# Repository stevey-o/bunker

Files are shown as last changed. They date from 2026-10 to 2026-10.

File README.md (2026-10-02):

# MINUTEMAN — aluminum slide-in camper shell

A rugged aluminum truck-camper **shell** for a Ford F-350 that provides the protected space and
attachment infrastructure while letting the owner decide what the camper eventually becomes.

**Status: v0.1 — envelope only.** No structural frame yet. Nothing here is engineering-validated;
CAD appearance is not engineering validation.

## Start here

| | |
|---|---|
| Spec (authoritative) | [`PROJECT_HANDOFF.md`](PROJECT_HANDOFF.md) |
| Design decisions | [`decisions/`](decisions/) |
| v0.1 dimensions | [`camper_versions/minuteman_v0.1_envelope/DIMENSIONS.md`](camper_versions/minuteman_v0.1_envelope/DIMENSIONS.md) |
| Truck measurement sheet | [`truck_data/measurement_templates/f350_measurement_sheet.md`](truck_data/measurement_templates/f350_measurement_sheet.md) |
| Assumptions & statuses | [`engineering/assumptions.md`](engineering/assumptions.md) |
| Renderings | [`3D_renderings/`](3D_renderings/) |
| Drawings (ANSI C, ASME Y14 style, MM-A01..A05) | [`drawings/`](drawings/) · [standards used](reference/drafting_standards.md) |
| Truck data and sources | [`truck_data/README.md`](truck_data/README.md) |

## Headline numbers (v0.1, estimates)

- **97" long** lower body (fills a 2011 F-350 8 ft bed with the tailgate closed, ADR 0004); 121" overall with the nose.
- Interior standing height **80"** (6'7"+), ground-to-roof **~10'7"** on a 2011 F-350 4x4 — tall, not low-profile.
- Dry weight estimate **985–1,231 lb excluding jacks**, over the 850–950 lb target. Jacks add 100–140 lb.
- Shell material cost estimate **$4,402–8,735 excluding jacks and tooling** vs. a $4–6k target. Jacks add $900–1,600.
- **Truck fit** ([fit study](truck_data/fit_study.md)): 8 ft F-350 OK (check payload sticker); 6.75 ft F-350 with tailgate down, F-150 5.5 ft and every Tacoma **fail** (CG behind axle, geometry, or payload).
- Each +1" of interior height costs ~6–7 lb and ~$26–50.

Full reports: [`bom/weight_report.md`](bom/weight_report.md), [`bom/cost_report.md`](bom/cost_report.md).

## Next physical action

Print [`f350_measurement_sheet.pdf`](truck_data/measurement_templates/f350_measurement_sheet.pdf), measure
the truck, update `cad/config/dimensions.json`, run `make all`.

## Building the outputs

```
make setup   # once
make all     # sync config, render, drawings, reports, validate
```

Requires OpenSCAD (`brew install --cask openscad@snapshot`; the stable `openscad` cask was disabled by
Homebrew on 2026-09-01 for failing Gatekeeper) and Python 3.9+.
`cad/config/dimensions.json` is the single source of truth; everything else is regenerated from it.

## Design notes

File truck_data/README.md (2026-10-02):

# Truck data

All truck values live in `cad/config/dimensions.json` (`truck` = 2011 F-350 base, `truck_variants` = per
truck overrides). This page records **where each number came from**. Accessed 2026-10-01.

## 2011 Ford F-350 Super Duty (design truck)

| Value | Used | Source / basis | Confidence |
|---|---|---|---|
| Bed length at floor, 8 ft / 6.75 ft | 98.0 / 81.8 in | Edmunds 2011 F-350 specs; cars.com (98 in) | published |
| Wheelbase, crew cab 6.75 / 8 ft | 156.2 / 172.4 in | Ford 2011 RV & Trailer Towing Guide, slide-in camper chart | official |
| Max camper cargo, 4x4 SRW crew 156.2 in WB | 1,650-2,905 lb by engine | Ford 2011 RV & Trailer Towing Guide p.13 (Camper Pkg 471 required) | official |
| Max camper cargo, 4x4 SRW crew 172.4 in WB | 1,438-3,002 lb by engine | same | official |
| Ground to top of closed tailgate | 59-60 in (F-350 SRW) | same guide, 5th-wheel tailgate clearance table | official |
| Inside box height | 20.0 in | ford-trucks.com 2011 spec summary; cars.com (20 in) | published |
| Between wheelhouses | 50.9 in | ford-trucks.com 2011 spec summary; cars.com (51 in) | published |
| Tailgate width | 61 in | ford-trucks.com spec summary (search excerpt; page blocked) | unconfirmed |
| Ground to bed floor | 39.5 in | 59.5 tailgate height − 20.0 box depth; 4x4 unloaded upper bound | derived |
| Cab roof above bed floor | 41.5 in | 80.8 in overall height (iseecars, crew 4x4) − 39.5 | derived |
| Rear axle aft of bed front wall | 35.0 (6.75) / 51.2 (8) in | Wheelbase difference = bed difference, so axle-to-tailgate is constant; Ford cab-to-axle 40 / 56.2 in (quoted from a Ford manual on a ford-trucks.com forum) less ~5.5 in cab gap + wall | derived, **measure** |
| Inside width at floor/top, rail width, wheel-well height/length | 66 / 6.5 / 10.5 / 34 in | No reliable 2011 figure found (2023+ Super Duty max inside width 66.9 in) | **estimate, measure** |

Ford's guidance (2011 guide p.13): camper CG data for each qualifying truck is printed on the **Consumer
Information Sheet** in the glovebox; trucks that do not qualify are marked "not recommended for camper use."
Ford also recommends a dimensionally stable spacer block between the bed headboard and the camper floor.

## Half-ton (fit study only)

Published bed data (armorthane.com truck bed dimension chart, from maker spec sheets):

| Truck | Box lengths at floor | Between wells | Depth | Notes |
|---|---|---|---|---|
| Ford F-150 (2021+) | 67.1 / 78.9 / 97.6 in | 50.6 | 21.4 | modeled as F150_55 / F150_65 |
| Chevrolet Silverado 1500 (2019+) | 69.9 / 79.4 / 98.2 | 50.6 | 22.4 | deeper box: body underside would clash |
| Ram 1500 (2019+) | 67.4 / 76.3 | 51.0 | 21.4-21.5 | tailgate opening 60.0 |
| Toyota Tundra (2022+) | 65.6 / 77.6 / 96.5 | 48.7 | 20.9 | tub base 49.4 does **not** fit between wells |

Payload: typical crew-cab 4x4 half-tons ~1,300-2,000 lb; the highest 2026 advertised figure is 2,440 lb (F-150).
Options can remove 600-700 lb of capacity on otherwise identical trucks (theweeklydriver.com, tfltruck.com).
Ford's 2011 guide allows F-150 campers only with the Heavy-Duty Payload Package (option 627).
**Estimates in the model:** bed floor height 35 in, cab roof 42 in above bed, tailgate opening 60 in, axle
positions (wheelbase difference = bed difference; absolute value not sourced).

## Toyota Tacoma (fit study only)

| Generation | Box lengths | Between wells | Depth | Payload |
|---|---|---|---|---|
| 2005-2015 (2nd) | ~60.5 / ~73.5 in | 41.5 | ~18 | — |
| 2016-2023 (3rd), modeled | 60.5 / 73.7 | 41.5 | 19.1 | 1,050-1,445 lb (2021) |
| 2024+ (4th) | 60.3 / 73.5 | 44.7 | 20.2 | up to 1,705 lb (5 ft, gas) |

Sources: armorthane.com chart; tustintoyota.com 2026 bed specs; kimboliving.com Tacoma bed dimensions by year;
earnhardttoyota.com 2021 guide. Truck Camper Adventure notes the Tacoma's axle sits far forward relative to the
bed, so a camper's CG generally cannot be brought over or ahead of it.
**Estimates in the model:** bed floor 33 in, cab roof 37.5 in above bed, tailgate opening 53 in, axle position.

## Camper CG and overhang guidance
- Truck Camper Adventure, "Truck Camper Center of Gravity: Getting it Right": CG in front of the rear axle;
  roughly 10-20% of camper weight on the front axle.
- Northern Lite fit guide: measure bed front wall to rear-axle center; the camper CG must be forward of that distance.
- Owner forums (Wander the West, Expedition Portal): campers that overhang the bed generally require the
  tailgate removed; long-bed campers on short beds move the CG behind the axle.
- Tailgates are typically rated ~200-500 lb and cables are rarely rated (SlashGear). Never a camper support.

## Files
- `fit_study.md`, `fit_matrix.csv`: generated verdicts per truck.
- `measurement_templates/f350_measurement_sheet.pdf`: the next physical action.
- `ford_f350/README.md`: notes specific to the owner's truck.

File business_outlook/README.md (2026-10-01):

# Business outlook

MINUTEMAN is first a personal build. This page records whether it could become a product. Each section
is short and honest: v0.1 has **no market validation**.

## Positioning
A DIY-buildable, open-interior aluminum hard-side shell for full-size trucks, sold as plans and/or a kit.
It sits below commercial empty shells ($17-21k, `competitors/modular_shells.md`) in cash cost and above
them in owner effort.

## Target customer
Tall people (6'4"+) who can't stand in most campers; owners who want to configure their own interior;
people with garage space and the patience to learn aluminum welding. Unvalidated.

## Market questions
- How many buyers would build from plans vs. pay for a kit vs. pay for a finished shell?
- Is "tall standing room" a real segment or one owner's need?
- Would buyers trust a DIY-welded structure on the highway? (Liability shapes everything here.)

## Manufacturing options
1. Plans only (lowest liability, lowest revenue).
2. Cut kit: CNC-cut sheet and pre-cut tube, owner assembles.
3. Kit with shop-welded nodes (removes the novice-welding risk).
4. Finished shell (requires a facility, certification questions, real insurance).

## Pricing model
Unknown. The reference points are $3.9-8k of materials and $17-21k commercial empty shells.

## Scalability
The parametric config makes other trucks a data change, not a redesign. Validation (testing, review)
does not scale for free.

## Risks
Structural liability; adhesive/joint durability; the novice-welding premise; weight over target; a small
niche; competitors already selling empty shells.

## Future products
High-low telescoping variant; larger cab-over; generic short/long-bed fitments; rail accessories.

**Status:** open questions only. Revisit after the first shell is built and validated (v1.0).

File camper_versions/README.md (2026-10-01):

# Camper versions

| Version | Folder | Status |
|---|---|---|
| v0.1 envelope | [minuteman_v0.1_envelope/](minuteman_v0.1_envelope/) | **Current: awaiting owner approval** |
| v0.2 structural frame candidate | not started | needs approval + truck measurements |
| v0.3 complete shell CAD | not started | |
| v0.4 prototype / fabrication candidate | not started | |
| future concepts | [future_concepts/](future_concepts/) | notes only |

v1.0 means a completed and validated **physical** shell, never "the CAD looks done."

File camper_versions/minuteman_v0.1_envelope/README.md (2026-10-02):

# MINUTEMAN v0.1: envelope

**Scope:** envelope solids only, with no structural frame. Global config architecture, simplified F-350
reference, lower tub, main body, 24 in nose, crowned roof, door/window/rail/boss placeholders, a 6'7"
reference figure, and truck clearance.

| Deliverable | Location |
|---|---|
| Dimension table | [DIMENSIONS.md](DIMENSIONS.md) |
| Exterior renders (7) | `3D_renderings/exterior/` |
| Truck fit renders (4) | `3D_renderings/truck_fit/` |
| Interior rails render | `3D_renderings/interior_shell/01_utility_rails.png` |
| MM-A01..A05 drawings (ANSI C) | `drawings/general_arrangement/`, `dimensions/`, `interior/`, `truck_fit/` |
| Fit study renders | `3D_renderings/fit_study/` |
| Measurement sheet | `truck_data/measurement_templates/f350_measurement_sheet.pdf` |
| Weight / cost | `bom/weight_report.md`, `bom/cost_report.md` |

## Findings worth a decision before v0.2
0. **Rev B (ADR 0004):** lower length 97 in to fill the 2011 F-350 8 ft bed with the tailgate closed. The fit study
   shows the 6.75 ft bed (tailgate down), F-150 5.5 ft and all Tacomas are **unsafe or don't fit**; see
   `truck_data/fit_study.md`. Product direction (8 ft only / shorter / family) is an open owner decision.
1. **Weight:** 985-1,231 lb excluding jacks; over the 850-950 lb target even at the low end.
2. **Cost:** $4,402-8,735 excluding jacks/tooling vs. the $4-6k target. Realistic 6061 tube pricing is the
   main reason the range exceeds the handoff's first pass.
3. **Height costs:** each +1 in of interior height adds ~6-7 lb and ~$26-50.
4. **5x10 sheets don't solve the sides:** at 80 in interior the body sides are 65.5 in tall, taller than
   a 60 in sheet, so every side needs a seam (or 72 in coil stock).
5. **Tub width set by the tailgate:** 59.5 in (2011 Super Duty ~61 in opening): the tub must pass the tailgate opening, not just fit between the rails.

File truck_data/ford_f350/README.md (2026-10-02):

# Ford F-350 (2011) notes

The model's base truck is a **2011 F-350 Super Duty crew cab 4x4 SRW**. Sourced values and their confidence
are in `../README.md`; every interface value stays **VERIFY ON TRUCK** until measured with
`../measurement_templates/f350_measurement_sheet.pdf`.

Things to confirm on the owner's truck first, because they move the design most:
1. **Which box** (6.75 or 8 ft) and cab style. The design assumes 8 ft.
2. **Rear axle position** (sheet row 6). This decides whether the CG works.
3. **Tailgate opening width** (row 14). It sets the tub width (59.5 in now).
4. **Ground to bed floor** (row 1) and **cab roof height** (row 11). They set travel height (~10'7") and nose clearance.
5. **Camper package (option 471)** and the **door-jamb payload / Consumer Information Sheet** CG data.

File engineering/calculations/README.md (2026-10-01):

# Calculations

Empty at v0.1: **nothing has been calculated.**

An assumption in `engineering/assumptions.md` may carry status `CALCULATED` only if its Reference column
cites a file in this folder, and `scripts_code/validate_model.py` fails the build otherwise.

Each calculation file states: load case, inputs (with their own statuses), method and reference
(e.g., Aluminum Design Manual section), HAZ allowables for welded joints, result, margin, and reviewer.

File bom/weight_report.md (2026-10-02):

<!-- GENERATED by scripts_code/generate_weight_report.py from cad/config/dimensions.json - DO NOT HAND-EDIT -->
# Weight report - v0.1 envelope

**Status: CONCEPT estimate.** Area-based coefficients, not a frame take-off. Replace in v0.2.

| Item | Low (lb) | High (lb) | Basis |
|---|---:|---:|---|
| Floor structure + tub | 230 | 293 | tub floor 33.3 ft2 |
| Wall frames | 133 | 177 | wall area 184.9 ft2 |
| Roof frame | 52 | 74 | roof area 61.7 ft2 |
| Nose frame | 49 | 70 | nose area 46.3 ft2 |
| Skin 5052 0.050" | 204 | 220 | 292.9 ft2 x t x density x laps |
| Insulation 1.5" XPS | 73 | 73 | insulated area x t x density |
| Interior panel | 105 | 135 | insulated area |
| Rear door | 45 | 70 | purchased |
| Windows (3) | 27 | 33 | purchased |
| T-slot utility rails (7) | 26 | 26 | registry length x lb/in |
| Hardware + adhesive | 40 | 60 | allowance |
| **Shell dry weight, excl. jacks** | **985** | **1231** | |
| Jacks (4), tracked separately | 100 | 140 | |
| **Shell incl. jacks** | **1085** | **1371** | |

## Against the target

Target dry weight: 850-950 lb.
Estimate excluding jacks: **985-1231 lb**; including jacks: **1085-1371 lb**.

**The 850-950 lb target is not reachable with this envelope.** Even the low estimate (985 lb, excluding jacks) is 35 lb over the top of the target. The full-length 97 in camper (ADR 0004) is the main reason. Levers: 0.040 in wall skin, lighter interior panel, or a shorter camper. This is an estimate, not a weighed result.

## Sensitivity: interior height

**Each +1 in of interior_height adds 5.8-7.0 lb and $26-50** (averaged over +/-4 in). For comparison, 80 in vs. a 76 in interior costs roughly 23-28 lb and $105-201. Skin sheet count moves in whole-sheet steps, so actual dollar changes are lumpy.

Payload reservations (not in dry weight): power zone 150 lb, roof rack + panels 120 lb (ADR 0003).

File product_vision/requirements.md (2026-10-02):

# Requirements

Status key: **FIXED** (owner requirement) · **TARGET** (goal, may be missed) · **CONSTRAINT** (physics / law / truck).

| ID | Requirement | Type | v0.1 status |
|---|---|---|---|
| R-01 | Fills a 2011 F-350 8 ft bed with the tailgate closed (ADR 0004) | FIXED | Met: 97 in, .5 in to tailgate; VERIFY ON TRUCK |
| R-01a | Fits a 6.75 ft F-350 with the tailgate down, if safe | FIXED (conditional) | **Not met:** loaded CG ~8 in behind rear axle |
| R-01b | Fits half-ton trucks and the Tacoma, overhanging if safe | FIXED (conditional) | **Not met** safely; F-150 6.5 ft marginal on payload; Tacoma fails geometry + payload |
| R-02 | Interior standing height for a 6'7"+ person (80 in clear) | FIXED | Met in envelope |
| R-03 | Low drag, clean styling ("sleek") | TARGET | Raked nose, R3 corners, flush placeholders |
| R-04 | Dry weight 850-950 lb | TARGET | **Not met:** estimate 985-1,231 lb excl. jacks |
| R-05 | Material cost ~$4,000-6,000 ("high-end topper") | TARGET | **Partly:** estimate $4,402-8,735 excl. jacks/tooling |
| R-06 | Buildable by a novice aluminum welder | FIXED | ADR 0001 rules adopted |
| R-07 | One rear entry door, limited windows | FIXED | Placeholders: 1 door, 2 side + optional nose window |
| R-08 | Four camper-jack attachment structures | FIXED | v0.2 |
| R-09 | Truck tie-down structures; tailgate not structural | FIXED | v0.2 |
| R-10 | Interior T-slot utility rails (3 left, 3 right, 1 front) | FIXED | Placeholders placed |
| R-11 | Roof-rack bosses on crossmembers; wire chase; power floor zone | FIXED | Placeholders / reserved geometry |
| R-12 | Insulated walls and roof; interior protective panel | FIXED | Thickness allowances only |
| R-13 | Watertight; every exterior joint detailed | FIXED | v0.3 details |
| R-14 | Legal width (<= 102 in) | CONSTRAINT | 80 in |
| R-15 | Lower tub passes the tailgate opening and clears wheel wells | CONSTRAINT | Checked by validate_model.py; VERIFY ON TRUCK |
| R-16 | CG forward of rear axle; within truck payload / GAWR | CONSTRAINT | Proxy only; v0.2 calculation |
| R-17 | Out of scope: plumbing, electrical systems, HVAC, furniture, bed, kitchen | FIXED | None in model |

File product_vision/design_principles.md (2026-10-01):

# Design principles

## Priorities, in order
1. Safety
2. Structural integrity
3. Water resistance
4. Low weight
5. Simplicity
6. Low cost
7. Repairability
8. Configurability
9. Ease of fabrication
10. Appearance

When two solutions perform similarly, prefer the one that is easier to understand, cut, assemble,
repair, replace, document, and modify later, and that depends on fewer specialized tools.

## Rules that follow from them
- **Weld little, weld thick.** Owner welds only small safety-critical nodes, never thinner than 0.125 in
  wall, sized on heat-affected-zone allowables (ADR 0001). Everything else is bolted, riveted, bonded.
- **Loads go into structure.** Jacks, tie-downs, roof rack, and power zone attach to primary members, never skin.
- **Skin is structure, not decoration.** It is bonded as a shear diaphragm, never continuously welded.
- **Water first.** Every exterior joint gets a waterproofing detail; no screw penetrations as primary
  roof attachment; positive roof drainage.
- **"Sleek" means low drag**, not low height (ADR 0002): flush skins, radiused corners, raked nose, no bulges.
- **One source of truth.** A dimension lives in `dimensions.json` once; drawings, BOM, and manual are generated.
- **Honest numbers.** Estimates are labeled estimates; an aspiration is never reported as achieved.

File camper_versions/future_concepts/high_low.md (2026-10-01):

# Future concept: high-low (telescoping) MINUTEMAN

**Status: concept note only. Does not influence v0.1.**

The owner wants both a low travel height and 6'7" standing room. A fixed hard-side cannot do both
(ADR 0002). A telescoping upper section can: Alaskan Campers has done it hydraulically for decades
(`competitors/aluminum_campers.md`).

## What it would take
- A rigid lower shell plus a sliding upper hard shell with a seal at the overlap.
- A lift mechanism (hydraulic, electric actuator, or gas-strut assist with manual lift) and locks at both positions.
- An overlap seal that survives dust, water, and cold. This is the hard engineering problem.
- Extra weight and mechanism cost: **not estimated.** An unsupported guess is 150-300 lb; do not use it for decisions.

## Payoff
Travel height could drop substantially (rough guess 20-30 in, depending on overlap and nose design), with the full 80 in interior when raised.

## Open questions
- Would the owner accept manual raising?
- Does T-slot rail placement on the upper walls still work when it telescopes?
- Is the nose part of the moving section?

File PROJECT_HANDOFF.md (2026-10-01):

# MINUTEMAN CAMPER — HANDOFF FOR CLAUDE CODE

**Repo:** `bunker` (https://github.com/stevey-o/bunker) · **Local:** `/Users/cree/Documents/bunker-camper`
**Owner/builder:** Steven Orlik · **Product codename:** MINUTEMAN · **Current target:** v0.1 ENVELOPE ONLY
**Status of this document:** authoritative. It supersedes any earlier verbal spec where the two conflict.

---

## 0. READ THIS FIRST

You are picking up a project that has had one planning pass. Three decisions were already made after the
original spec was written, because the original spec contained requirements that were **physically
impossible or mutually contradictory**. They are recorded in §2. Do not re-litigate them and do not
silently revert to the original spec's numbers.

Your job right now is narrow:

1. Scaffold the repository (§5).
2. Build the parametric config architecture (§6).
3. Build the **v0.1 envelope** model and its deliverables (§10).
4. **STOP at the approval gate (§11).** Do not begin detailed structural frame design.

The single most common way to fail this task is to start designing the frame. v0.1 is envelope solids
only. Another way to fail is to create hundreds of empty placeholder files; every document you create
should contain real content or an explicit, honest list of open questions.

---

## 1. WHAT MINUTEMAN IS

A DIY aluminum slide-in truck camper **shell** for a Ford F-350. Shell only.

> A rugged aluminum truck-camper shell that provides the protected space and attachment
> infrastructure while allowing the owner to decide what the camper eventually becomes.

The shell must be useful on the day it is finished even if nothing is installed inside it.

**Explicitly out of scope:** shower, toilet, permanent bed, kitchen, sink, plumbing, water tanks,
propane, refrigerator, permanent cabinetry, electrical system, wiring, charge controllers, batteries,
solar panels, HVAC, entertainment, luxury finishes, and any assumption about interior layout.

**In scope:** structural floor, aluminum frame, bonded aluminum skin, insulated walls and roof, interior
protective panel, one rear entry door, limited windows, four camper jack attachment structures, truck
tie-down structures, interior T-slot utility rails, and *structural provisions* for a roof rack and a
battery/generator bay (see §2.3).

### Design priorities, in order

Safety → structural integrity → water resistance → low weight → simplicity → low cost →
repairability → configurability → ease of fabrication → appearance.

When two solutions perform similarly, prefer the one that is easier to understand, cut, assemble,
repair, replace, document, and modify later, and that depends on fewer specialized tools.

---

## 2. RESOLVED DECISIONS (do not revert)

### 2.1 Welding: aluminum GMAW with a spool gun — and the design bends to suit a novice

The owner asked for "self-shielded flux-core MIG" on aluminum. **That does not exist.** There is no
self-shielded flux-cored aluminum wire on the market; aluminum requires inert gas coverage, and
flux-cored processes depend on slag chemistry that does not work against aluminum's oxide layer. The
owner's clarified requirement was "whatever I need for strong, cheap, beginner-friendly aluminum
welding," which resolves to:

- **Process:** GMAW (MIG) with a **spool gun**, 100% argon at 25–35 CFH.
- **Machine class:** 200–230 A (e.g. Hobart Handler 210MVP + SpoolRunner 100, Eastwood MIG 180,
  Primeweld MIG 230). Budget **$800–1,400** one-time tooling, tracked in `time_cost/tooling_costs.csv`,
  never in the shell material cost.
- **Wire:** ER5356, 0.035". Push angle, fast travel, no preheat under 1/4".

Two consequences that **must** propagate into the CAD and the engineering docs:

- **Minimum wall thickness for any owner-welded member is 0.125".** The original spec's
  1×1×0.083" tube will burn through for a novice. 0.083" wall is therefore restricted to
  **bolted/bonded** secondary framing only. Encode this as a hard rule in `validate_model.py`.
- **Welded 6061-T6 loses roughly 40% of its yield strength in the heat-affected zone** (about 40 ksi
  down into the mid-20s ksi, effectively annealed). Every welded joint must be sized on HAZ-reduced
  allowables. Record this in `engineering/assumptions.md` with status `MANUFACTURER VERIFIED` once a
  datasheet is cited, `CONCEPT` until then.

This is the reason the architecture is **HYBRID**: weld only the small safety-critical nodes (jack
boxes, tie-down nodes, floor corner nodes) where a local shop could also do the work, and bolt, rivet,
and bond everything else. Keep `FRAME_SYSTEM` switchable between `"HYBRID"`, `"BOLTED_TUBE"`, and
`"TSLOT"` so all three remain evaluable from one envelope.

### 2.2 Height: 80" interior standing height; "sleek" means aerodynamic, not short

The owner needs standing room for a **6'7" person or taller**, so `interior_height = 80`. The owner also
asked for a "lowish profile." **These cannot both be satisfied in a slide-in camper.** Stack-up on an
F-350:

| Element | Value (in) |
|---|---|
| Ground to bed floor | ~34 (VERIFY ON TRUCK) |
| Floor sandwich | ~3 |
| Interior clear height | 80 |
| Roof structure + skin | ~3.5 |
| **Ground to roof** | **~120.5 (10'0.5")** |

That is a tall camper, in the normal range for hard-side truck campers but nowhere near low-profile.
Therefore **low profile is reinterpreted as low drag and clean styling**, not reduced height: minimum
frontal area, flush bonded skins with no protruding fasteners, generously radiused vertical corners, a
raked/tapered nose over the cab, and no bulges or "ears."

The pop-up/telescoping "high-low" variant the owner wants is **a separate future model**. Put a concept
note in `camper_versions/future_concepts/high_low.md` and do not let it influence v0.1.

Make `interior_height` fully parametric and have `generate_weight_report.py` emit a **sensitivity line**
showing lb and $ per inch of height, so the owner can see exactly what the 6'7" requirement costs.

### 2.3 Solar and battery: structural provisions only, zero system design

The owner wants a roof rack for solar and an internal battery/solar generator; the spec forbids
designing electrical systems. Both are satisfied by designing **only the structure**:

- Roof-rack mounting bosses that land on roof crossmembers, never on bare skin.
- A wire chase path through the wall/roof cavity, reserved as geometry.
- A reinforced floor zone with T-slot tie-down capability for a battery or solar generator, sized by
  mass and footprint only.

No panels, no wiring, no controllers, no loads, no capacity math. Record the reserved masses as
payload assumptions in `engineering/assumptions.md`.

### 2.4 Cost: the skin dominates, and the target is tight

Owner's target is "ballpark of a high-end truck topper," i.e. **$4,000–6,000**, consistent with the
spec's $5,000–7,000. First-pass reality, **excluding jacks and tooling**:

- 5052 sheet, ~10 sheets of 4×8 at 0.050": **$1,300–2,300** ← largest single line item
- 6061 tube: $500–900 · T-slot: $250–500 · door: $400–900 · windows: $300–600
- Insulation: $150–250 · adhesive/sealant: $150–300 · fasteners/rivets: $200–350
- Interior panel: $200–400 · welding consumables and gas: $150–300
- **Subtotal ≈ $3,600–6,800.** Jacks add $900–1,600 and are tracked separately.

`time_cost/cost_reduction_opportunities.md` must open with the real levers: 0.040" skin on walls with
0.050" reserved for the roof, 5×10 sheets to eliminate seams and offcuts, surplus and remnant sourcing,
and a commercial cargo-trailer door instead of custom fabrication. It must also state where cost must
**not** be cut: jack structures, tie-down nodes, floor structure, adhesive quality.

### 2.5 Weight: state the honest number, not the aspirational one

Spec target is 850–950 lb dry. First-pass build-up, excluding jacks:

floor 180–230 · wall frames 120–160 · roof frame 50–70 · nose frame 35–50 · skin 190–210 ·
insulation ~60 · interior panel 85–110 · door 45–70 · windows ~30 · T-slot rails ~18 ·
hardware and adhesive 40–60 → **≈ 860–1,060 lb**, plus 100–140 lb for four jacks.

Conclusion to write down plainly: the 850–950 lb target is reachable only without jacks and only with
disciplined interior paneling. Interior panel and skin thickness are the two biggest levers. Do not
report a weight as achieved when it is an aspiration.

---

## 3. ENVIRONMENT (already verified on this machine)

- macOS (darwin 25.3.0), zsh, Homebrew 6.0.21 at `/opt/homebrew`.
- **OpenSCAD is NOT installed** → `brew install --cask openscad`. Verify the CLI binary at
  `/Applications/OpenSCAD.app/Contents/MacOS/OpenSCAD` and wrap its path in a Python constant.
- Python is **system 3.9.6 only**, with no third-party modules → create `.venv`. The **only** dependency
  is `reportlab` (pure Python, draws PDF directly, no system libs). Do not add cairo/svglib/matplotlib.
- **`gh` is NOT installed anywhere** — not in Homebrew, not in `/opt/pmk/env/global/bin`, not in any
  project's `node_modules/.bin`, and there is no `~/.config/gh`. It is **not needed** for pushing.
- **Git auth already works over HTTPS.** `credential.helper = osxkeychain` is set in the *system*
  gitconfig (not global, which is why it is easy to miss), and a github.com credential for account
  `202304373` resolves via `git credential fill`. The owner's other repos (`stevey-o/social-circles`,
  `stevey-o/web-scraper`) use the same mechanism.
- Git identity is already set globally: `Steven Orlik <steven.orlik5@gmail.com>`.
- Remote to add: `git remote add origin https://github.com/stevey-o/bunker.git`, branch `main`. The
  repo exists and is empty. **Make a scaffold commit and push early** to prove the token's scopes before
  a large amount of work is sitting unpushed. If the push fails on scope or expiry, fall back to
  `brew install gh && gh auth login`.

**Units are inches throughout.** Degrees for angles, pounds for mass, USD for cost. No metric anywhere
in the model or reports except where a purchased component's datasheet is metric, in which case convert
and cite.

---

## 4. HARD RULES

- Never silently promote a `CONCEPT` assumption to a verified fact. Use the §8 status system.
- Never attach a safety-critical load to exterior skin, decorative panel, thin sheet, a single T-nut, or
  lightweight trim. Jacks and tie-downs terminate in structural members, full stop.
- Never continuously weld thin exterior skin to the frame. Skin is **bonded** with structural
  adhesive plus selective rivets, acting as a shear diaphragm.
- Never rely on exposed screw penetrations as the primary roof attachment system.
- Do not assume the tailgate is a structural camper support.
- Do not place furniture, a bed, a kitchen, batteries, or water in the model.
- Do not create a second naming system for any document. One part ID appears everywhere (§7).
- Do not hand-edit generated files (`cad/config/dimensions.scad`, everything in `bom/` and `output/`).
  Edit the source and regenerate.
- Every exterior joint gets a waterproofing detail. Every aluminum-to-dissimilar-metal interface gets a
  galvanic isolation note.
- Write a `CLAUDE.md` at the repo root during scaffolding that restates these hard rules, the units
  convention, the part ID grammar, and the "regenerate, don't hand-edit" rule, so future sessions
  inherit them automatically.

---

## 5. REPOSITORY LAYOUT

Initialize git at the workspace root and lay the tree out **directly at the root** (not nested inside a
`Minuteman-Camper/` subdirectory). There is exactly one product today; if the high-low model ever
becomes real, move things into `models/` with a `git mv` then.

```
bunker-camper/
├── README.md                  PROJECT_HANDOFF.md (this file)   CLAUDE.md
├── CHANGELOG.md               Makefile                         .gitignore
├── decisions/                 numbered ADRs; 0001-welding, 0002-height, 0003-solar-provisions
├── product_vision/            vision, design_principles, requirements, shell_scope,
│                              owner_configurability, future_roadmap
├── camper_versions/           minuteman_v0.1_envelope … v0.4_prototype, future_concepts/
├── cad/
│   ├── main.scad  truck_reference.scad  camper_envelope.scad
│   ├── config/    dimensions.json (MASTER)  dimensions.scad (GENERATED)
│   │              materials.scad  profiles.scad  hardware.scad  build_variant.scad  part_ids.md
│   ├── frame/     floor, left/right/front/rear_wall, roof, nose, jack_structure, tiedowns
│   ├── profiles/  square_tube, rectangular_tube, tslot_20/30/40
│   ├── joints/    angle_bracket, gusset, joining_plate, tnut, through_bolt
│   ├── skin/      left, right, front, rear, roof
│   ├── utility_rails/   left_wall_rails, right_wall_rails, front_wall_rail
│   └── purchased_components/  door, windows, jacks
├── drawings/        general_arrangement, dimensions, frame, floor, walls, roof, nose,
│                    utility_rails, jack_mounts, tiedowns, joints, sheet_metal,
│                    waterproofing, truck_fit
├── 3D_renderings/   exterior, interior_shell, frame, exploded, truck_fit, utility_rails,
│                    joints, assembly_steps
├── scripts_code/    sync_config.py  render_all.py  render_steps.py  generate_bom.py
│                    generate_cutlist.py  generate_weight_report.py  generate_cost_report.py
│                    generate_manual.py  validate_model.py  export_drawings.py
├── bom/             master_bom.csv  frame_cutlist.csv  extrusion_cutlist.csv  sheet_cutlist.csv
│                    fasteners.csv  purchased_components.csv  suppliers.csv
├── manual/          build_manual.md  steps/  diagrams/  inspections/  testing/
├── engineering/     assumptions.md  load_paths.md  structural_questions.md  calculations/
│                    manufacturer_data/  joint_testing/  water_testing/  engineering_review/
├── truck_data/      ford_f350/  generic_short_bed/  generic_long_bed/  measurement_templates/
├── time_cost/       project_budget.md  material_costs.csv  tooling_costs.csv  labor_estimate.csv
│                    build_timeline.md  sourcing.md  cost_reduction_opportunities.md
├── competitors/     kimbo, aluminum_campers, composite_campers, diy_builds, modular_shells,
│                    comparison_matrix.csv
├── business_outlook/  positioning, target_customer, market_questions, manufacturing_options,
│                    pricing_model, scalability, risks, future_products
├── reference/       inspiration/  manufacturer_catalogs/  material_datasheets/
│                    fastener_datasheets/  adhesives/  source_links.md
└── output/          current_design/  drawings/  renderings/  manual/  bom/  release_packages/
```

`.gitignore` covers `.venv/`, `output/`, `__pycache__/`, `.DS_Store`. Generated renderings and drawings
**are** committed (they are review artifacts the owner looks at on GitHub); `output/` staging is not.

---

## 6. SINGLE SOURCE OF TRUTH

`cad/config/dimensions.json` is the **master**. `scripts_code/sync_config.py` generates
`cad/config/dimensions.scad` from it. The Python reporting scripts read the same JSON. A dimension can
therefore never disagree between model, drawings, BOM, weight report, and manual.

```
dimensions.json ──sync_config.py──> dimensions.scad ──> main.scad + modules
       │                                                      │
       │                                         ┌────────────┴────────────┐
       │                                   render_all.py            echo() metadata
       │                                   (OpenSCAD CLI)                  │
       │                                         │                  output/current_design/parts.json
       │                                   3D_renderings/**                │
       │                                                      ┌────────────┼────────────┐
       └──> export_drawings.py ──> drawings/**.pdf      generate_bom  cutlist  weight_report
                                                              └────────────┼────────────┘
                                                                     bom/*.csv ──> cost_report
                                                                           └──> generate_manual.py
```

**The parts registry is the key mechanism.** Every `frame_member()` and `utility_rail()` call `echo()`s
its own metadata — part ID, profile, material, length, position, rotation, computed mass, cost key.
`render_all.py` captures OpenSCAD's stdout and parses it into `output/current_design/parts.json`, which
feeds the BOM, cut list, and weight report. This is what makes CAD changes propagate automatically
instead of requiring a human to retype numbers into spreadsheets.

Module signature concept:

```scad
frame_member(
    id       = "WALL-L-V03",
    profile  = "TUBE_1X1_125",
    material = "AL6061T6",
    length   = 42,
    position = [x, y, z],
    rotation = [0, 0, 0],
    join     = "WELDED"        // or "BOLTED" / "BONDED" — drives the 0.125" min-wall check
);
```

Do not scatter literal dimensions through the `.scad` files. Everything references config variables.
Do not write one enormous `.scad` file; use small reusable modules.

Starting parameter values, all parametric:

```
camper_lower_length   = 78     camper_body_width = 80     interior_height = 80
nose_projection       = 24     skin_thickness    = 0.050  floor_sandwich  = 3.0
utility_rail_left_count = 3    utility_rail_right_count = 3   utility_rail_front_count = 1
FRAME_SYSTEM = "HYBRID"
```

Truck interface parameters, **all flagged VERIFY ON TRUCK**: `truck_bed_length`,
`truck_bed_floor_width`, `truck_bed_rail_width`, `truck_bed_rail_height`,
`truck_tailgate_opening_width`, `truck_wheel_well_width`, `truck_wheel_well_height`,
`truck_cab_height_above_bed`, `truck_cab_to_bed_clearance`, `camper_to_cab_clearance`,
`camper_lower_tub_width`, `camper_lower_tub_height`.

Preliminary F-350 reference values to seed the model (**every one VERIFY ON TRUCK**): bed floor ~34"
above ground, bed depth / rail height ~20.4", inside bed width ~69.3" at the top, ~50.6" between wheel
wells, 6.75 ft bed length ~81.9", 8 ft bed length ~98.0", cab roof ~46" above bed floor.

Key geometric relationship to honor: the **lower tub** must fit *between* the bed rails (≈68" max
width), while the **body** widens to 80" and sits above bed-rail height. The same camper must fit both
a ~6.5 ft and an 8 ft bed; unused bed length on the 8 ft truck is acceptable.

---

## 7. PART IDENTIFICATION

Grammar: `SYSTEM-LOCATION-NUMBER`. Define it once in `cad/config/part_ids.md` and enforce it in
`validate_model.py`, which must fail the build on a duplicate or malformed ID.

```
FLR-L-001  FLR-R-001  FLR-X-001        floor longitudinal / rail / crossmember
WALL-L-V01  WALL-L-H01                 wall vertical / horizontal
ROOF-X-01   NOSE-L-01
UTIL-L-01  UTIL-R-02                   owner accessory T-slot rails
JACK-LF-01  JACK-RF-01  JACK-LR-01  JACK-RR-01
SKIN-L-01  SKIN-R-01  SKIN-ROOF-01
```

The same ID must appear in CAD, drawings, BOM, cut list, renderings, manual, cost report, and weight
report. Keep **PRIMARY STRUCTURAL FRAME** and **OWNER ACCESSORY T-SLOT RAIL** clearly distinguished;
a member may serve both roles only deliberately and only with a note.

---

## 8. ENGINEERING STATUS SYSTEM

Every important structural assumption carries exactly one status:

`CONCEPT` · `CALCULATED` · `MANUFACTURER VERIFIED` · `PHYSICALLY TESTED` ·
`PROFESSIONALLY REVIEWED` · `NEEDS REVIEW`

At v0.1 nearly everything is `CONCEPT` or `VERIFY ON TRUCK`. `validate_model.py` must refuse to accept a
`CALCULATED` status unless a corresponding file exists in `engineering/calculations/`.

**Safety-critical list** requiring particular attention as the project progresses: floor structure, jack
mounts, jack stability, tie-downs, nose cantilever, major joints, fastener shear and tension, T-slot
slip, bracket rotation, skin shear transfer, adhesive compatibility, fatigue, road vibration, truck
clearance, center of gravity, payload, rear axle loading, tire loading. **CAD appearance is not
engineering validation.** Say so in `engineering/assumptions.md`.

---

## 9. OUTPUT CONVENTIONS

**Renderings** — repeatable named cameras, consistent colors:

| Element | Color |
|---|---|
| Existing assembly | light gray |
| New frame pieces | blue |
| Brackets | orange |
| Fasteners | red |
| Skin | silver |
| Insulation | yellow |
| Adhesive / sealant | green |
| Utility T-slot rails | dark blue |
| Truck reference | transparent gray |

Standard views: rear iso, front iso, left, right, front, rear, top, bottom, interior forward, interior
rearward, frame-only, skin-only, exploded, truck installation.

**Drawings** — true engineering drawings, not pretty renders: white background, black/gray linework,
dimension arrows, inch dimensions, section and detail callouts, part IDs, title block, revision number,
scale, notes, legend. Dimensions that depend on the physical truck must be visibly tagged
**VERIFY ON TRUCK**. Eventual full set: A01, A02, F01–F02, W01–W04, R01, N01, U01–U02, J01–J02, T01,
S01–S05, E01–E02.

**Manual** — LEGO Technic / IKEA style, not a textbook. Each step gets a number, parts required,
hardware required, tools required, one large isometric image, new components highlighted, part IDs,
orientation arrows, important dimensions, a detail view if needed, and an inspection check before
continuing. Never hide five fabrication operations inside one instruction.

**Development loop:** MODEL → RENDER → INSPECT → CORRECT → DOCUMENT → COMMIT. Commit meaningful
milestones. Never overwrite known-good geometry without revision history.

---

## 10. v0.1 SCOPE AND DELIVERABLES

**Envelope solids only. No detailed structural frame.** v0.1 contains: global config architecture,
material definitions, simplified F-350 bed and cab reference in transparent gray, camper lower-tub
envelope, main body envelope, ~24" nose envelope, roof envelope with positive drainage crown, rear door
placeholder, window placeholders (2 side + optional nose), interior T-slot utility rail placeholders,
roof-rack boss placeholders, a **6'7" human reference figure**, major dimensions, and truck/camper
clearance visualization.

The nose is additional enclosed volume and future storage/desk space. **Do not engineer it to support
two sleeping adults.** A larger cab-over is a separate future structural revision.

Required files:

```
3D_renderings/exterior/01_rear_iso.png       05_front.png
3D_renderings/exterior/02_front_iso.png      06_rear.png
3D_renderings/exterior/03_left.png           07_top.png
3D_renderings/exterior/04_right.png
3D_renderings/truck_fit/01_short_bed.png     03_side_clearance.png
3D_renderings/truck_fit/02_long_bed.png      04_cab_clearance.png
3D_renderings/interior_shell/01_utility_rails.png
drawings/general_arrangement/A01_general_arrangement.pdf
drawings/dimensions/A02_major_dimensions.pdf
drawings/truck_fit/A03_truck_fit.pdf
camper_versions/minuteman_v0.1_envelope/DIMENSIONS.md
```

`DIMENSIONS.md` must list **every** major design dimension, each tagged exactly one of:
**FIXED** · **PARAMETRIC** · **PRELIMINARY** · **VERIFY ON TRUCK**.

Also produce in this pass: `truck_data/measurement_templates/f350_measurement_sheet.md` — a printable
sheet the owner takes to the truck with a tape measure, listing every VERIFY ON TRUCK dimension with
space to write the real number and a diagram reference. This is the owner's next physical action, so
make it genuinely usable.

### Suggested execution order

1. Scaffold tree, `.gitignore`, `Makefile`, `README.md`, `CLAUDE.md`, `CHANGELOG.md`; add remote; commit
   and **push** to verify auth.
2. Install OpenSCAD; create `.venv` with `reportlab`; verify CLI PNG export and 2D projection work.
3. Write `decisions/0001`–`0003` from §2.
4. Build `dimensions.json`, `materials.scad`, `profiles.scad`, `hardware.scad`, `build_variant.scad`,
   `sync_config.py`.
5. Write `truck_reference.scad`, `camper_envelope.scad`, placeholders, human reference, `main.scad`
   view switching.
6. Implement the `echo()`-based parts registry and `parts.json` capture.
7. `render_all.py` + the 12 renderings.
8. `export_drawings.py` + A01/A02/A03.
9. `generate_weight_report.py`, `generate_cost_report.py`, `generate_bom.py`,
   `generate_cutlist.py`, `validate_model.py`; seed `bom/` and `time_cost/` CSVs with the §2.4/§2.5
   first-pass numbers.
10. Write the prose docs: `product_vision/`, `engineering/`, `competitors/` (Kimbo, Four Wheel Camper,
    Alaskan, Total Composites, Scout, plus DIY builds — with source URLs and access dates),
    `truck_data/`, `time_cost/`, `business_outlook/`, `manual/` skeleton.
11. `DIMENSIONS.md` and the measurement sheet.
12. Commit, push, present, **stop**.

---

## 11. APPROVAL GATE — STOP HERE

After v0.1 is committed and pushed, present to the owner:

1. The repository tree.
2. The dimension table.
3. Exterior renderings (embedded inline).
4. The interior-shell rendering showing utility rails.
5. Short-bed truck fit.
6. Long-bed truck fit.
7. The dimensioned general arrangement drawing.
8. The list of unresolved dimensions.
9. The list of assumptions requiring physical truck measurements.

Then **wait**. Do not begin v0.2 structural frame development without explicit approval. Do not label
anything v1.0 merely because the CAD looks complete — v1.0 means a completed and validated physical
shell.

Version ladder: v0.1 envelope → v0.2 structural frame candidate → v0.3 complete shell CAD →
v0.4 prototype/fabrication candidate → v0.5 changes discovered during physical construction →
v1.0 completed and validated first shell.

---

## 12. WHAT THE FINISHED v0.1-THROUGH-v0.4 PROJECT OWES THE OWNER

Not required for the v0.1 gate, but this is the destination, so do not architect anything that makes it
harder to reach: verified envelope, truck-fit model, complete frame/floor/wall/roof/nose CAD, rear door,
window openings, bonded aluminum skin, interior T-slot rails, jack structures, tie-down structures,
waterproofing details, thermal/insulation concept with thermal bridging documented, dimensioned
drawings, exploded drawings, part IDs, three cut lists, fastener BOM, purchased-component BOM, weight
report, cost report, fabrication-time estimate, truck-fit checklist, structural-review checklist,
water-test procedure, assembly renderings, and the LEGO-style construction manual.

Plus test plans, because small tests are cheaper than a wrong camper: T-slot joint slip, T-slot joint
rotation, frame racking, frame-plus-skin racking, adhesive bonding, riveted skin, representative corner
waterproofing, roof/wall joint waterproofing, and jack attachment structure.

**The CAD model, BOM, drawings, cut list, and manual must all describe the same camper.**

---

## 13. CORE PRINCIPLE

Minuteman is not initially a finished RV. It is a durable, weatherproof, lightweight, configurable
aluminum platform. Build the shell correctly first. Leave the interior open. Provide strategically
placed T-slot infrastructure. Let the owner evolve the camper over years rather than forcing every
decision on day one.

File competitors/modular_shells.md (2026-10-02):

# Modular and "empty shell" offerings

MINUTEMAN's concept is a shell that is useful empty and grows over time. Commercial versions of that idea:

| Product | What "shell" means | Price | Source |
|---|---|---|---|
| Total Composites Lynx 7' | Empty FRP shell | $17,959 | TCM buyer's guide (link in composite_campers.md) |
| Four Wheel Camper Hawk Base | Shell with minimal interior | from $19,995 | fourwheelcampers.com (link in aluminum_campers.md) |
| Kimbo 6 Base | Stripped aluminum hard-side | from $20,999 | TCM buyer's guide (link in kimbo.md) |
| Scout Yoho | Modular interior, removable gear | $19,240 | New Atlas (link in composite_campers.md) |

**Takeaway:** commercially, an empty or near-empty hard shell costs **$17,000-21,000**. MINUTEMAN's
$4,400-8,700 material estimate (excluding jacks, tooling, and labor) is the DIY value proposition. The
owner's labor (roughly 163-314 h, `time_cost/labor_estimate.csv`) is the price paid for the difference.

## Open questions
- Do any of these sell T-slot or rail-based interior attachment as a feature? (Scout's modular approach is
  closest.)
- What do empty-shell buyers most often add first? That would inform which provisions matter.

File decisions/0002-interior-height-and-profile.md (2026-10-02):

# ADR 0002 — 80" interior height; "sleek" means low drag, not low height

**Status:** Accepted (v0.1) · **Source:** PROJECT_HANDOFF.md §2.2

## Context
The owner needs standing room for a person 6'7" (79") or taller and also asked for a "lowish profile."
In a slide-in camper these cannot both be met. The interior floor sits on the bed floor, which is
already ~34" off the ground on an F-350.

| Element | Value (in) |
|---|---|
| Ground to bed floor | ~39.5 on a 2011 F-350 4x4 (VERIFY ON TRUCK; was ~34 in the first pass) |
| Floor sandwich | ~3 |
| Interior clear height | 80 |
| Roof structure + skin | ~3.5 (+0.75 drainage crown at centerline) |
| **Ground to roof (eave / crown)** | **~126.0 / ~126.75 (≈10'7")** |

## Decision
- `interior_height = 80`, fully parametric.
- "Low profile" is reinterpreted as **low drag and clean styling**: minimum frontal area, flush bonded
  skins with no protruding fasteners, generously radiused vertical corners, a raked nose over the cab,
  no bulges or "ears."
- A pop-up / telescoping high-low variant is a **separate future model**
  (`camper_versions/future_concepts/high_low.md`) and does not influence v0.1.
- `generate_weight_report.py` and `generate_cost_report.py` emit a sensitivity line: lb and $ per inch
  of interior height, so the cost of the 6'7" requirement is visible.

## Consequences
At ~10'7" the camper is in the normal range for hard-side truck campers but is tall. Low bridges,
parking garages, drive-throughs, and some fuel-station canopies become route considerations. The
center of gravity rises, which matters for v0.2 stability work.

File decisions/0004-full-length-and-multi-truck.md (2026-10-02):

# ADR 0004 — Full 8 ft length; design truck = 2011 F-350; multi-truck fit is checked, not assumed

**Status:** Accepted for the length change. **Multi-truck product direction: OPEN, owner decision needed.**
**Date:** 2026-10-01

## Owner request
1. The camper should fill the whole 8 ft bed with the tailgate shut.
2. On a shorter (~6 ft) bed it should fit with the tailgate down.
3. Use 2011 F-350 dimensions.
4. Fit half-ton trucks and the Toyota Tacoma as well, hanging off the back if safe.

## Decision
- `camper_lower_length = 97.0 in` (FIXED): 98.0 in 2011 Super Duty 8 ft box − 0.5 in front gap − 0.5 in
  to the closed tailgate. Overall length with the 24 in nose: 121 in.
- **Design truck = 2011 F-350 crew cab 4x4 SRW, 8 ft box** (`DESIGN_TRUCK = F350_LONG`). The camper
  geometry is derived from this truck only and never changes shape with the truck shown. Every other
  truck is a *fit check* (`scripts_code/generate_fit_study.py`, `truck_data/fit_study.md`).
- Lower tub width reduced 63 → 59.5 in: the 2011 Super Duty tailgate is ~61 in wide (VERIFY ON TRUCK).
- The tailgate is still never structural. "Tailgate down" means the camper floor cantilevers past the bed end
  and must not bear on the tailgate.

## What the checks found (first-pass estimates, status CONCEPT)
Safety rule used by Ford and camper makers: **camper center of gravity at or ahead of the rear axle**, and
loaded camper within the truck's camper cargo rating (door-jamb sticker).

| Truck | Fits physically | Loaded CG vs rear axle | Loaded camper (~1,800 lb) vs rating | Verdict |
|---|---|---|---|---|
| 2011 F-350, 8 ft, tailgate closed | yes | **7.9 in ahead** | 1,438-3,002 lb by engine | CONDITIONAL (check sticker) |
| 2011 F-350, 6.75 ft, tailgate down | yes, 15.7 in overhang | **8.3 in behind** | 1,650-2,905 lb | **FAIL** |
| F-150 6.5 ft | width yes; body clashes with 21.4 in rails | 4.6 in ahead | 1,300-2,440 lb | CONDITIONAL (most trucks over payload) |
| F-150 5.5 ft | as above | 7.2 in behind | 1,300-2,440 lb | **FAIL** |
| Tacoma 6 ft / 5 ft (2016-23) | **no**: tub base 49.4 in vs 41.5 in between wells | — | 1,050-1,445 lb | **FAIL** |

Why the short F-350 fails: Ford's 2011 crew-cab wheelbases (156.2 / 172.4 in) differ by exactly the bed
difference (16.2 in), so the extra 8 ft bed length is all *ahead of* the axle. On the 6.75 ft box the axle is
only ~35 in behind the bed front wall, and a 97 in camper's CG lands ~8 in behind it.

## Consequences
- The request "fit all three truck types with one camper" cannot be met safely. Tacoma fails on geometry and
  payload; half-tons fail or are marginal on payload; the 6.75 ft F-350 fails on CG.
- **Options for the owner** (not decided here):
  - **A. One camper, 8 ft F-350 only** (current design). Simplest; best CG.
  - **B. One camper for both F-350 boxes:** shorten to roughly 80-84 in so the CG stays ahead of the axle on
    the 6.75 ft box; the 8 ft box then has unused length. Needs re-running the fit study.
  - **C. A family from the same parametric system:** MINUTEMAN-97 (F-350 8 ft), a shorter F-350/half-ton
    version, and a separate narrow, light Tacoma version (tub base <= 40 in, dry weight well under ~700 lb,
    likely a pop-up). Same config architecture, different `dimensions.json` envelopes.
- Weight rises to 985-1,231 lb dry (excl. jacks), above the 850-950 lb target even at the low end. Cost rises to
  $4,402-8,735 (excl. jacks and tooling).

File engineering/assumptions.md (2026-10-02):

# Engineering assumptions

> **CAD appearance is not engineering validation.** A shape that looks right in a render has not been
> shown to carry load, stay watertight, or survive road vibration. Nothing in v0.1 has been calculated,
> tested, or reviewed.

Every important structural assumption carries exactly one status:
`CONCEPT` · `CALCULATED` · `MANUFACTURER VERIFIED` · `PHYSICALLY TESTED` · `PROFESSIONALLY REVIEWED` ·
`NEEDS REVIEW`. Truck-dependent values use `VERIFY ON TRUCK`.

Rules (enforced by `scripts_code/validate_model.py`):
- Never promote a status without the evidence. `CALCULATED` requires a file in
  `engineering/calculations/` cited in the Reference column.
- `MANUFACTURER VERIFIED` requires a datasheet in `reference/` cited in the Reference column.

| ID | Assumption | Status | Safety-critical | Reference |
|---|---|---|---|---|
| A-001 | Aluminum is welded GMAW with spool gun, 100% argon, ER5356. Self-shielded flux-core aluminum does not exist. | CONCEPT | yes | decisions/0001-welding-process.md |
| A-002 | Welded 6061-T6 loses ~40% of yield strength in the HAZ (~40 ksi to mid-20s ksi). All welded joints sized on HAZ-reduced allowables. | CONCEPT | yes | ADR 0001; cite Aluminum Design Manual to upgrade to MANUFACTURER VERIFIED |
| A-003 | Owner-welded members have min wall 0.125 in; 0.083 in wall is bolted/bonded only. | CONCEPT | yes | ADR 0001; validate_model.py |
| A-004 | Skin is 5052-H32 bonded with structural adhesive plus selective rivets and acts as a shear diaphragm. Never continuously welded. | CONCEPT | yes | Adhesive datasheet and joint tests required (v0.2) |
| A-005 | Jacks and tie-downs terminate in primary structural members, never in skin, trim, thin sheet, or a single T-nut. | CONCEPT | yes | Hard rule; v0.2 jack/tie-down design |
| A-006 | Tailgate is not a structural support. | CONCEPT | yes | Hard rule |
| A-007 | Camper CG must fall at or forward of the rear axle centerline. Area-centroid estimate, loaded: 7.9 in ahead on the 8 ft F-350; 8.3 in **behind** on the 6.75 ft F-350. | NEEDS REVIEW | yes | scripts_code/estimates.py; truck_data/fit_study.md; axle position is VERIFY ON TRUCK |
| A-008 | Truck payload capacity and rear axle / tire ratings accommodate shell + payload + occupants' gear. | NEEDS REVIEW | yes | Door-jamb payload sticker; weigh truck at a CAT scale |
| A-009 | Shell dry weight 985-1,231 lb excluding jacks (area-based coefficients, 97 in camper). Jacks add 100-140 lb. | CONCEPT | yes | bom/weight_report.md |
| A-010 | Nose (cab-over) is storage/desk volume only and is not engineered to carry two sleeping adults. | CONCEPT | yes | ADR 0002; v0.1 scope |
| A-011 | Nose cantilever (24 in over cab) carries its own weight plus a storage allowance (value TBD in v0.2). | NEEDS REVIEW | yes | v0.2 calculation |
| A-012 | Every aluminum-to-dissimilar-metal interface (stainless fasteners, steel jacks, truck tie-downs) is galvanically isolated (nylon washers, Tef-Gel/Duralac, isolation tape). | CONCEPT | yes | cad/config/hardware.scad notes |
| A-013 | Every exterior joint gets a waterproofing detail; no exposed screw penetrations as primary roof attachment. | CONCEPT | no | Hard rule; drawings E01-E02 in v0.3 |
| A-014 | Owner accessory T-slot rails bolt into frame members, are not primary structure, and carry owner accessories only. Slip/rotation capacity to be tested. | CONCEPT | yes | Test plan: T-slot joint slip and rotation |
| A-015 | 6061-T6 density 0.0975 lb/in3; 5052-H32 0.0968 lb/in3; XPS ~2 pcf. | CONCEPT | no | Standard handbook values; cite datasheet |
| A-016 | 1010-class T-slot extrusion weighs 0.5097 lb/ft. | CONCEPT | no | 80/20 catalog value; add datasheet to reference/ |
| A-017 | Roof crown 0.75 in transverse provides positive drainage at expected parking slopes. | CONCEPT | no | Water test (v0.4) |
| A-018 | Lower tub at 59.5 in width passes the 2011 Super Duty tailgate opening (~61 in) with 0.75 in per side. | VERIFY ON TRUCK | yes | truck_data/measurement_templates/f350_measurement_sheet.md |
| A-019 | Nose underside 4 in above highest cab-roof point (incl. clearance lamps) is enough for cab/bed relative motion. | VERIFY ON TRUCK | yes | Measurement sheet M4; check under articulation |
| A-020 | Power zone reservation: battery or solar generator, 150 lb, 24 x 20 in footprint, forward of rear axle. | CONCEPT | yes | ADR 0003 |
| A-021 | Roof rack + panels: 120 lb distributed over six bosses, each landing on a roof crossmember. | CONCEPT | yes | ADR 0003 |
| A-023 | 2011 F-350 rear axle is ~35.0 in (6.75 ft box) / ~51.2 in (8 ft box) aft of the bed front wall, derived from Ford wheelbases and a quoted cab-to-axle figure. | VERIFY ON TRUCK | yes | truck_data/README.md |
| A-024 | Loaded camper (~1,800 lb: dry + jacks + reservations + 300 lb gear) is within the 2011 F-350 camper cargo rating only for some engine/option combinations (1,438-3,002 lb). | NEEDS REVIEW | yes | Ford 2011 RV & Trailer Towing Guide; door-jamb sticker |
| A-025 | Half-ton and Tacoma fit values (bed floor height, cab height, axle position, tailgate opening) are estimates; fit verdicts for those trucks are indicative only. | CONCEPT | yes | truck_data/README.md |
| A-022 | Road vibration and fatigue at bonded and welded joints are acceptable over the service life. | NEEDS REVIEW | yes | v0.2+ fatigue review; professional review before v1.0 |

## Safety-critical list (from PROJECT_HANDOFF.md §8)

Floor structure, jack mounts, jack stability, tie-downs, nose cantilever, major joints, fastener shear and
tension, T-slot slip, bracket rotation, skin shear transfer, adhesive compatibility, fatigue, road
vibration, truck clearance, center of gravity, payload, rear axle loading, tire loading.
None of these has been addressed beyond the assumptions above. v0.2 starts this work.

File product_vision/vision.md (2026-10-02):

# Vision

> A rugged aluminum truck-camper shell that provides the protected space and attachment infrastructure
> while allowing the owner to decide what the camper eventually becomes.

MINUTEMAN is not an RV. It is a **durable, weatherproof, lightweight, configurable aluminum platform**
for a Ford F-350. It must be useful the day it is finished, with nothing installed inside, as a dry,
lockable, insulated room a 6'7" person can stand up in.

The interior is deliberately left open. Instead of cabinetry, the shell provides strategically placed
T-slot rails, a reinforced floor zone, a wire chase, and roof-rack hard points. The owner can then
evolve the camper over years instead of making every decision on day one.

Commercial empty shells cost $17,000-21,000 (`competitors/modular_shells.md`). MINUTEMAN's material
estimate is $4,400-8,700 plus the owner's labor, built with tools a determined novice can learn.

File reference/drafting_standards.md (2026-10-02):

# Drafting standards used for the MINUTEMAN drawing set

The drawings follow the **ASME Y14** family as far as a generated PDF practically can. Implementation:
`scripts_code/drawlib.py`.

| Standard | Covers | How the drawings apply it |
|---|---|---|
| ASME Y14.1 | Sheet sizes and format | ANSI C (22 x 17 in) landscape; zoned border (columns 1-8, rows A-D); title block with project, title, size, drawing number (MM-A0n), revision, scale, date, sheet n of 5, drawn/checked, status; tolerance block; third-angle projection symbol |
| ASME Y14.35 | Revisions | Revision block top-right: REV / DESCRIPTION / DATE / APPROVED. Rev A = v0.1 release, Rev B = 97 in length + this format |
| ASME Y14.2 | Line conventions and lettering | Thick visible lines; thin dashed hidden lines (rails behind walls, door beyond a section); long-short center lines (centerline, rear-axle CL); **phantom lines for the truck** (adjacent / reference part); thin dimension and extension lines; upper-case Gothic (Helvetica) lettering |
| ASME Y14.3 | Orthographic and section views | Third-angle views (plan above elevation); cutting-plane lines with view arrows and letters (B-B, C-C on A01; D-D, E-E on A03; A-A on A04); detail view (DETAIL B) with its own scale |
| ASME Y14.5 | Dimensioning | Unidirectional text (reads from the bottom of the sheet); decimal inch with no leading zero (.5); reference dimensions in parentheses; **flag notes** (numbered triangles): flag 1 = VERIFY ON TRUCK, flag 2 = estimate; general tolerance block; "interpret per ASME Y14.5-2018" |

Style borrowed from builder layout sheets (the owner's van reference image): chained interior height
dimensions (floor → rail → rail → rail → ceiling), overall-length chains above the view, and labeled leaders
to the periphery naming each feature (rails, window, power zone, wire chase, nose storage, 6'7" figure).

Deliberate deviations: GD&T feature control frames are not used (an envelope has no fabricated features
yet). Tolerances are envelope-level until v0.3 part drawings exist.

Sources (accessed 2026-10-01): Wikipedia "ASME Y14.5"; GrabCAD tutorial "Overview of ASME Y14 series drawing
standards"; ANSI blog "What are the ASME Y14.5 and ASME Y14.100 standards".

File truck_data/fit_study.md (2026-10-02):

<!-- GENERATED by scripts_code/generate_fit_study.py from cad/config/dimensions.json - DO NOT HAND-EDIT -->
# Multi-truck fit study

One camper, sized to the design truck **F350_LONG**, checked against each truck. The camper does not change shape per truck. **Status: CONCEPT.** Truck values other than the 2011 F-350 are published bed dimensions plus estimates (see `truck_data/README.md`); weights and CG are first-pass estimates.

Loaded camper = dry estimate (mean) + jacks + power-zone and roof-rack reservations + 300 lb owner gear. CG is computed from envelope face centroids (`scripts_code/estimates.py`), not the floor midpoint.

## Summary

| Truck | Tailgate | Verdict | Loaded CG vs axle | Loaded camper | Camper cargo rating |
|---|---|---|---|---|---|
| 2011 F-350 crew cab 4x4 SRW, 8 ft box (DESIGN TRUCK) | CLOSED | **CONDITIONAL** | +7.9 in | 1798 lb | 1438-3002 lb |
| 2011 F-350 crew cab 4x4 SRW, 6.75 ft box | DOWN | **FAIL** | -8.3 in | 1798 lb | 1650-2905 lb |
| Ford F-150 (2021+) SuperCrew, 6.5 ft box (half-ton representative) | DOWN | **CONDITIONAL** | +4.6 in | 1798 lb | 1300-2440 lb |
| Ford F-150 (2021+) SuperCrew, 5.5 ft box (half-ton representative) | DOWN | **FAIL** | -7.2 in | 1798 lb | 1300-2440 lb |
| Toyota Tacoma (2016-2023) Double Cab, 6 ft box | DOWN | **FAIL** | +2.9 in | 1798 lb | 1050-1445 lb |
| Toyota Tacoma (2016-2023) Double Cab, 5 ft box | DOWN | **FAIL** | -10.3 in | 1798 lb | 1050-1445 lb |

## Criteria by truck

| Criterion | F350_LONG | F350_SHORT | F150_65 | F150_55 | TACOMA_6 | TACOMA_5 |
|---|---|---|---|---|---|---|
| Tub base between wheel wells | PASS<br>0.75 in/side | PASS<br>0.75 in/side | PASS<br>0.60 in/side | PASS<br>0.60 in/side | FAIL<br>-3.95 in/side | FAIL<br>-3.95 in/side |
| Tub step above wheel wells | PASS<br>1.00 in | PASS<br>1.00 in | PASS<br>1.00 in | PASS<br>1.00 in | PASS<br>1.00 in | PASS<br>1.00 in |
| Tub through tailgate opening | PASS<br>0.75 in/side | PASS<br>0.75 in/side | CHECK<br>0.25 in/side | CHECK<br>0.25 in/side | FAIL<br>-3.25 in/side | FAIL<br>-3.25 in/side |
| Tub between bed sides | PASS<br>3.25 in/side | PASS<br>3.25 in/side | PASS<br>2.85 in/side | PASS<br>2.85 in/side | FAIL<br>-1.40 in/side | FAIL<br>-1.40 in/side |
| Body underside over bed rails | PASS<br>1.00 in | PASS<br>1.00 in | CHECK<br>-0.40 in | CHECK<br>-0.40 in | PASS<br>1.90 in | PASS<br>1.90 in |
| Nose over cab roof | PASS<br>4.00 in | PASS<br>4.00 in | PASS<br>3.50 in | PASS<br>3.50 in | PASS<br>8.00 in | PASS<br>8.00 in |
| Rear overhang past bed end | PASS<br>-0.5 in | CHECK<br>15.7 in | CHECK<br>18.6 in | CHECK<br>30.4 in | CHECK<br>23.8 in | CHECK<br>37.0 in |
| Loaded CG vs rear axle | PASS<br>+7.9 in (+ = ahead) | FAIL<br>-8.3 in (+ = ahead) | PASS<br>+4.6 in (+ = ahead) | FAIL<br>-7.2 in (+ = ahead) | PASS<br>+2.9 in (+ = ahead) | FAIL<br>-10.3 in (+ = ahead) |
| Loaded camper vs camper cargo rating | CHECK<br>1798 lb vs 1438-3002 lb | CHECK<br>1798 lb vs 1650-2905 lb | CHECK<br>1798 lb vs 1300-2440 lb | CHECK<br>1798 lb vs 1300-2440 lb | FAIL<br>1798 lb vs 1050-1445 lb | FAIL<br>1798 lb vs 1050-1445 lb |

## Rules applied

- Camper CG must be **at or ahead of the rear axle** (Ford: CG data on the truck's Consumer Information Sheet; Northern Lite: camper CG must be forward of the bulkhead-to-axle distance). PASS needs >= 2 in margin.
- Loaded camper must not exceed the truck's camper cargo rating. A range means it depends on engine/options: read the door-jamb sticker.
- The tailgate is never structural (hard rule). Overhang means the camper floor cantilevers past the bed end; the tailgate is lowered or removed and must not carry load.
- Lateral clearance >= 0.5 in per side; nose >= 3 in over the cab roof.

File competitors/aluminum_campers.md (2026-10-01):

# Aluminum-framed campers

## Four Wheel Camper (FWC) Hawk: pop-up, welded aluminum frame
| | |
|---|---|
| Construction | Welded aluminum frame, one-piece aluminum roof, aluminum siding, soft-wall pop-up |
| Dry weight | ~1,100-1,200 lb depending on options (base model ~1,200 lb) |
| Price | Hawk Base slide-in from $19,995; full camper from $29,495; flatbed model from $41,995 |

Sources (accessed 2026-10-01):
- FWC Hawk base model: https://fourwheelcampers.com/model/hawk-model-pop-up-truck-camper-leader-full-size-trucks/hawk-base-model/
- FWC Hawk model page: https://fourwheelcampers.com/model/hawk-model-pop-up-truck-camper-leader-full-size-trucks/
- Truck Camper Adventure, owner review: https://www.truckcamperadventure.com/inside-the-four-wheel-camper-hawk-an-owners-honest-review/

**Lesson:** FWC proves a **welded aluminum frame** survives decades of off-road use. They weld the frame
in a factory with trained welders, though; MINUTEMAN limits owner welding to small nodes (ADR 0001).
The "base model" (shell with minimal interior) is FWC's equivalent of our shell-first concept.

## Alaskan Camper: hard-side, hydraulic telescoping
| | |
|---|---|
| Construction | Hard-sided walls that telescope hydraulically; lowers for travel, raises for standing room |
| 8 ft cabover | Dry weight 1,390-1,985 lb; MSRP $37,190-42,090 (buyer's guide range) |

Sources (accessed 2026-10-01):
- Truck Camper Magazine, Alaskan hard-side buyer's guide: https://www.truckcampermagazine.com/buyers-guide/alaskan-hard-side-buyers-guide/
- The Autopian, hydraulic telescoping overview: https://www.theautopian.com/this-truck-camper-is-both-a-pop-up-and-hard-sided-thanks-to-hydraulic-telescoping-tech

**Lesson:** Alaskan is the existence proof for the owner's "high-low" idea: hard sides with a low travel
height. It is also a reminder that the mechanism adds weight and cost. That is why high-low is a separate
future model (`camper_versions/future_concepts/high_low.md`) and does not shape v0.1.

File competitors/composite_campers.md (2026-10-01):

# Composite campers

## Total Composites: FRP sandwich shells and kits
| | Lynx 7' | Lynx 5' |
|---|---|---|
| Construction | Fiberglass-reinforced plastic skins, polyurethane foam core, up to R-16 | same |
| Dry weight | 606 lb | 540 lb |
| Price (empty shell) | $17,959 (2024) | $17,200 |
Models: Lynx, Wolf, Bobcat, Wolverine. European kits from EUR 11,970.

Source (accessed 2026-10-01): Truck Camper Magazine, Total Composites buyer's guide:
https://www.truckcampermagazine.com/buyers-guide/hard-side/total-composites-buyers-guide/

**Lesson:** A bonded sandwich panel shell is **much lighter** than a framed aluminum shell for the same
envelope. It is the main structural alternative to MINUTEMAN's approach. Its drawbacks for a DIY builder
are panel-joint engineering, repairability, and the attachment hard points that composites need. The
empty shell sells for $17-18k, which frames what "shell only" is worth commercially.

## Scout Campers: composite panels plus aluminum exoskeleton
| | Yoho | Olympic |
|---|---|---|
| Construction | Zero-wood composite panels, aluminum exoskeleton | same |
| Dry weight | 913 lb base ("lightest hard-walled pickup camper" claim) | 1,165 lb |
| Price | $19,240 base | $19,980 |

Sources (accessed 2026-10-01):
- Truck Camper Magazine, Scout buyer's guide: https://www.truckcampermagazine.com/buyers-guide/hard-side/scout-camper-buyers-guide/
- New Atlas, Scout Yoho: https://newatlas.com/outdoors/scout-yoho-lightest-pickup-camper/
- Motor1, Yoho: https://www.motor1.com/news/429791/yoho-camper-shell-scout-campers/

**Lesson:** Scout's modular, removable-equipment interior (a portable power station, an indoor/outdoor
stove) matches MINUTEMAN's "leave the interior open" philosophy and validates a reinforced floor zone
for a portable power station (ADR 0003).

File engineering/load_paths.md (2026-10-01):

# Load paths (concept, v0.1)

Status: **CONCEPT.** These are the intended paths the v0.2 frame must realize. Nothing is sized yet.

| Load case | Path | Safety-critical |
|---|---|---|
| Dead + payload, on truck | Floor sandwich -> floor longitudinals (FLR-L/R) -> bed floor (bearing), restrained by tie-downs | yes |
| Dead + payload, on jacks | Floor/wall -> corner nodes (welded, HAZ-sized) -> JACK-LF/RF/LR/RR brackets -> jacks -> ground | yes |
| Tie-down (braking, cornering, bumps) | Camper mass -> tie-down nodes (TIE-*) in primary frame -> turnbuckles -> truck frame-mounted anchors. **Never** bed rails, tailgate, or skin | yes |
| Nose cantilever | Nose floor + walls -> front wall frame -> floor/side walls; does not bear on the cab | yes |
| Racking (lateral, torsional twist off-road) | Wall frames + **bonded skin acting as shear diaphragm** -> floor | yes |
| Roof rack + panels | Rack -> RACK-ROOF bosses -> roof crossmembers -> wall verticals. Never bare skin | yes |
| Power zone | Equipment -> T-slot tie-downs in reinforced floor zone -> floor crossmembers | yes |
| Owner accessories | Accessory -> UTIL T-slot rail -> bolts into wall verticals (not skin) | moderate |
| Wind / aero | Skin -> frame; raked nose reduces frontal pressure | no |

## Open
Each row becomes a calculation file in `engineering/calculations/` in v0.2 before any status upgrade.

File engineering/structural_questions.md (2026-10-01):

# Structural questions (open, for v0.2)

1. **Floor:** sandwich (aluminum skins + foam core) or tube grid + plywood/composite deck? Which carries
   jack loads to the corners with the fewest welds?
2. **Corner and jack nodes:** weld size and HAZ-reduced capacity at 0.125-0.250 in wall; can a local shop
   weld these if the owner's practice coupons fail?
3. **Jack type and mounting:** bolt-on corner brackets vs. integrated jack boxes; swing-out clearance on an
   80 in body over a ~80 in truck.
4. **Tie-down system:** frame-mounted (e.g., Torklift / Happijac-style) anchors require camper tie-down
   points at specific heights and positions. Measure the truck first.
5. **Adhesive:** polyurethane (Sikaflex 252) vs. structural methacrylate vs. VHB. Choose by coupon tests
   (lap shear, peel, thermal cycling, -20 F to 160 F) plus 5052/6061 surface prep.
6. **Skin shear transfer:** bond width and rivet pitch for the racking diaphragm.
7. **Nose cantilever:** 24 in over the cab with a storage allowance; deflection limit under road input.
8. **T-slot rails:** slip and rotation capacity of drop-in T-nuts under vibration; rail-to-frame bolt pattern.
9. **CG and axle load:** where is the CG with a 150 lb power zone and 120 lb roof load? Is the rear GAWR
   respected? (Needs the payload sticker from the measurement sheet.)
10. **Fatigue:** welded nodes under road vibration; is a professional review needed before v1.0? (Assume yes.)
11. **Thermal bridging:** the frame is a continuous aluminum path through the insulation. Thermal break strategy?
12. **Galvanic isolation:** stainless fasteners, steel jacks and turnbuckles against aluminum.

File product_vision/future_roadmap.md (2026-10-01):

# Future roadmap

| Version | Content | Gate |
|---|---|---|
| **v0.1** | Envelope, config architecture, truck fit, drawings A01-A03, measurement sheet | Owner approval (now) |
| v0.2 | Structural frame candidate: floor, walls, roof, nose, jack + tie-down structures; first calcs | Owner approval + truck measured |
| v0.3 | Complete shell CAD: skin panelization, door/window framing, waterproofing details, full drawing set, cut lists, manual | Owner approval |
| v0.4 | Prototype/fabrication candidate: test results folded in (joints, adhesive, water) | Test plan passed |
| v0.5 | Changes discovered during physical construction | As-built |
| v1.0 | Completed and validated first physical shell | Water test, load checks, scale weight |

## Separate future products
- **High-low (telescoping) variant:** `camper_versions/future_concepts/high_low.md`.
- **Larger cab-over** (sleeping-rated nose): a separate structural revision.
- Generic short/long-bed fitments for other trucks: the config architecture already supports variants.

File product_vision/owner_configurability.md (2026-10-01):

# Owner configurability

What the owner can change without re-engineering the shell, and what needs care.

## Free to change (accessory level)
- Anything bolted to UTIL T-slot rails within the rail's rated load. **Rating TBD:** T-slot slip and
  rotation tests are in the v0.2 test plan, so do not hang heavy loads until then.
- Equipment strapped into the power zone, up to the 150 lb reservation.
- Roof rack and panels on the six bosses, up to the 120 lb reservation.

## Change in `dimensions.json` and regenerate (design level)
- Rail counts and heights, door offset, window sizes/positions, nose window on/off, nose projection,
  interior height (see the sensitivity line in `bom/weight_report.md`).

## Do not change without engineering review
- Anything touching jack structures, tie-down nodes, the floor structure, or the nose cantilever.
- Cutting new openings in skin panels (the skin is a structural shear diaphragm).
- Converting the nose into a sleeping platform (it is not engineered for that, A-010).

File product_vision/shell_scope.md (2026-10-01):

# Shell scope

## In scope
Structural floor, aluminum frame, bonded aluminum skin, insulated walls and roof, interior protective
panel, one rear entry door, limited windows, four camper-jack attachment structures, truck tie-down
structures, interior T-slot utility rails, and *structural provisions* for a roof rack and a
battery/generator bay (ADR 0003).

## Explicitly out of scope
Shower, toilet, permanent bed, kitchen, sink, plumbing, water tanks, propane, refrigerator, permanent
cabinetry, electrical system, wiring, charge controllers, batteries, solar panels, HVAC, entertainment,
luxury finishes, and any assumption about interior layout.

## The boundary
The shell provides **places and paths**, not systems:

| Owner might add | Shell provides |
|---|---|
| Solar panels | Roof-rack bosses on crossmembers (RACK-ROOF-01..06) |
| Battery / power station | Reinforced 24 x 20 in floor zone with tie-downs, 150 lb reservation |
| Wiring | Reserved wire chase, front-left corner, floor to roof |
| Bed, shelves, desk, cabinets | T-slot rails UTIL-L/R/F; nose volume for storage/desk |

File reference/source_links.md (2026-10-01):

# Source links

External sources cited anywhere in the repo. Accessed 2026-10-01 unless noted. Competitor-specific links
are listed in `competitors/*.md`.

| Topic | Link | Used in |
|---|---|---|
| Kimbo buyer's guide | https://www.truckcampermagazine.com/buyers-guide/hard-side/kimbo-buyers-guide/ | competitors/kimbo.md |
| Four Wheel Camper Hawk | https://fourwheelcampers.com/model/hawk-model-pop-up-truck-camper-leader-full-size-trucks/hawk-base-model/ | competitors/aluminum_campers.md |
| Alaskan hard-side buyer's guide | https://www.truckcampermagazine.com/buyers-guide/alaskan-hard-side-buyers-guide/ | competitors/aluminum_campers.md |
| Total Composites buyer's guide | https://www.truckcampermagazine.com/buyers-guide/hard-side/total-composites-buyers-guide/ | competitors/composite_campers.md |
| Scout Yoho | https://newatlas.com/outdoors/scout-yoho-lightest-pickup-camper/ | competitors/composite_campers.md |
| DIY camper construction threads | https://forum.expeditionportal.com/goto/post?id=1230175 | competitors/diy_builds.md |

## Needed (not yet collected)
- Aluminum Design Manual: welded 6061 HAZ allowables (upgrades A-002)
- 80/20 1010 profile datasheet (upgrades A-016)
- Structural adhesive technical datasheets (A-004)
- Ford Super Duty body builder's guide: bed and cab dimensions (could replace several VERIFY ON TRUCK seeds)

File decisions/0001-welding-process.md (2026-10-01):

# ADR 0001 — Aluminum welding: GMAW spool gun, novice-driven design rules

**Status:** Accepted (v0.1) · **Source:** PROJECT_HANDOFF.md §2.1

## Context
The original spec asked for "self-shielded flux-core MIG" on aluminum. There is no self-shielded
flux-cored aluminum wire on the market. Aluminum needs inert-gas shielding, and flux-cored processes
rely on slag chemistry that does nothing against aluminum's tenacious oxide layer. The owner's clarified
requirement was "whatever I need for strong, cheap, beginner-friendly aluminum welding."

## Decision
- **Process:** GMAW (MIG) with a **spool gun**, 100% argon at 25–35 CFH.
- **Machine class:** 200–230 A (e.g. Hobart Handler 210MVP + SpoolRunner 100, Eastwood MIG 180,
  Primeweld MIG 230). One-time tooling budget $800–1,400, tracked in `time_cost/tooling_costs.csv`,
  never in shell material cost.
- **Wire:** ER5356, 0.035". Push angle, fast travel, no preheat below 1/4" thickness.
- **Architecture is HYBRID:** weld only small safety-critical nodes (jack boxes, tie-down nodes, floor
  corner nodes) that a local shop could also weld. Bolt, rivet, and bond everything else.
  `FRAME_SYSTEM` stays switchable between `HYBRID`, `BOLTED_TUBE`, and `TSLOT`.

## Consequences (must propagate into CAD and engineering)
1. **Owner-welded members: minimum wall 0.125".** A novice will burn through the original spec's
   1×1×0.083" tube. 0.083" wall is restricted to bolted/bonded secondary framing.
   Enforced by `scripts_code/validate_model.py` (any part with `join = "WELDED"` and wall < 0.125 fails).
2. **Heat-affected-zone strength loss.** Welded 6061-T6 loses roughly 40% of its yield strength in the
   HAZ (≈40 ksi down to the mid-20s ksi, effectively annealed). Every welded joint is sized on
   HAZ-reduced allowables. Recorded as assumption A-002 in `engineering/assumptions.md`, status
   `CONCEPT` until a datasheet / Aluminum Design Manual reference is cited.
3. Aluminum skin is never welded to the frame (thin sheet distortion and burn-through); it is bonded.

## Do not revert
Do not reintroduce flux-core, and do not specify 0.083" wall for any welded joint.

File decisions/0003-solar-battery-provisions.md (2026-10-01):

# ADR 0003 — Solar and battery: structural provisions only

**Status:** Accepted (v0.1) · **Source:** PROJECT_HANDOFF.md §2.3

## Context
The owner wants a roof rack for solar panels and an internal battery or solar generator. The spec
forbids designing electrical systems.

## Decision
Design **only the structure**:
- **Roof-rack mounting bosses** that land on roof crossmembers, never on bare skin. v0.1 shows six boss
  placeholders (`RACK-ROOF-01..06`). In v0.2 each one must sit on a roof crossmember.
- **Wire chase:** a reserved vertical path through the wall/roof cavity (front-left corner in v0.1),
  kept as reserved geometry with no wiring.
- **Reinforced floor zone:** a floor area with T-slot tie-down capability for a battery or solar
  generator, sized by mass and footprint only. Placed forward of the rear axle to help the center of
  gravity.

No panels, wiring, controllers, loads, or capacity math. The reserved masses are payload assumptions in
`engineering/assumptions.md` (A-020, A-021).

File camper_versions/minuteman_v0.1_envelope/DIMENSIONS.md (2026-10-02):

<!-- GENERATED by scripts_code/generate_dimension_docs.py from cad/config/dimensions.json - DO NOT HAND-EDIT -->
# MINUTEMAN v0.1 envelope - dimensions

Every major design dimension, each tagged exactly one of:

- **FIXED**: owner requirement or hard constraint; change only by decision record.
- **PARAMETRIC**: free design variable; change in `dimensions.json` and regenerate.
- **PRELIMINARY**: engineering placeholder; expected to change in v0.2/v0.3.
- **VERIFY ON TRUCK**: depends on the physical truck; confirm with the measurement sheet.

Units: inches. Origin: bed-floor top, truck centerline, inner face of bed front wall; +X forward, +Y left (driver), +Z up.

## Headline

| | Value | Tag |
|---|---|---|
| Interior clear standing height | 80.00 (6'-8") | FIXED |
| Overall length (rear face to nose tip) | 121.00 (10'-1") | PARAMETRIC |
| Body width | 80.00 (6'-8") | PARAMETRIC |
| Ground to roof eave / crown on 2011 F-350 4x4 | 126.00 (10'-6") / 126.75 (10'-6.75") | VERIFY ON TRUCK |
| Lower length (fills 8 ft bed, tailgate closed) | 97.00 (8'-1") | FIXED |
| Nose underside above cab roof | 4.00 (0'-4") | VERIFY ON TRUCK |

## Design parameters

### Envelope

| Parameter | Description | Value | Tag | Note |
|---|---|---|---|---|
| `camper_lower_length` | Lower tub / main body length | 97 | FIXED | Owner requirement (ADR 0004): fills the 8 ft bed with the tailgate closed. 98.0 bed - 0.5 front gap - 0.5 tailgate clearance. |
| `camper_body_width` | Main body width (above bed rails) | 80 | PARAMETRIC | Legal width limit is 102 in; 80 matches cab width for low drag. |
| `camper_lower_tub_width` | Lower tub width (upper step, between rails) | 59.5 | VERIFY ON TRUCK | Must pass the 2011 F-350 tailgate opening (~61 in) with clearance; 63 in would not. |
| `interior_height` | Interior clear standing height | 80 | FIXED | Owner requirement: 6'7" (79 in) person standing. Parametric for sensitivity (ADR 0002). |
| `roof_crown` | Roof transverse drainage crown at centerline | 0.75 | PRELIMINARY | Positive drainage; no ponding. |
| `nose_projection` | Nose (cab-over) projection forward of front wall | 24 | PARAMETRIC | Storage/desk volume only. Not a sleeping platform for two adults. |

### Clearance

| Parameter | Description | Value | Tag | Note |
|---|---|---|---|---|
| `tub_side_clearance` | Tub-to-bed side clearance, each side | 0.75 | PRELIMINARY |  |
| `wheel_well_clearance` | Tub step clearance above wheel wells | 1 | PRELIMINARY |  |
| `body_rail_clearance` | Body underside above bed rail top | 1 | PRELIMINARY | Space for rail caps / rubber spacers. |
| `camper_front_gap` | Camper front wall to bed front wall gap | 0.5 | PRELIMINARY |  |
| `camper_to_cab_clearance` | Nose underside above cab roof | 4 | VERIFY ON TRUCK | Measure over clearance lights / antenna; allow for suspension and cab-bed relative motion. |
| `tailgate_clearance` | Camper rear face to closed tailgate (design truck) | 0.5 | PRELIMINARY |  |

### Construction

| Parameter | Description | Value | Tag | Note |
|---|---|---|---|---|
| `floor_sandwich` | Floor sandwich thickness | 3 | PRELIMINARY |  |
| `wall_thickness` | Wall thickness (skin + frame/insulation + interior panel) | 1.75 | PRELIMINARY |  |
| `roof_thickness` | Roof structure + skin thickness at eave | 3.5 | PRELIMINARY |  |
| `skin_thickness` | Exterior skin thickness (5052-H32) | 0.05 | PRELIMINARY | 0.040 on walls is a cost/weight lever (time_cost/cost_reduction_opportunities.md). |
| `insulation_thickness` | Wall/roof insulation thickness | 1.5 | PRELIMINARY |  |
| `nose_floor_thickness` | Nose floor (cab-over) thickness | 2.5 | PRELIMINARY |  |

### Styling

| Parameter | Description | Value | Tag | Note |
|---|---|---|---|---|
| `body_corner_radius` | Vertical corner radius (plan view) | 3 | PARAMETRIC |  |
| `roof_edge_radius` | Roof-to-wall edge radius | 2 | PARAMETRIC |  |
| `nose_top_setback` | Nose front rake: top setback from lower front edge | 10 | PARAMETRIC |  |

### Openings

| Parameter | Description | Value | Tag | Note |
|---|---|---|---|---|
| `door_width` | Rear door rough opening width | 26 | PRELIMINARY | Sized to a commercial cargo-trailer / RV door. Final value from the purchased door's datasheet. |
| `door_height` | Rear door rough opening height | 72 | PRELIMINARY |  |
| `door_sill_above_floor` | Door sill above interior floor | 1 | PRELIMINARY |  |
| `door_offset_y` | Door lateral offset from centerline (+left) | 0 | PARAMETRIC |  |
| `window_side_width` | Side window width | 24 | PRELIMINARY |  |
| `window_side_height` | Side window height | 15 | PRELIMINARY |  |
| `window_side_center_above_floor` | Side window center above interior floor | 50 | PARAMETRIC |  |
| `window_side_center_from_rear` | Side window center forward of camper rear face | 30 | PARAMETRIC |  |
| `window_nose_width` | Nose window width (optional) | 20 | PRELIMINARY |  |
| `window_nose_height` | Nose window height (optional) | 9 | PRELIMINARY |  |

### Utility rails

| Parameter | Description | Value | Tag | Note |
|---|---|---|---|---|
| `util_profile` | Owner accessory rail profile | TSLOT_1010 | PRELIMINARY |  |
| `utility_rail_left_count` | Left wall rail count | 3 | PARAMETRIC |  |
| `utility_rail_right_count` | Right wall rail count | 3 | PARAMETRIC |  |
| `utility_rail_front_count` | Front wall rail count | 1 | PARAMETRIC |  |
| `utility_rail_side_heights` | Side rail centerline heights above interior floor | 24, 44, 64 | PARAMETRIC |  |
| `utility_rail_front_height` | Front rail centerline height above interior floor | 36 | PARAMETRIC |  |
| `utility_rail_end_inset` | Rail end inset from interior corners | 2 | PARAMETRIC |  |

### Provisions

| Parameter | Description | Value | Tag | Note |
|---|---|---|---|---|
| `roof_rack_boss_from_rear` | Roof-rack boss stations forward of camper rear | 10, 44, 78 | PRELIMINARY | v0.2: each station must coincide with a roof crossmember (ADR 0003). |
| `roof_rack_boss_edge_inset` | Roof-rack boss inset from body side | 6 | PRELIMINARY |  |
| `roof_rack_boss_diameter` | Roof-rack boss diameter | 2 | PRELIMINARY |  |
| `roof_rack_boss_height` | Roof-rack boss height above skin | 0.75 | PRELIMINARY |  |
| `power_zone_length` | Reinforced floor zone length (battery / generator) | 24 | PRELIMINARY |  |
| `power_zone_width` | Reinforced floor zone width | 20 | PRELIMINARY |  |
| `power_zone_from_front` | Reinforced floor zone set back from front interior wall | 2 | PRELIMINARY | Forward placement keeps mass ahead of the rear axle. |
| `wire_chase_size` | Wire chase square size (front-left corner, floor to roof) | 3 | PRELIMINARY |  |

### Reference

| Parameter | Description | Value | Tag | Note |
|---|---|---|---|---|
| `human_height` | Human reference figure height (6'7") | 79 | FIXED |  |

### Payload

| Parameter | Description | Value | Tag | Note |
|---|---|---|---|---|
| `owner_gear_allowance_lb` | Owner gear allowance for payload / CG checks (lb) | 300 | PRELIMINARY | Water, food, tools, bedding. Placed at floor center for CG. Not part of dry weight. |

## Derived dimensions (computed in `scripts_code/common.py`)

| Name | Description | 8 ft bed (design) | 6.75 ft bed | Tag |
|---|---|---|---|---|
| `tub_base_width` | Lower tub base width (between wheel wells) | 49.4 | 49.4 | VERIFY ON TRUCK |
| `tub_step_z` | Lower tub step height above bed floor (clears wheel wells) | 11.5 | 11.5 | VERIFY ON TRUCK |
| `camper_lower_tub_height` | Lower tub height / body underside above bed floor | 21 | 21 | VERIFY ON TRUCK |
| `camper_front_x` | Camper front face X | -0.5 | -0.5 | PRELIMINARY |
| `camper_rear_x` | Camper rear face X | -97.5 | -97.5 | PRELIMINARY |
| `interior_floor_z` | Interior floor above bed floor | 3 | 3 | PRELIMINARY |
| `ceiling_z` | Ceiling above bed floor | 83 | 83 | PRELIMINARY |
| `roof_eave_z` | Roof eave above bed floor | 86.5 | 86.5 | PRELIMINARY |
| `roof_crown_z` | Roof crown (highest point) above bed floor | 87.25 | 87.25 | PRELIMINARY |
| `nose_bottom_z` | Nose underside above bed floor | 45.5 | 45.5 | VERIFY ON TRUCK |
| `nose_floor_z` | Nose interior floor above bed floor | 48 | 48 | VERIFY ON TRUCK |
| `nose_interior_height` | Nose interior clear height | 35 | 35 | VERIFY ON TRUCK |
| `nose_front_x` | Nose lower front edge X | 23.5 | 23.5 | PARAMETRIC |
| `overall_length` | Overall camper length (rear face to nose tip) | 121 | 121 | PARAMETRIC |
| `overall_height` | Overall camper height (tub bottom to crown) | 87.25 | 87.25 | PRELIMINARY |
| `body_interior_width` | Main body interior width | 76.5 | 76.5 | PRELIMINARY |
| `tub_interior_base_width` | Interior floor width (tub base) | 45.9 | 45.9 | VERIFY ON TRUCK |
| `interior_length` | Main body interior length (excl. nose) | 93.5 | 93.5 | PRELIMINARY |
| `door_bottom_z` | Door sill above bed floor | 4 | 4 | PRELIMINARY |
| `door_top_z` | Door head above bed floor | 76 | 76 | PRELIMINARY |
| `window_side_center_z` | Side window center above bed floor | 53 | 53 | PARAMETRIC |
| `headroom_6ft7` | Headroom over a 6'7" person | 1 | 1 | FIXED |
| `ground_to_eave` | Ground to roof eave on truck | 126 | 126 | VERIFY ON TRUCK |
| `ground_to_crown` | Ground to roof crown on truck (travel height, excl. rack) | 126.75 | 126.75 | VERIFY ON TRUCK |
| `cab_back_x` | Cab back face X | 5.5 | 5.5 | VERIFY ON TRUCK |
| `nose_over_cab` | Nose overlap forward of cab back | 18 | 18 | VERIFY ON TRUCK |
| `tailgate_x` | Bed end (closed tailgate inner face) X | -98 | -81.8 | VERIFY ON TRUCK |
| `rear_overhang` | Camper rear face past bed end (+ = overhangs, - = bed left over) | -0.5 | 15.7 | VERIFY ON TRUCK |
| `rear_axle_x` | Rear axle X | -51.2 | -35 | VERIFY ON TRUCK |
| `floor_mid_ahead_of_axle` | Camper floor midpoint ahead of rear axle | 2.2 | -14 | VERIFY ON TRUCK |
| `cab_clearance` | Nose underside above this truck's cab roof | 4 | 4 | VERIFY ON TRUCK |
| `rail_clearance` | Body underside above this truck's bed rails | 1 | 1 | VERIFY ON TRUCK |
| `wheel_well_side_clearance` | Tub base to wheel well, each side | 0.75 | 0.75 | VERIFY ON TRUCK |
| `wheel_well_top_clearance` | Tub step above wheel-well top | 1 | 1 | VERIFY ON TRUCK |
| `tailgate_side_clearance` | Tub to tailgate opening, each side | 0.75 | 0.75 | VERIFY ON TRUCK |
| `bed_side_clearance` | Tub to bed side walls, each side | 3.25 | 3.25 | VERIFY ON TRUCK |

## Truck interface (2011 F-350 base values)

| Parameter | Description | Value | Tag | Sheet fig. |
|---|---|---|---|---|
| `truck_bed_floor_height` | Ground to bed floor | 39.5 | VERIFY ON TRUCK | M1 |
| `truck_bed_rail_height` | Bed floor to top of bed rail (bed depth) | 20 | VERIFY ON TRUCK | M2 |
| `truck_bed_floor_width` | Inside bed width at floor (outside the wheel wells) | 66 | VERIFY ON TRUCK | M3 |
| `truck_bed_inner_width_top` | Inside bed width at top of rails | 66 | VERIFY ON TRUCK | M3 |
| `truck_bed_rail_width` | Bed rail top width (each side) | 6.5 | VERIFY ON TRUCK | M3 |
| `truck_tailgate_opening_width` | Tailgate opening width (narrowest point) | 61 | VERIFY ON TRUCK | M5 |
| `truck_tailgate_length` | Tailgate length, hinge to top edge (projects rearward when down) | 20 | VERIFY ON TRUCK | M5 |
| `truck_tailgate_down_offset` | Lowered tailgate top surface above bed floor | 0.5 | VERIFY ON TRUCK | M5 |
| `truck_wheel_well_width` | Clear width between wheel wells | 50.9 | VERIFY ON TRUCK | M3 |
| `truck_wheel_well_height` | Wheel well height above bed floor | 10.5 | VERIFY ON TRUCK | M2 |
| `truck_wheel_well_length` | Wheel well length along bed | 34 | VERIFY ON TRUCK | M2 |
| `truck_cab_height_above_bed` | Bed floor to highest point of cab roof | 41.5 | VERIFY ON TRUCK | M4 |
| `truck_cab_to_bed_clearance` | Gap: bed front wall outer face to cab back | 4 | VERIFY ON TRUCK | M4 |
| `truck_bed_front_wall_thickness` | Bed front wall thickness at the rail | 1.5 | VERIFY ON TRUCK | M4 |
| `truck_cab_width` | Cab width (reference model only) | 79.9 | PRELIMINARY |  |
| `truck_cab_roof_length` | Cab roof length (reference model only) | 58 | PRELIMINARY |  |
| `truck_hood_height_above_bed` | Hood height above bed floor (reference model only) | 18 | PRELIMINARY |  |
| `truck_tire_diameter` | Tire diameter (reference model only) | 33 | PRELIMINARY |  |
| `truck_track_width` | Rear track width (reference model only) | 68 | PRELIMINARY |  |
| `truck_windshield_run` | Windshield horizontal run (reference model only) | 24 | PRELIMINARY |  |
| `truck_front_overhang` | Front axle to front bumper (reference model only) | 38 | PRELIMINARY |  |
| `truck_body_bottom_below_bed` | Bed/cab body bottom below bed floor (reference model only) | 14 | PRELIMINARY |  |
| `truck_beltline_above_bed` | Cab beltline above bed floor (reference model only) | 14 | PRELIMINARY |  |

### All truck variants (fit study only; the camper is sized to F350_LONG)

| Value | F350_LONG | F350_SHORT | F150_65 | F150_55 | TACOMA_6 | TACOMA_5 |
|---|---|---|---|---|---|---|
| `truck_bed_length` | 98 | 81.8 | 78.9 | 67.1 | 73.7 | 60.5 |
| `truck_rear_axle_from_bulkhead` | 51.2 | 35 | 47.9 | 36.1 | 46.2 | 33 |
| `truck_wheelbase` | 172.4 | 156.2 | 157.2 | 145.4 | 140.6 | 127.4 |
| `truck_bed_floor_height` | 39.5 | 39.5 | 35 | 35 | 33 | 33 |
| `truck_bed_rail_height` | 20 | 20 | 21.4 | 21.4 | 19.1 | 19.1 |
| `truck_wheel_well_width` | 50.9 | 50.9 | 50.6 | 50.6 | 41.5 | 41.5 |
| `truck_bed_floor_width` | 66 | 66 | 65.2 | 65.2 | 56.7 | 56.7 |
| `truck_tailgate_opening_width` | 61 | 61 | 60 | 60 | 53 | 53 |
| `truck_cab_height_above_bed` | 41.5 | 41.5 | 42 | 42 | 37.5 | 37.5 |
| camper cargo rating (lb) | 1438-3002 | 1650-2905 | 1300-2440 | 1300-2440 | 1050-1445 | 1050-1445 |

Sources and estimate flags for every value: `truck_data/README.md`. Fit verdicts: `truck_data/fit_study.md`.

## Unresolved dimensions

These cannot be closed until the truck is measured or v0.2 structure exists:

- `camper_lower_tub_width`: Lower tub width (upper step, between rails) (now 59.5)
- `camper_to_cab_clearance`: Nose underside above cab roof (now 4)
- `truck_bed_floor_height`: Ground to bed floor (now 39.5)
- `truck_bed_rail_height`: Bed floor to top of bed rail (bed depth) (now 20)
- `truck_bed_floor_width`: Inside bed width at floor (outside the wheel wells) (now 66)
- `truck_bed_inner_width_top`: Inside bed width at top of rails (now 66)
- `truck_bed_rail_width`: Bed rail top width (each side) (now 6.5)
- `truck_tailgate_opening_width`: Tailgate opening width (narrowest point) (now 61)
- `truck_tailgate_length`: Tailgate length, hinge to top edge (projects rearward when down) (now 20)
- `truck_tailgate_down_offset`: Lowered tailgate top surface above bed floor (now 0.5)
- `truck_wheel_well_width`: Clear width between wheel wells (now 50.9)
- `truck_wheel_well_height`: Wheel well height above bed floor (now 10.5)
- `truck_wheel_well_length`: Wheel well length along bed (now 34)
- `truck_cab_height_above_bed`: Bed floor to highest point of cab roof (now 41.5)
- `truck_cab_to_bed_clearance`: Gap: bed front wall outer face to cab back (now 4)
- `truck_bed_front_wall_thickness`: Bed front wall thickness at the rail (now 1.5)
- `truck_bed_length`, `truck_rear_axle_from_bulkhead`: which bed does the owner's truck have?
- Construction thicknesses (`floor_sandwich`, `wall_thickness`, `roof_thickness`, `nose_floor_thickness`) are PRELIMINARY until the v0.2 frame sections exist.
- Door and window sizes are PRELIMINARY until specific purchased products are selected.

## Rendering color legend

| Element | Color |
|---|---|
| Skin / envelope | silver |
| New frame pieces, roof-rack bosses | blue |
| Utility T-slot rails | dark blue |
| Truck reference | transparent gray |
| Purchased placeholder (door) | charcoal |
| Window placeholder | steel blue |
| Reserved provision zone (power zone, wire chase) | translucent purple |
| 6'7" human reference | tan |

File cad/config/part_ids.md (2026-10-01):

# Part identification

One ID per part, used everywhere: CAD registry, drawings, BOM, cut lists, renderings, manual, cost and
weight reports. `scripts_code/validate_model.py` reads the SYSTEM and LOCATION tables below and fails the
build on a malformed or duplicate ID.

## Grammar

```
SYSTEM-LOCATION-NUMBER
NUMBER = optional role letter + 2 or 3 digits     e.g. 01, 001, V03 (vertical), H01 (horizontal)
regex:  ^[A-Z]{2,5}-[A-Z]{1,4}-[A-Z]?[0-9]{2,3}$
```

## SYSTEM codes

| Code | Meaning | Role |
|---|---|---|
| `FLR` | Floor structure | PRIMARY STRUCTURAL FRAME |
| `WALL` | Wall frame | PRIMARY STRUCTURAL FRAME |
| `ROOF` | Roof frame | PRIMARY STRUCTURAL FRAME |
| `NOSE` | Nose (cab-over) frame | PRIMARY STRUCTURAL FRAME |
| `JACK` | Jack attachment structure | PRIMARY STRUCTURAL FRAME (safety-critical) |
| `TIE` | Truck tie-down structure | PRIMARY STRUCTURAL FRAME (safety-critical) |
| `UTIL` | Owner accessory T-slot rail | OWNER ACCESSORY T-SLOT RAIL (not primary structure) |
| `SKIN` | Exterior skin panel | Bonded shear diaphragm |
| `ENV` | Envelope solid (v0.1 only) | Reference geometry |
| `DOOR` | Door (purchased) | Purchased component |
| `WIN` | Window (purchased) | Purchased component |
| `RACK` | Roof-rack mounting boss | Structural provision (ADR 0003) |
| `BRKT` | Bracket / gusset / joining plate | Joint hardware |

## LOCATION codes

| Code | Meaning |
|---|---|
| `L` / `R` | Left (driver, +Y) / right (passenger, -Y) |
| `F` / `B` | Front (toward cab) / back (rear) |
| `X` | Transverse crossmember |
| `LF` `RF` `LR` `RR` | Corners: left-front, right-front, left-rear, right-rear |
| `N` | Nose |
| `C` | Centerline |
| `ROOF` | Roof surface |
| `TUB` `BODY` `NOSE` | Envelope regions (ENV only) |

`B` is used for "rear" so that `R` always means right.

## Examples

```
FLR-L-001  FLR-R-001  FLR-X-001        floor longitudinal / rail / crossmember
WALL-L-V01  WALL-L-H01                 wall vertical / horizontal
ROOF-X-01   NOSE-L-01
UTIL-L-01  UTIL-R-02  UTIL-F-01        owner accessory T-slot rails
JACK-LF-01  JACK-RF-01  JACK-LR-01  JACK-RR-01
SKIN-L-01  SKIN-R-01  SKIN-ROOF-01  SKIN-NOSE-02  SKIN-B-01
ENV-TUB-01  DOOR-B-01  WIN-N-01  RACK-ROOF-03
```

A member may serve as both PRIMARY STRUCTURAL FRAME and OWNER ACCESSORY T-SLOT RAIL only deliberately,
with a `note` in its `frame_member()` call explaining why.

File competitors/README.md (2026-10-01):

# Competitors

Reference points for MINUTEMAN, a DIY aluminum **shell**. Every competitor below sells a finished or
near-finished camper, so the comparisons are about construction, weight class, and what an empty
shell costs, not about features MINUTEMAN deliberately leaves out.

All figures are as published by the cited source on the access date. They vary by model year and
options, so treat them as order-of-magnitude. **Accessed 2026-10-01 unless noted.**

| File | Covers |
|---|---|
| [kimbo.md](kimbo.md) | Kimbo: closest analog (riveted 5052 aluminum hard-side) |
| [aluminum_campers.md](aluminum_campers.md) | Four Wheel Camper, Alaskan Camper |
| [composite_campers.md](composite_campers.md) | Total Composites, Scout Campers |
| [diy_builds.md](diy_builds.md) | Owner-built aluminum campers and the techniques they used |
| [modular_shells.md](modular_shells.md) | "Empty shell" offerings and what they include |
| [comparison_matrix.csv](comparison_matrix.csv) | Side-by-side numbers |

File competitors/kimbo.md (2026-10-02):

# Kimbo Campers

**Why it matters:** Kimbo is the closest commercial analog to MINUTEMAN: a hard-side aluminum slide-in
built from riveted 5052 sheet, sold with a stripped "base" option.

| | Kimbo 6 | Kimbo 8 |
|---|---|---|
| Construction | Frameless, hand-riveted 5052 aluminum monocoque | Riveted aluminum shell, hemmed edges, R10 insulation |
| Dry weight | 830 lb (empty shell, early listing); 980-1,200 lb (current buyer's guide, by build) | ~1,275 lb (est.) |
| Price | From $20,999 (base) / $24,999 (2026 Series 6 MSRP); earlier listing $27,990 | not confirmed |

Sources (accessed 2026-10-01):
- Truck Camper Magazine, Kimbo buyer's guide: https://www.truckcampermagazine.com/buyers-guide/hard-side/kimbo-buyers-guide/
- Truck Camper Magazine, "Announcing the Kimbo Series 6": https://www.truckcampermagazine.com/news/announcing-the-kimbo-series-6/
- Tiny House Talk, "Kimbo 6 hard side truck camper, $27,990, 830 lb dry": https://tinyhousetalk.com/kimbo-6-hard-side-truck-camper-27990-830-lb-dry/
- MensGear, Kimbo 8: https://mensgear.net/kimbo-8-camper/

## Lessons for MINUTEMAN
- **Monocoque riveted 5052 works** for a hard-side at this scale. That supports treating the skin as a
  structural shear diaphragm (A-004), though Kimbo rivets where MINUTEMAN bonds plus rivets.
- An empty Kimbo 6 shell lands around 830 lb. That is below MINUTEMAN's 985-1,231 lb
  estimate. Kimbo 6 is built for 6 ft beds, so it is a smaller camper. It is a sanity check that our
  estimate is not wildly off, and a reminder that our 80 in interior costs weight.
- Price discrepancies between sources are large; confirm with the manufacturer before using these in any
  business case.

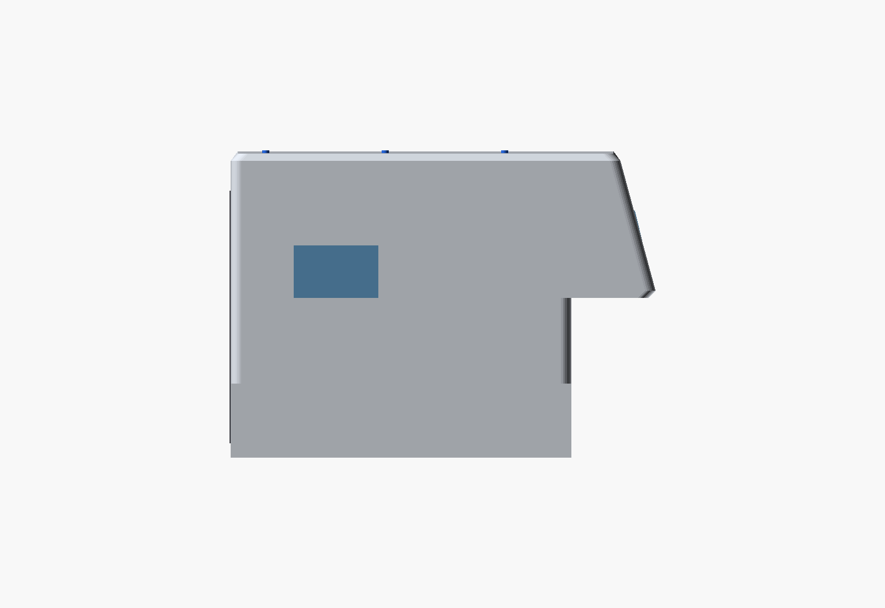
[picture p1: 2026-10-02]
3D_renderings/exterior/04_right.png

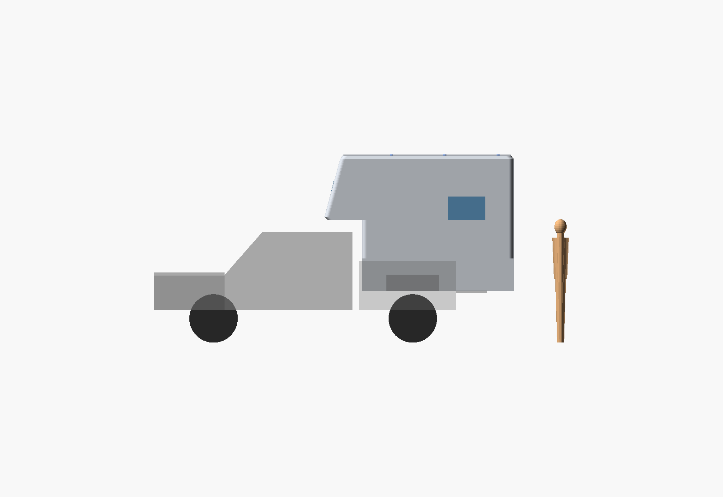
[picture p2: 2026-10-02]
3D_renderings/fit_study/04_tacoma_5ft.png

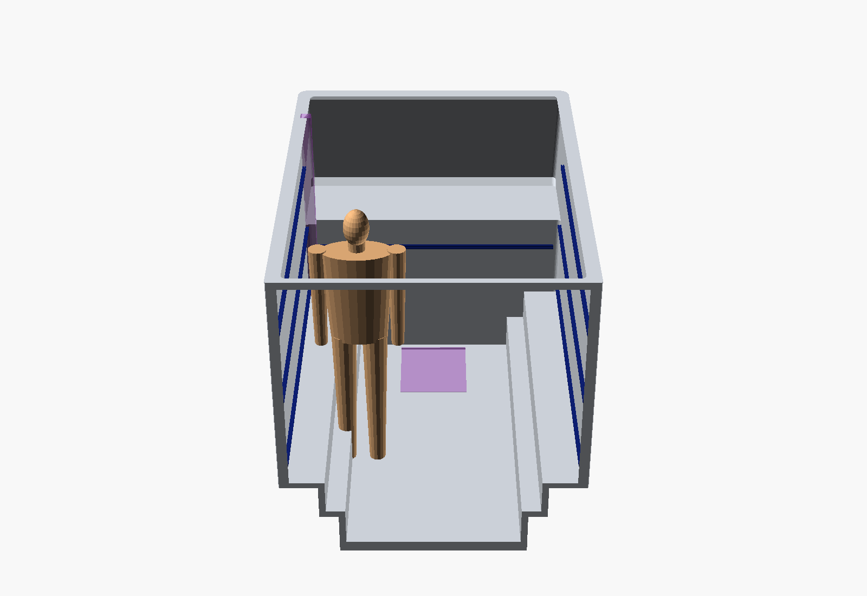
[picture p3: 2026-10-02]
3D_renderings/interior_shell/01_utility_rails.png

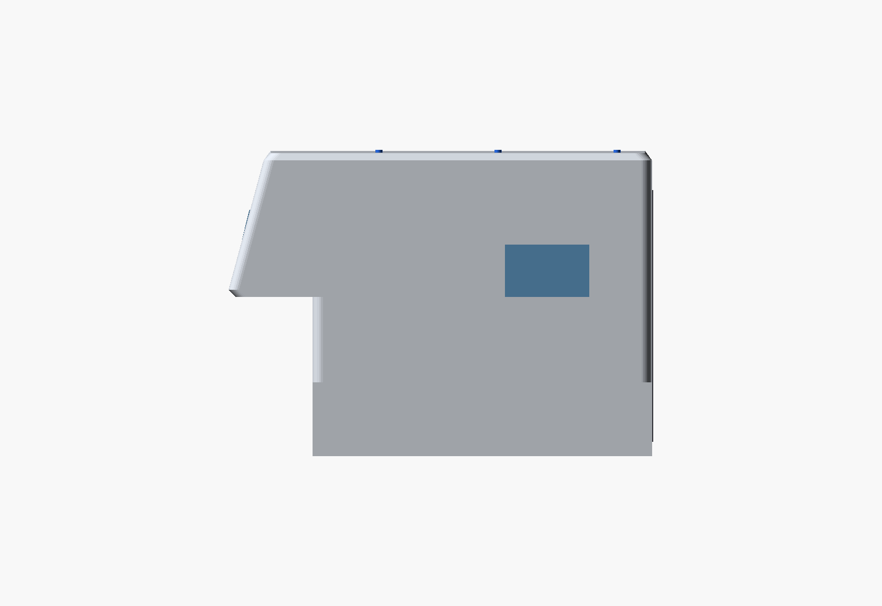
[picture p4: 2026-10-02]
3D_renderings/exterior/03_left.png

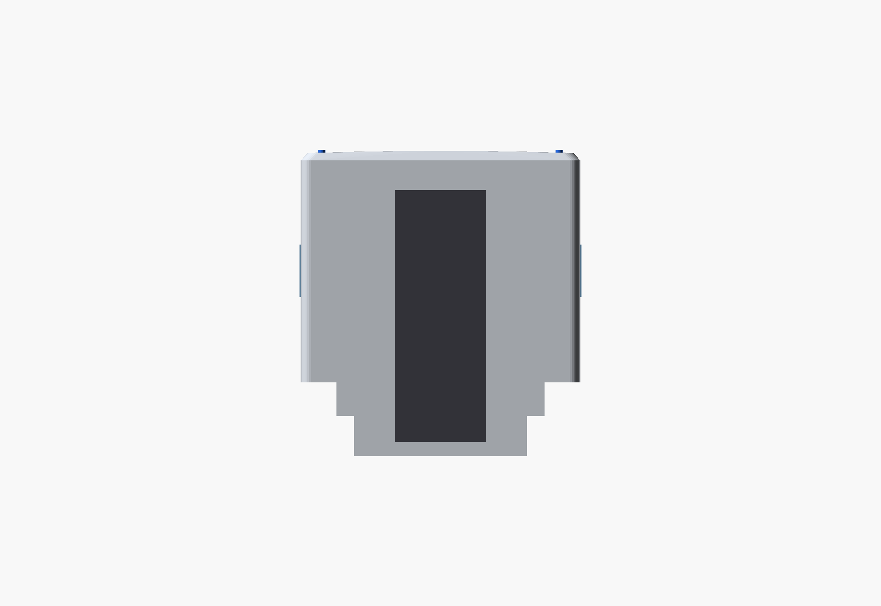
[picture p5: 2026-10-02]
3D_renderings/exterior/06_rear.png

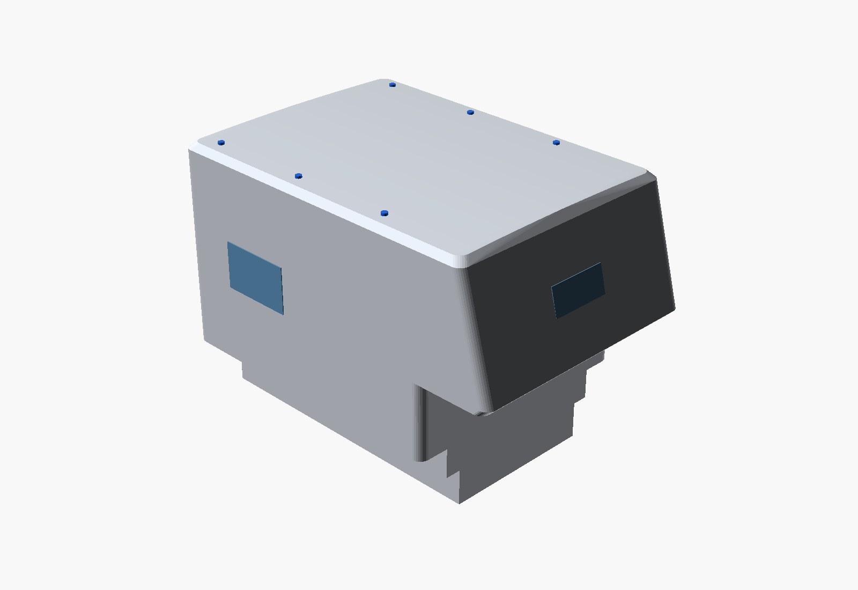
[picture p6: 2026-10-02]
3D_renderings/exterior/02_front_iso.png

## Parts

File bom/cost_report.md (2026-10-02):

<!-- GENERATED by scripts_code/generate_cost_report.py from cad/config/dimensions.json - DO NOT HAND-EDIT -->
# Cost report - v0.1 envelope

**Status: CONCEPT estimate.** Unit prices in `time_cost/material_costs.csv`; none are quotes yet.

| Item | Low ($) | High ($) | Basis |
|---|---:|---:|---|
| 5052 skin sheet (11 sheets 4x8) | 1,430 | 2,530 | area x waste / 32 ft2 |
| 6061 tube | 1,047 | 2,337 | tube mass 349-467 lb |
| T-slot utility rails | 305 | 610 | 610 in total |
| Rear door | 400 | 900 | purchased |
| Windows (3) | 300 | 600 | purchased |
| Roof-rack bosses (6) | 48 | 120 | provision |
| Insulation | 161 | 264 | 293 ft2 |
| Interior panel | 211 | 425 | 293 ft2 |
| Adhesive + sealant | 150 | 300 | lot |
| Fasteners + rivets | 200 | 350 | lot |
| Welding consumables + gas | 150 | 300 | lot |
| **Shell materials, excl. jacks and tooling** | **4,402** | **8,735** | |
| Jacks (4), tracked separately | 900 | 1,600 | |
| One-time tooling (`tooling_costs.csv`) | 1,510 | 3,250 | not shell cost |

## Against the target

Owner target: $4,000-$6,000 ("high-end truck topper"). Estimate: **$4,402-$8,735** excluding jacks and tooling.

The low half of the range fits the target; the high half does not. The largest line is **5052 skin sheet (11 sheets 4x8)** (up to $2,530). 6061 tube is priced at a realistic retail $/lb, which is above the handoff's first-pass $500-900 tube figure; get local quotes before trusting either number.

## Sensitivity: interior height

Each +1 in of interior_height adds **$26-50** (and 5.8-7.0 lb).

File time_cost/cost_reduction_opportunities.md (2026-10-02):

# Cost reduction opportunities

Current estimate: **$4,402-8,735** shell materials, excluding jacks ($900-1,600) and tooling
(`bom/cost_report.md`). Target: $4,000-6,000.

## The real levers
1. **Skin gauge: 0.040 in on walls, 0.050 in reserved for the roof.** Skin is the largest single line
   (11 sheets, $1,430-2,530). 0.040 in walls cut skin weight ~20% on those faces and lower sheet cost.
   Trade-off: dent resistance and oil-canning, so test a panel before committing.
2. **Bigger sheets / coil stock.** 5x10 sheets eliminate seams on the roof and reduce offcuts on most
   faces. **Caveat found in v0.1:** at 80 in interior the body sides are 65.5 in tall, taller than a 60 in
   wide sheet, so sides still need a seam unless 72 in wide coil/sheet is sourced (`bom/sheet_cutlist.csv`).
3. **Surplus and remnant sourcing** of 6061 tube and 5052 sheet (metal recyclers, remnant racks, trailer
   manufacturers' drops). Tube is the second-biggest line ($1,047-2,337) and the most remnant-friendly.
4. **A commercial cargo-trailer door** instead of fabricating one ($400-900 bought vs. many hours and a
   sealing risk).
5. **Fewer windows:** the nose window is optional (`WINDOW_NOSE_ENABLED`), saving $100-200.
6. **Interior panel material choice**, which also moves weight (105-135 lb).
7. **Interior height:** each inch is ~$26-50 and ~6-7 lb (`bom/weight_report.md`). This is a requirement, not
   a lever, but the price is visible.

8. **Length:** the 97 in full-bed length (ADR 0004) is the single biggest driver of the increase from v0.1
   (+$500-800, +130-160 lb vs. 78 in). A shorter camper is also what makes the 6.75 ft bed safe.

## Where cost must NOT be cut
- **Jack structures** and their attachment into the frame.
- **Tie-down nodes** and the truck-side anchors.
- **Floor structure.**
- **Adhesive quality** and surface prep: the skin is a structural diaphragm.
- Galvanic isolation hardware and sealants: cheap, and failures are expensive.

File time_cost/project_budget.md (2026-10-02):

# Project budget (v0.1 estimate)

| Bucket | Low ($) | High ($) | Source |
|---|---:|---:|---|
| Shell materials | 4,402 | 8,735 | bom/cost_report.md |
| Camper jacks (4) | 900 | 1,600 | time_cost/material_costs.csv |
| One-time tooling | 1,510 | 3,250 | time_cost/tooling_costs.csv |
| **Total cash** | **6,812** | **13,585** | |
| Owner labor | 163 h | 314 h | time_cost/labor_estimate.csv |

Status: CONCEPT. None of these numbers are quotes. Tooling keeps its value after the build.
Contingency is not included; a 15-20% contingency on materials is prudent for a first build.

The numbers above are copied from the generated reports on 2026-10-01; if they disagree, the reports win.

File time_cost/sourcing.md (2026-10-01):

# Sourcing (to be filled with quotes)

| Item | Where to ask | Notes |
|---|---|---|
| 5052-H32 sheet 0.040/0.050 | Local metal service centers; online (e.g., OnlineMetals, Metals Depot) | Ask for 5x10 and 72 in wide coil pricing |
| 6061-T6 tube | Same, plus remnant racks and scrap yards | Remnants are the biggest saving |
| T-slot extrusion | 80/20 (and its surplus eBay store), Misumi, Tnutz | 1010 class |
| Structural adhesive | Sika, 3M, Lord/Parker, ITW Plexus | Get technical datasheets into `reference/adhesives/` |
| Door / windows | RV and cargo-trailer suppliers | Choose before v0.3 so openings match |
| Jacks | Truck-camper jack makers (e.g., Rieco-Titan, Atwood/Dometic, Happijac) | Bracket geometry drives v0.2 corner nodes |
| Argon | Local welding supply | Lease vs. own |

No quotes yet. Record each quote with date and supplier in `material_costs.csv` `source` column.

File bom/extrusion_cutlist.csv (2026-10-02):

# GENERATED by scripts_code/generate_cutlist.py from cad/config/dimensions.json - DO NOT HAND-EDIT
id | profile | cut_length_in | end_cuts | qty | role | note
UTIL-L-01 | TSLOT_1010 | 89.500 | SQUARE | 1 | OWNER ACCESSORY T-SLOT RAIL | Must bolt into frame members, never skin-only (v0.2)
UTIL-L-02 | TSLOT_1010 | 89.500 | SQUARE | 1 | OWNER ACCESSORY T-SLOT RAIL | Must bolt into frame members, never skin-only (v0.2)
UTIL-L-03 | TSLOT_1010 | 89.500 | SQUARE | 1 | OWNER ACCESSORY T-SLOT RAIL | Must bolt into frame members, never skin-only (v0.2)
UTIL-R-01 | TSLOT_1010 | 89.500 | SQUARE | 1 | OWNER ACCESSORY T-SLOT RAIL | Must bolt into frame members, never skin-only (v0.2)
UTIL-R-02 | TSLOT_1010 | 89.500 | SQUARE | 1 | OWNER ACCESSORY T-SLOT RAIL | Must bolt into frame members, never skin-only (v0.2)
UTIL-R-03 | TSLOT_1010 | 89.500 | SQUARE | 1 | OWNER ACCESSORY T-SLOT RAIL | Must bolt into frame members, never skin-only (v0.2)
UTIL-F-01 | TSLOT_1010 | 72.500 | SQUARE | 1 | OWNER ACCESSORY T-SLOT RAIL | Must bolt into frame members, never skin-only (v0.2)
TOTAL |  | 610.4 |  | 7 |  | incl. 0.125 in kerf per cut

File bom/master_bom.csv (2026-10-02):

# GENERATED by scripts_code/generate_bom.py from cad/config/dimensions.json - DO NOT HAND-EDIT
id | kind | role | qty | profile | material | length_in | size_in | mass_lb | join | cost_key | status | note
ENV-TUB-01 | ENVELOPE | LOWER TUB ENVELOPE | 1 |  |  |  | 97x59.5x21 |  |  |  | CONCEPT | Stepped: base width tub_base_width to tub_step_z
ENV-BODY-01 | ENVELOPE | MAIN BODY ENVELOPE | 1 |  |  |  | 97x80x65.5 |  |  |  | CONCEPT
ENV-NOSE-01 | ENVELOPE | NOSE ENVELOPE | 1 |  |  |  | 24x80x41 |  |  |  | CONCEPT | Storage/desk volume; not a sleeping platform
ENV-ROOF-01 | ENVELOPE | ROOF ENVELOPE | 1 |  |  |  | 111x80x4.25 |  |  |  | CONCEPT | Transverse crown 0.75 in
DOOR-B-01 | PURCHASED | REAR ENTRY DOOR PLACEHOLDER | 1 |  |  |  | 0.4x26x72 |  |  | door | CONCEPT | Rough opening; select commercial door then update dimensions.json
WIN-L-01 | PURCHASED | SIDE WINDOW PLACEHOLDER | 1 |  |  |  | 24x0.3x15 |  |  | window | CONCEPT
WIN-R-01 | PURCHASED | SIDE WINDOW PLACEHOLDER | 1 |  |  |  | 24x0.3x15 |  |  | window | CONCEPT
WIN-N-01 | PURCHASED | NOSE WINDOW PLACEHOLDER (OPTIONAL) | 1 |  |  |  | 0.3x20x9 |  |  | window | CONCEPT
RACK-ROOF-01 | PROVISION | ROOF-RACK MOUNTING BOSS | 1 |  |  |  | 2x2x0.75 |  |  | rack_boss | CONCEPT | Must land on a roof crossmember in v0.2
RACK-ROOF-02 | PROVISION | ROOF-RACK MOUNTING BOSS | 1 |  |  |  | 2x2x0.75 |  |  | rack_boss | CONCEPT | Must land on a roof crossmember in v0.2
RACK-ROOF-03 | PROVISION | ROOF-RACK MOUNTING BOSS | 1 |  |  |  | 2x2x0.75 |  |  | rack_boss | CONCEPT | Must land on a roof crossmember in v0.2
RACK-ROOF-04 | PROVISION | ROOF-RACK MOUNTING BOSS | 1 |  |  |  | 2x2x0.75 |  |  | rack_boss | CONCEPT | Must land on a roof crossmember in v0.2
RACK-ROOF-05 | PROVISION | ROOF-RACK MOUNTING BOSS | 1 |  |  |  | 2x2x0.75 |  |  | rack_boss | CONCEPT | Must land on a roof crossmember in v0.2
RACK-ROOF-06 | PROVISION | ROOF-RACK MOUNTING BOSS | 1 |  |  |  | 2x2x0.75 |  |  | rack_boss | CONCEPT | Must land on a roof crossmember in v0.2
UTIL-L-01 | MEMBER | OWNER ACCESSORY T-SLOT RAIL | 1 | TSLOT_1010 | AL6105T5 | 89.5 | 89.5x1x1 | 3.8 | BOLTED | TSLOT_1010 | CONCEPT | Must bolt into frame members, never skin-only (v0.2)
UTIL-L-02 | MEMBER | OWNER ACCESSORY T-SLOT RAIL | 1 | TSLOT_1010 | AL6105T5 | 89.5 | 89.5x1x1 | 3.8 | BOLTED | TSLOT_1010 | CONCEPT | Must bolt into frame members, never skin-only (v0.2)
UTIL-L-03 | MEMBER | OWNER ACCESSORY T-SLOT RAIL | 1 | TSLOT_1010 | AL6105T5 | 89.5 | 89.5x1x1 | 3.8 | BOLTED | TSLOT_1010 | CONCEPT | Must bolt into frame members, never skin-only (v0.2)
UTIL-R-01 | MEMBER | OWNER ACCESSORY T-SLOT RAIL | 1 | TSLOT_1010 | AL6105T5 | 89.5 | 89.5x1x1 | 3.8 | BOLTED | TSLOT_1010 | CONCEPT | Must bolt into frame members, never skin-only (v0.2)
UTIL-R-02 | MEMBER | OWNER ACCESSORY T-SLOT RAIL | 1 | TSLOT_1010 | AL6105T5 | 89.5 | 89.5x1x1 | 3.8 | BOLTED | TSLOT_1010 | CONCEPT | Must bolt into frame members, never skin-only (v0.2)
UTIL-R-03 | MEMBER | OWNER ACCESSORY T-SLOT RAIL | 1 | TSLOT_1010 | AL6105T5 | 89.5 | 89.5x1x1 | 3.8 | BOLTED | TSLOT_1010 | CONCEPT | Must bolt into frame members, never skin-only (v0.2)
UTIL-F-01 | MEMBER | OWNER ACCESSORY T-SLOT RAIL | 1 | TSLOT_1010 | AL6105T5 | 72.5 | 72.5x1x1 | 3.08 | BOLTED | TSLOT_1010 | CONCEPT | Must bolt into frame members, never skin-only (v0.2)

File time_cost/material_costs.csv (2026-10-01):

cost_key | description | unit | low_usd | high_usd | basis | status | source
skin_sheet | 5052-H32 sheet 0.050 x 48 x 96 | sheet | 130 | 230 | sheet count from envelope area x nesting waste | CONCEPT | First-pass estimate (PROJECT_HANDOFF.md 2.4); get local metal-supplier quotes
tube_6061 | 6061-T6 tube, mixed sizes | lb | 3.00 | 5.00 | applied to estimated tube mass (wall+roof+nose frames + floor_tube_fraction of floor) | CONCEPT | Typical retail ~$2-3/ft for 1x1x1/8 (~0.51 lb/ft); low end assumes bulk/remnant. Get quotes.
TSLOT_1010 | 1010-class T-slot extrusion incl. end fasteners | in | 0.50 | 1.00 | cut length from parts registry | CONCEPT | First-pass estimate ($6-12/ft)
door | Commercial cargo-trailer / RV entry door | each | 400 | 900 | one rear door | CONCEPT | First-pass estimate
window | RV / trailer window | each | 100 | 200 | count from parts registry | CONCEPT | First-pass estimate
rack_boss | Roof-rack mounting boss (machined/bought insert + sealing) | each | 8 | 20 | count from parts registry | CONCEPT | First-pass estimate; not in handoff subtotal
insulation | XPS foam board 1.5 in | ft2 | 0.55 | 0.90 | insulated envelope area | CONCEPT | First-pass estimate
interior_panel | Interior protective panel | ft2 | 0.72 | 1.45 | insulated envelope area | CONCEPT | First-pass estimate
adhesive | Structural adhesive + sealant | lot | 150 | 300 | lot | CONCEPT | First-pass estimate
fasteners | Fasteners and rivets | lot | 200 | 350 | lot | CONCEPT | First-pass estimate
welding_consumables | ER5356 wire, argon refills, tips | lot | 150 | 300 | lot | CONCEPT | First-pass estimate
jacks | Camper jack set (4) | set | 900 | 1600 | tracked separately, excluded from shell subtotal | CONCEPT | First-pass estimate

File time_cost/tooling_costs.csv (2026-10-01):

item | description | low_usd | high_usd | status | note
welder | 200-230 A MIG with spool gun (e.g. Hobart 210MVP + SpoolRunner 100, Eastwood MIG 180, Primeweld MIG 230) | 800 | 1400 | CONCEPT | ADR 0001. One-time tooling; never in shell material cost
argon_cylinder | Argon cylinder purchase or lease (80-125 cf) | 200 | 400 | CONCEPT | 100% argon at 25-35 CFH
saw | Carbide-blade cold/miter saw for aluminum | 150 | 450 | CONCEPT | Non-ferrous blade
rivet_tool | Pneumatic or long-handle structural rivet tool | 60 | 250 | CONCEPT
drill_set | Drill, step bits, cobalt bits, deburring tools | 80 | 200 | CONCEPT
clamps_squares | Welding/assembly clamps, magnetic squares | 100 | 250 | CONCEPT
ppe | Auto-darkening helmet, gloves, respirator | 120 | 300 | CONCEPT

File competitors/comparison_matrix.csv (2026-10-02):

product | type | construction | dry_weight_lb_low | dry_weight_lb_high | price_usd_low | price_usd_high | interior_standing | source_url | accessed
MINUTEMAN v0.1 rev B (estimate) | DIY hard-side shell | 6061 frame (hybrid weld/bolt) + bonded 5052 skin | 985 | 1231 | 4402 | 8735 | 80 in clear | bom/weight_report.md; bom/cost_report.md | 2026-10-01
Kimbo 6 | hard-side | riveted 5052 monocoque | 830 | 1200 | 20999 | 27990 |  | https://www.truckcampermagazine.com/buyers-guide/hard-side/kimbo-buyers-guide/ | 2026-10-01
Kimbo 8 | hard-side | riveted aluminum shell | 1275 | 1275 |  |  |  | https://mensgear.net/kimbo-8-camper/ | 2026-10-01
Four Wheel Camper Hawk | pop-up | welded aluminum frame, aluminum roof/siding | 1100 | 1200 | 19995 | 29495 | popped up only | https://fourwheelcampers.com/model/hawk-model-pop-up-truck-camper-leader-full-size-trucks/hawk-base-model/ | 2026-10-01
Alaskan 8 ft cabover | telescoping hard-side | hard walls, hydraulic lift | 1390 | 1985 | 37190 | 42090 | raised only | https://www.truckcampermagazine.com/buyers-guide/alaskan-hard-side-buyers-guide/ | 2026-10-01
Total Composites Lynx 7' | hard-side shell | FRP + PU foam sandwich | 606 | 606 | 17959 | 17959 |  | https://www.truckcampermagazine.com/buyers-guide/hard-side/total-composites-buyers-guide/ | 2026-10-01
Scout Yoho | hard-side | composite panels + aluminum exoskeleton | 913 | 913 | 19240 | 19240 |  | https://newatlas.com/outdoors/scout-yoho-lightest-pickup-camper/ | 2026-10-01
Scout Olympic | hard-side | composite panels + aluminum exoskeleton | 1165 | 1165 | 19980 | 19980 |  | https://www.truckcampermagazine.com/buyers-guide/hard-side/scout-camper-buyers-guide/ | 2026-10-01

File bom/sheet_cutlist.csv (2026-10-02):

# GENERATED by scripts_code/generate_cutlist.py from cad/config/dimensions.json - DO NOT HAND-EDIT
# PRELIMINARY: flat-pattern envelope faces | corner radii and laps ignored. Panel splits are v0.3.
id | description | width_in | height_in | net_area_in2 | group | fits_4x8 | fits_5x10
SKIN-L-01 | Left body side | 97.0 | 65.5 | 5993.5 | walls | no (seam) | no (seam)
SKIN-L-02 | Left nose side (trapezoid) | 24.0 | 41.0 | 779.0 | nose | yes | yes
SKIN-L-03 | Left tub side, upper | 97.0 | 9.5 | 921.5 | walls | no (seam) | yes
SKIN-L-04 | Left tub side, lower | 97.0 | 11.5 | 1115.5 | walls | no (seam) | yes
SKIN-L-05 | Left tub step ledge | 97.0 | 5.05 | 489.9 | walls | no (seam) | yes
SKIN-L-06 | Left body underside overhang | 97.0 | 10.25 | 994.2 | walls | no (seam) | yes
SKIN-R-01 | Right body side | 97.0 | 65.5 | 5993.5 | walls | no (seam) | no (seam)
SKIN-R-02 | Right nose side (trapezoid) | 24.0 | 41.0 | 779.0 | nose | yes | yes
SKIN-R-03 | Right tub side, upper | 97.0 | 9.5 | 921.5 | walls | no (seam) | yes
SKIN-R-04 | Right tub side, lower | 97.0 | 11.5 | 1115.5 | walls | no (seam) | yes
SKIN-R-05 | Right tub step ledge | 97.0 | 5.05 | 489.9 | walls | no (seam) | yes
SKIN-R-06 | Right body underside overhang | 97.0 | 10.25 | 994.2 | walls | no (seam) | yes
SKIN-F-01 | Front tub face (stepped) | 59.5 | 21.0 | 1133.3 | walls | yes | yes
SKIN-F-02 | Front body face below nose | 80.0 | 24.5 | 1960.0 | walls | yes | yes
SKIN-NOSE-01 | Nose underside | 80.0 | 24.0 | 1920.0 | nose | yes | yes
SKIN-NOSE-02 | Nose raked front face | 80.0 | 42.2 | 3196.2 | nose | yes | yes
SKIN-B-01 | Rear face incl. tub (door cut out) | 80.0 | 86.5 | 4501.4 | walls | no (seam) | no (seam)
SKIN-ROOF-01 | Roof | 111.0 | 80.0 | 8880.0 | roof | no (seam) | no (seam)
TOTAL |  |  |  | 42178.1 |  | 11-11 sheets 4x8 incl. waste

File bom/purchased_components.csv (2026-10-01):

# GENERATED by scripts_code/generate_bom.py from cad/config/dimensions.json - DO NOT HAND-EDIT
id | description | qty | unit_low_usd | unit_high_usd | status | note
DOOR-B-01 | Commercial cargo-trailer / RV entry door | 1 | 400 | 900 | CONCEPT | Rough opening; select commercial door then update dimensions.json
WIN-L-01 | RV / trailer window | 1 | 100 | 200 | CONCEPT
WIN-R-01 | RV / trailer window | 1 | 100 | 200 | CONCEPT
WIN-N-01 | RV / trailer window | 1 | 100 | 200 | CONCEPT
JACK-SET | Camper jack set (4) | 1 | 900 | 1600 | CONCEPT | Tracked separately from shell cost; jack structures JACK-LF/RF/LR/RR-01 are v0.2

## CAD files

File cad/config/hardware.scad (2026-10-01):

// Hardware catalog (v0.1: definitions only; no fasteners are placed in the envelope model).
// [id, description, nominal_dia_in, length_in, material, galvanic_note]
HARDWARE = [
    ["HW-TNUT-1420",  "1/4-20 drop-in T-nut, 10-series slot", 0.25, 0.0,  "AL6061T6", "Same-metal; no isolation needed"],
    ["HW-BOLT-1420-50","1/4-20 x 1/2 FBHCS, stainless 18-8",  0.25, 0.50, "SS304",    "Stainless on aluminum: Tef-Gel or Duralac on threads"],
    ["HW-BOLT-516-275","5/16-18 x 2.75 hex bolt, stainless",  0.3125,2.75,"SS304",    "Stainless on aluminum: nylon isolation washers + Tef-Gel"],
    ["HW-RIV-316-AL",  "3/16 structural blind rivet, aluminum", 0.1875,0.0,"AL5056",   "Same-metal; seal head with polyurethane sealant"]
];

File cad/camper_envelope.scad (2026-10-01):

// v0.1 camper envelope: stepped lower tub, main body, raked nose, crowned roof.
// Envelope solids only - no frame. All dimensions from config/dimensions.scad.
//
// The same builders produce the outer envelope (inset 0) and the interior volume (inset by wall /
// roof / floor thickness), so the hollow shell used for interior views stays consistent.

ENV_EPS = 0.01;
ROOF_R = (pow(camper_body_width, 2) / 4 + pow(roof_crown, 2)) / (2 * roof_crown);  // crown arc radius
CROWN_STEPS = 6;

// Plan-view rounded rectangle slab between x0..x1, width w, thickness h, base at z.
module rrect_slab(x0, x1, w, r, z, h = ENV_EPS) {
    rr = max(min(r, w / 2 - ENV_EPS, (x1 - x0) / 2 - ENV_EPS), ENV_EPS);
    translate([0, 0, z]) hull() for (x = [x0 + rr, x1 - rr], y = [-w / 2 + rr, w / 2 - rr])
        translate([x, y, 0]) cylinder(r = rr, h = h, $fn = 32);
}

// Crown height above eave at lateral offset y (circular arc).
function crown_dz(y) = sqrt(pow(ROOF_R, 2) - y * y) - (ROOF_R - roof_crown);

module tub_lower(t = 0, tf = 0) {
    translate([camper_rear_x + t, -(tub_base_width / 2 - t), tf])
        cube([camper_lower_length - 2 * t, tub_base_width - 2 * t, tub_step_z + t - tf]);
}

module tub_upper(t = 0) {
    translate([camper_rear_x + t, -(camper_lower_tub_width / 2 - t), tub_step_z + t])
        cube([camper_lower_length - 2 * t, camper_lower_tub_width - 2 * t,
              camper_lower_tub_height - tub_step_z + ENV_EPS]);
}

// Main body below the nose underside: plan rounded rectangle, full width.
module body_lower(t = 0) {
    w = camper_body_width - 2 * t;
    hull() {
        rrect_slab(camper_rear_x + t, camper_front_x - t, w, body_corner_radius - t, camper_lower_tub_height + t);
        rrect_slab(camper_rear_x + t, camper_front_x - t, w, body_corner_radius - t,
                   nose_bottom_z + (t > 0 ? nose_floor_thickness + ENV_EPS : 0));
    }
}

// Body above the nose underside, including the nose and the crowned roof (convex hull).
module body_upper(t = 0, tr = 0) {
    w = camper_body_width - 2 * t;
    r = body_corner_radius - t;
    e = roof_edge_radius;
    x0 = camper_rear_x + t;
    xb = nose_front_x - t;                       // lower nose edge
    xt = nose_front_x - nose_top_setback - t;    // top of raked nose face
    z0 = nose_bottom_z + (t > 0 ? nose_floor_thickness : 0);
    ze = roof_eave_z - tr;
    hull() {
        rrect_slab(x0, xb - e, w, r, z0);
        rrect_slab(x0, xb, w, r, z0 + e);
        rrect_slab(x0, xt, w, r, ze - e);
        // crowned roof: stacked slabs following the arc, inset at the eave for an edge radius
        for (i = [0 : CROWN_STEPS - 1]) let(y = (w / 2 - e) * (1 - i / CROWN_STEPS))
            rrect_slab(x0 + e, xt - e, 2 * y, r, ze + crown_dz(y) * (tr > 0 ? 0 : 1));
        rrect_slab(x0 + e, xt - e, 2, 0, ze + (tr > 0 ? 0 : roof_crown));
    }
}

module envelope_outer() {
    color(COLOR_SKIN) union() { tub_lower(); tub_upper(); body_lower(); body_upper(); }
}

module envelope_inner() {
    t = wall_thickness;
    union() {
        tub_lower(t, interior_floor_z);
        tub_upper(t);
        body_lower(t);
        body_upper(t, roof_thickness);
    }
}

// Hollow shell. cut_roof / cut_rear remove the roof and rear wall for interior views.
module envelope_shell(cut_roof = false, cut_rear = false, cut_left = false) {
    big = 400;
    color(COLOR_SKIN) difference() {
        union() { tub_lower(); tub_upper(); body_lower(); body_upper(); }
        envelope_inner();
        if (cut_roof) translate([-big / 2, -big / 2, ceiling_z - ENV_EPS]) cube(big);
        if (cut_rear) translate([camper_rear_x - big + wall_thickness + ENV_EPS, -big / 2, -1]) cube(big);
        if (cut_left) translate([-big / 2, 0, -1]) cube(big);
    }
}

module envelope_registry() {
    part_echo("ENV-TUB-01", "ENVELOPE", "LOWER TUB ENVELOPE", size = [camper_lower_length, camper_lower_tub_width, camper_lower_tub_height],
              position = [camper_rear_x, 0, 0], status = "CONCEPT", note = "Stepped: base width tub_base_width to tub_step_z");
    part_echo("ENV-BODY-01", "ENVELOPE", "MAIN BODY ENVELOPE", size = [camper_lower_length, camper_body_width, roof_eave_z - camper_lower_tub_height],
              position = [camper_rear_x, 0, camper_lower_tub_height], status = "CONCEPT");
    part_echo("ENV-NOSE-01", "ENVELOPE", "NOSE ENVELOPE", size = [nose_projection, camper_body_width, roof_eave_z - nose_bottom_z],
              position = [camper_front_x, 0, nose_bottom_z], status = "CONCEPT", note = "Storage/desk volume; not a sleeping platform");
    part_echo("ENV-ROOF-01", "ENVELOPE", "ROOF ENVELOPE", size = [overall_length - nose_top_setback, camper_body_width, roof_thickness + roof_crown],
              position = [camper_rear_x, 0, ceiling_z], status = "CONCEPT", note = str("Transverse crown ", roof_crown, " in"));
}

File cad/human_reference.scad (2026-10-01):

// 6'7" (79 in) human reference figure, feet at local z = 0, facing +X.
module human(h = human_height) {
    u = h / 8;  // head-height unit
    color(COLOR_HUMAN) {
        translate([0, 0, h - u / 2]) scale([0.8, 0.7, 1]) sphere(d = u, $fn = 24);                // head
        translate([0, 0, h - u * 1.15]) cylinder(d = u * 0.45, h = u * 0.3, $fn = 16);           // neck
        hull() {                                                                              // torso
            translate([0, 0, u * 4.1]) scale([0.55, 1, 1]) cylinder(d = u * 1.55, h = 0.1, $fn = 24);
            translate([0, 0, u * 6.8]) scale([0.55, 1, 1]) cylinder(d = u * 1.95, h = 0.1, $fn = 24);
        }
        for (s = [-1, 1]) {
            translate([0, s * u * 0.42, 0]) cylinder(d1 = u * 0.45, d2 = u * 0.7, h = u * 4.2, $fn = 16);   // legs
            translate([0, s * u * 1.05, u * 3.9]) cylinder(d1 = u * 0.35, d2 = u * 0.5, h = u * 2.95, $fn = 16); // arms
        }
    }
}

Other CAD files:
cad/main.scad
cad/config/build_variant.scad
cad/config/dimensions.scad
cad/config/materials.scad
cad/config/profiles.scad
cad/provisions.scad
cad/purchased_components/door.scad
cad/purchased_components/windows.scad
cad/truck_reference.scad
cad/utility_rails/utility_rails.scad

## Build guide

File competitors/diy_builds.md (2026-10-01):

# DIY builds

Owner-built aluminum campers mostly converge on these techniques:

- **Welded aluminum frames** need the right process, filler, and inert shielding gas. This is consistent
  with ADR 0001; several builders report that welding is the hardest skill to acquire.
- **Skin attachment:** builders have used 3M VHB tape as a structural bond between skin and frame, or
  polyurethane adhesive (Sikaflex 252) with 1/16 in nylon spacers to hold a controlled bondline. Others
  rivet skin to the frame with insulation in the wall cavity.
- Builders consistently underestimate time on sealing, doors, and windows.

Sources (accessed 2026-10-01):
- Expedition Portal, "Questions concerning building a truck camper": https://forum.expeditionportal.com/goto/post?id=1230175
- Expedition Portal, "Roninjiro aluminum Nissan D40 camper": https://forum.expeditionportal.com/goto/post?id=1331245
- Expedition Portal, "Camper construction?": https://forum.expeditionportal.com/goto/post?id=1606591

## Lessons for MINUTEMAN
- **Controlled bondline thickness** (spacers) is how DIY builders get repeatable adhesive joints. Add it
  to the v0.2 adhesive test plan.
- VHB vs. polyurethane vs. structural acrylic (e.g., methacrylate) is an open decision. It belongs in
  `engineering/structural_questions.md` and needs coupon testing, not forum consensus.

## Open
- Collect 3-5 documented builds with weights and costs (forum posts rarely publish both). The
  Expedition Portal links above are discussion threads, not verified data.

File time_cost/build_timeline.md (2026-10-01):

# Build timeline (planning, not a commitment)

| Step | Depends on | Hours (labor_estimate.csv) |
|---|---|---|
| 1. Measure truck, update config, approve v0.1 | none | 2-4 |
| 2. v0.2 frame design + calcs + approval | 1 | design time |
| 3. Welding practice and coupon tests; adhesive coupons | none (can start now) | 15-40 |
| 4. Buy tooling and first materials | 2 | |
| 5. Floor + tub | 3, 4 | 25-45 |
| 6. Walls, roof, nose frames | 5 | 40-70 |
| 7. Skin | 6 + adhesive tests passed | 30-55 |
| 8. Insulation + interior panel | 7 | 20-35 |
| 9. Door, windows, sealing | 7 | 10-20 |
| 10. Rails, roof bosses, jack + tie-down structures | 6 | 15-30 |
| 11. Water test and rework | 9 | 6-15 |

Total ~163-314 hours of owner labor. At 10 hours a week that is roughly 4-8 months.
Welding practice (step 3) is the long pole for a novice and can start before v0.2 is approved.

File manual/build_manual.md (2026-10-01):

# Build manual (skeleton)

**Status: not started. The manual is written in v0.3 from the completed CAD**, generated by
`scripts_code/generate_manual.py` (planned) with step images from `render_steps.py` (planned).

## Step format (LEGO Technic / IKEA style, not a textbook)
Every step has:
1. Step number
2. Parts required (part IDs from the BOM)
3. Hardware required
4. Tools required
5. One large isometric image with **new components highlighted**
6. Part IDs called out on the image
7. Orientation arrows
8. Important dimensions
9. A detail view if needed
10. An **inspection check** before continuing

**Never hide five fabrication operations inside one instruction.**

## Planned sections
- Safety (aluminum welding fumes, argon, cutting, lifting the shell)
- Welding practice and coupon tests (before any structural weld)
- Floor and tub
- Wall, roof, nose frames
- Jack and tie-down structures
- Skin bonding and riveting
- Insulation and interior panel
- Door, windows, sealing
- Rails and provisions
- Water test, weigh-in, first load on the truck

## Planned test plans (`manual/testing/`)
T-slot joint slip; T-slot joint rotation; frame racking; frame-plus-skin racking; adhesive bonding
(lap shear, peel, thermal cycle); riveted skin; representative corner waterproofing; roof/wall joint
waterproofing; jack attachment structure.

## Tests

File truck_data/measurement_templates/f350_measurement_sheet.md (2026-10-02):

<!-- GENERATED by scripts_code/generate_dimension_docs.py from cad/config/dimensions.json - DO NOT HAND-EDIT -->
# F-350 measurement sheet

**This is the next physical action.** Nothing past the envelope can be trusted until these numbers come from the actual truck. Print `f350_measurement_sheet.pdf` (diagrams M1-M5 on page 1), take it to the truck, fill it in, then update `cad/config/dimensions.json` and run `make all`.

**Setup:** level ground; truck loaded as it normally travels (fuel full, usual tools); tires at normal pressure; tailgate open or removed. **Tools:** 25 ft tape, 4-6 ft straightedge or level, plumb bob or string with a nut, masking tape and marker, a helper. Measure twice; where left and right can differ, record both.

| # | Fig | Measurement | How | Model now | Left / A | Right / B |
|---|---|---|---|---|---|---|
| 1 | M1 | Ground to bed floor | Truck loaded as it will travel (fuel full, normal tire pressure), level ground. Tape from ground to top of bed floor at the tailgate, both sides; record average. | 39.5 | ______ | ______ |
| 2 | M2 | Bed floor to top of bed rail (bed depth) | Straightedge across the rails; measure down to bed floor at front, middle, rear. Note rail caps if fitted. | 20 | ______ | ______ |
| 3 | M2 | Wheel well height above bed floor | Bed floor to the highest point of the wheel-well hump. | 10.5 | ______ | ______ |
| 4 | M2 | Wheel well length along bed | Front to rear edge of the wheel-well hump at floor level. | 34 | ______ | ______ |
| 5 | M2 | Bed length at floor | Bed floor, inside front wall to tailgate inner face (tailgate closed). | 98 (8 ft) / 81.8 (6.75) | ______ | ______ |
| 6 | M2 | Rear axle centerline aft of bed front wall | Drop a plumb line from the hub center; measure along the bed side to the inside of the front wall. | 51.2 (8 ft) / 35 (6.75) | ______ | ______ |
| 7 | M3 | Inside bed width at floor (outside the wheel wells) | Across the bed floor ahead of the wheel wells, side wall to side wall, at floor level. Measure at front and at tailgate. | 66 | ______ | ______ |
| 8 | M3 | Inside bed width at top of rails | Inside face to inside face just below the rail lip, front and rear. | 66 | ______ | ______ |
| 9 | M3 | Bed rail top width (each side) | Inside lip to outside edge of the bed side, across the top of the rail. | 6.5 | ______ | ______ |
| 10 | M3 | Clear width between wheel wells | Between the inner faces of the wheel wells at their widest bulge. | 50.9 | ______ | ______ |
| 11 | M4 | Bed floor to highest point of cab roof | Level across from the cab roof (incl. clearance lights, antenna base, roof marker lamps) down to bed floor. | 41.5 | ______ | ______ |
| 12 | M4 | Gap: bed front wall outer face to cab back | At rail height and at cab roof height; record the smaller. | 4 | ______ | ______ |
| 13 | M4 | Bed front wall thickness at the rail | Top of the front rail, inside lip to outside face. | 1.5 | ______ | ______ |
| 14 | M5 | Tailgate opening width (narrowest point) | Tailgate open or removed. Narrowest clear width between the bed-side posts, including latch strikers. | 61 | ______ | ______ |
| 15 | M5 | Tailgate length, hinge to top edge (projects rearward when down) | Tailgate down: hinge line to the far edge, along the tailgate. | 20 | ______ | ______ |
| 16 | M5 | Lowered tailgate top surface above bed floor | Tailgate down: straightedge on bed floor extended over the tailgate; measure the gap or step at the tailgate (+ if the tailgate is higher). | 0.5 | ______ | ______ |

## Also record

| Item | Where to find it | Value |
|---|---|---|
| Which bed is on the truck? | 6.75 ft or 8 ft; cab style (crew / super cab / regular); SRW or DRW. | ______ |
| Model year and trim | Door-jamb sticker. | ______ |
| Payload capacity (lb) | Door-jamb tire & loading sticker: "combined weight of occupants and cargo should never exceed". | ______ |
| GVWR / rear GAWR (lb) | Door-jamb certification label. | ______ |
| Tire load index / size | Tire sidewall. | ______ |
| Cab-roof items | Clearance/marker lamps, antenna, roof rack? Note heights (affects M4). | ______ |
| Bed liner / rail caps / tonneau rails | Type and thickness: they change bed widths and rail height. | ______ |
| Gooseneck / 5th-wheel puck or hitch in bed floor | Location from front wall; anything that protrudes above the floor. | ______ |
| Stake pockets and factory tie-down points | Positions along the bed (for v0.2 tie-downs). | ______ |
| Bed-mounted brake light / camera | Location; the camper will block it. | ______ |

Date measured: ________  Measured by: ________

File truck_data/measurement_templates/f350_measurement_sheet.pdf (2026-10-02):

# MINUTEMAN - F-350 measurement sheet: diagrams

Schematic, not to scale. Level ground, normal travel load, tailgate open. Numbers in brackets = row # on page 2.

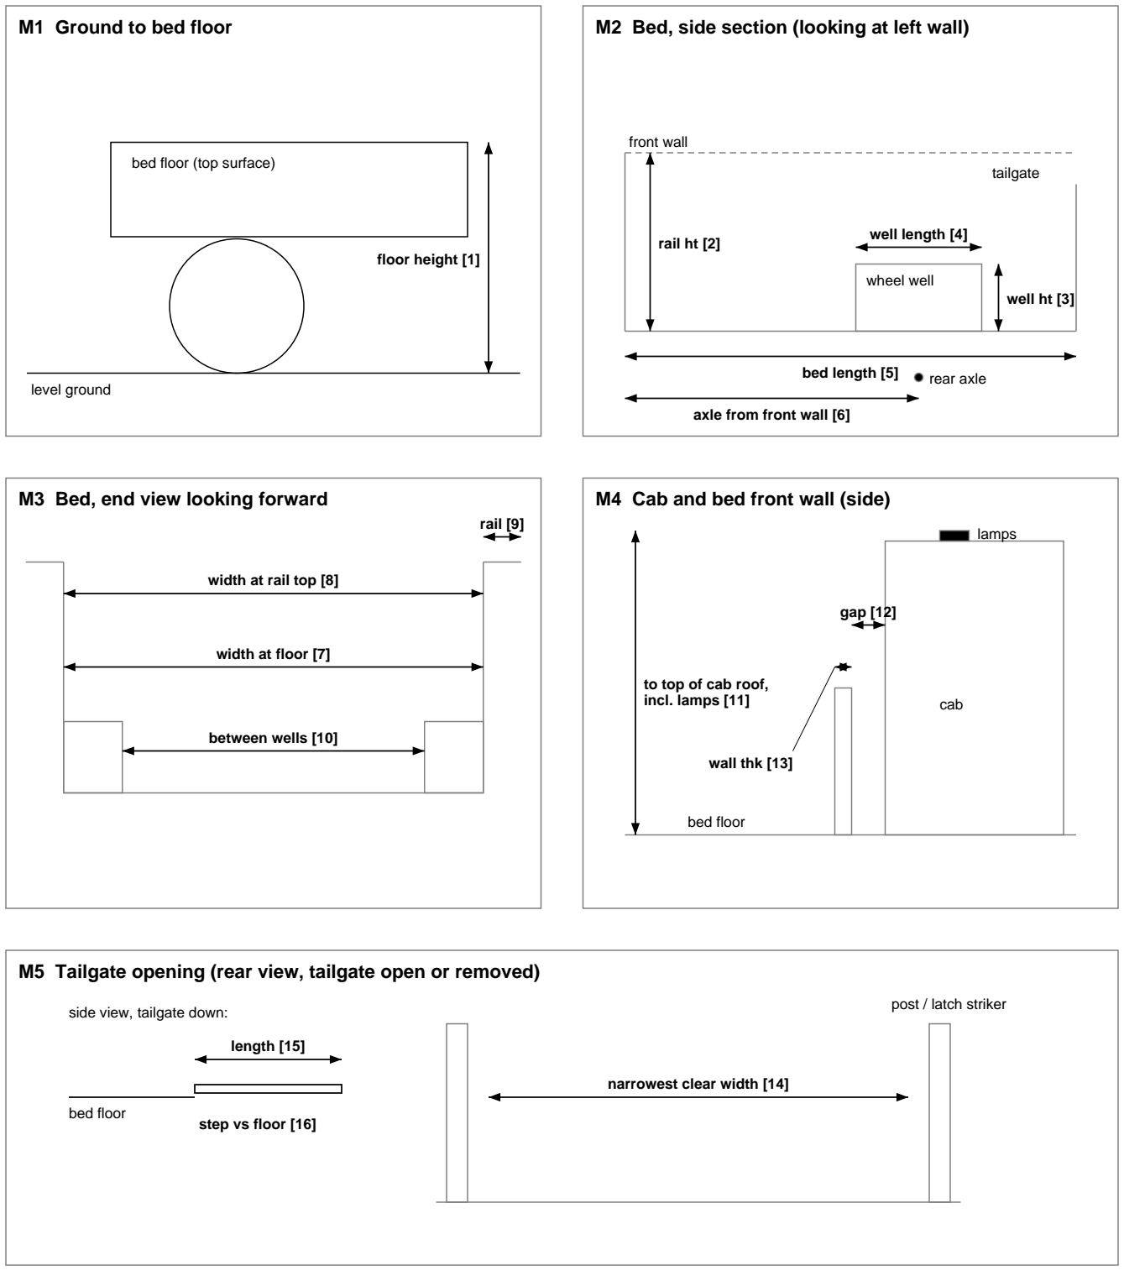
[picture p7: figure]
M1 Ground to bed floor; bed floor (top surface); level ground; floor height [1]; front wall; tailgate; wheel well; rear axle bed length [5]; axle from front wall [6]; well length [4]; well ht [3]; rail ht [2]; M3 Bed, end view looking forward; width at rail top [8]; width at floor [7]; between wells [10]; rail [9]; M4 Cab and bed front wall (side); cab; lamps; bed floor; to top of cab roof, incl. lamps [11]; gap [12]; wall thk [13]; post / latch striker; narrowest clear width [14]; side view, tailgate down:; length [15]; step vs floor [16]

M2 Bed, side section (looking at left wall)

M5 Tailgate opening (rear view, tailgate open or removed)

# F-350 measurements - record left/right (or front/rear) where they can differ

# | Fig | Measurement | Model value now | A / Left | B / Right

1 | M1 | Ground to bed floor | 39.5
2 | M2 | Bed floor to top of bed rail (bed depth) | 20
3 | M2 | Wheel well height above bed floor | 10.5
4 | M2 | Wheel well length along bed | 34
5 | M2 | Bed length at floor | 98 (8 ft) / 81.8 (6.75)
6 | M2 | Rear axle centerline aft of bed front wall | 51.2 (8 ft) / 35 (6.75)
7 | M3 | Inside bed width at floor (outside the wheel wells) | 66
8 | M3 | Inside bed width at top of rails | 66
9 | M3 | Bed rail top width (each side) | 6.5
10 | M3 | Clear width between wheel wells | 50.9
11 | M4 | Bed floor to highest point of cab roof | 41.5
12 | M4 | Gap: bed front wall outer face to cab back | 4
13 | M4 | Bed front wall thickness at the rail | 1.5
14 | M5 | Tailgate opening width (narrowest point) | 61
15 | M5 | Tailgate length, hinge to top edge (projects rearward when | 20
16 | M5 | Lowered tailgate top surface above bed floor | 0.5

Also record

Which bed is on the truck?
6.75 ft or 8 ft; cab style (crew / super cab / regular); SRW or DRW. Model year and trim
Door-jamb sticker.
Payload capacity (lb)
Door-jamb tire & loading sticker: "combined weight of occupants and cargo should never exceed". GVWR / rear GAWR (lb)
Door-jamb certification label.
Tire load index / size
Tire sidewall.
Cab-roof items
Clearance/marker lamps, antenna, roof rack? Note heights (affects M4). Bed liner / rail caps / tonneau rails
Type and thickness: they change bed widths and rail height.
Gooseneck / 5th-wheel puck or hitch in bed floor
Location from front wall; anything that protrudes above the floor. Stake pockets and factory tie-down points
Positions along the bed (for v0.2 tie-downs).
Bed-mounted brake light / camera
Location; the camper will block it.

Date measured: ________________ Measured by: ________________

How to measure each row: see f350_measurement_sheet.md. After measuring: update cad/config/dimensions.json, run `make all`.

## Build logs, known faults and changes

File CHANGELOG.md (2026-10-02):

# Changelog

All notable changes to MINUTEMAN. Versions follow the ladder in `PROJECT_HANDOFF.md` §11:
v0.1 envelope → v0.2 structural frame candidate → v0.3 complete shell CAD → v0.4 prototype →
v0.5 build changes → v1.0 completed and validated physical shell.

## [Unreleased] — v0.1 envelope, rev B (2026-10-01)

### Changed (ADR 0004)
- Lower length 78 → **97 in**: fills the 2011 F-350 8 ft bed with the tailgate closed. Overall 121 in.
- Truck data re-based on the **2011 F-350** (Ford 2011 RV & Trailer Towing Guide + spec summaries): bed floor
  39.5 in, box depth 20.0, wells 50.9, tailgate ~61, wheelbases 156.2/172.4, camper cargo ratings.
- Lower tub width 63 → **59.5 in** (61 in tailgate). Camper geometry now derives only from the DESIGN_TRUCK.
- Weight 985-1,231 lb, cost $4,402-8,735 (both excl. jacks); reports now state the target miss computed, not hard-coded.

### Added
- Truck variants: F-350 8 ft / 6.75 ft (tailgate down), F-150 6.5 / 5.5 ft, Tacoma 6 / 5 ft; tailgate model.
- Center-of-gravity estimate from envelope face centroids; multi-truck fit study (`truck_data/fit_study.md`).
- Drawing set re-done to ASME Y14 conventions on ANSI C: MM-A01..A05 (new: A03 interior sections,
  A04 F-350 fit with CG, A05 multi-truck fit). Old A03 truck-fit sheet superseded by A04/A05.
- `reference/drafting_standards.md`, `truck_data/README.md` (sources), measurement sheet rows 15-16 (tailgate).

## v0.1 envelope, rev A

### Added
- Repository scaffold, `CLAUDE.md`, `Makefile`, `.gitignore`.
- ADRs 0001 (welding), 0002 (80 in interior / low-drag), 0003 (solar/battery provisions).
- `cad/config/dimensions.json` master config -> generated `dimensions.scad`; build variants SHORT/LONG.
- Envelope model: stepped lower tub (49.1/63 in), 80 in body, raked 24 in nose, 0.75 in roof crown;
  F-350 reference; door, window, T-slot rail, roof-boss placeholders; reserved power zone and wire chase;
  6'7" figure.
- `echo()` parts registry -> `parts.json` -> BOM, cut lists, weight and cost reports with height sensitivity.
- 12 renderings; drawings A01 general arrangement, A02 major dimensions, A03 truck fit.
- `validate_model.py` (57 checks: IDs, welded min wall, statuses, truck-fit geometry).
- DIMENSIONS.md and printable F-350 measurement sheet (generated).
- Product vision, engineering assumptions/load paths/questions, competitors (sourced), time/cost,
  business outlook, manual skeleton.

### Changed vs. handoff first pass
- Lower tub width 63 in (not ~68 in): it must pass a ~65 in tailgate opening.
- 6061 tube priced at realistic retail $/lb; shell cost range rises to $3,877-7,950.

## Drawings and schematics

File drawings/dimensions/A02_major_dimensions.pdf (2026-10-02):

8

7

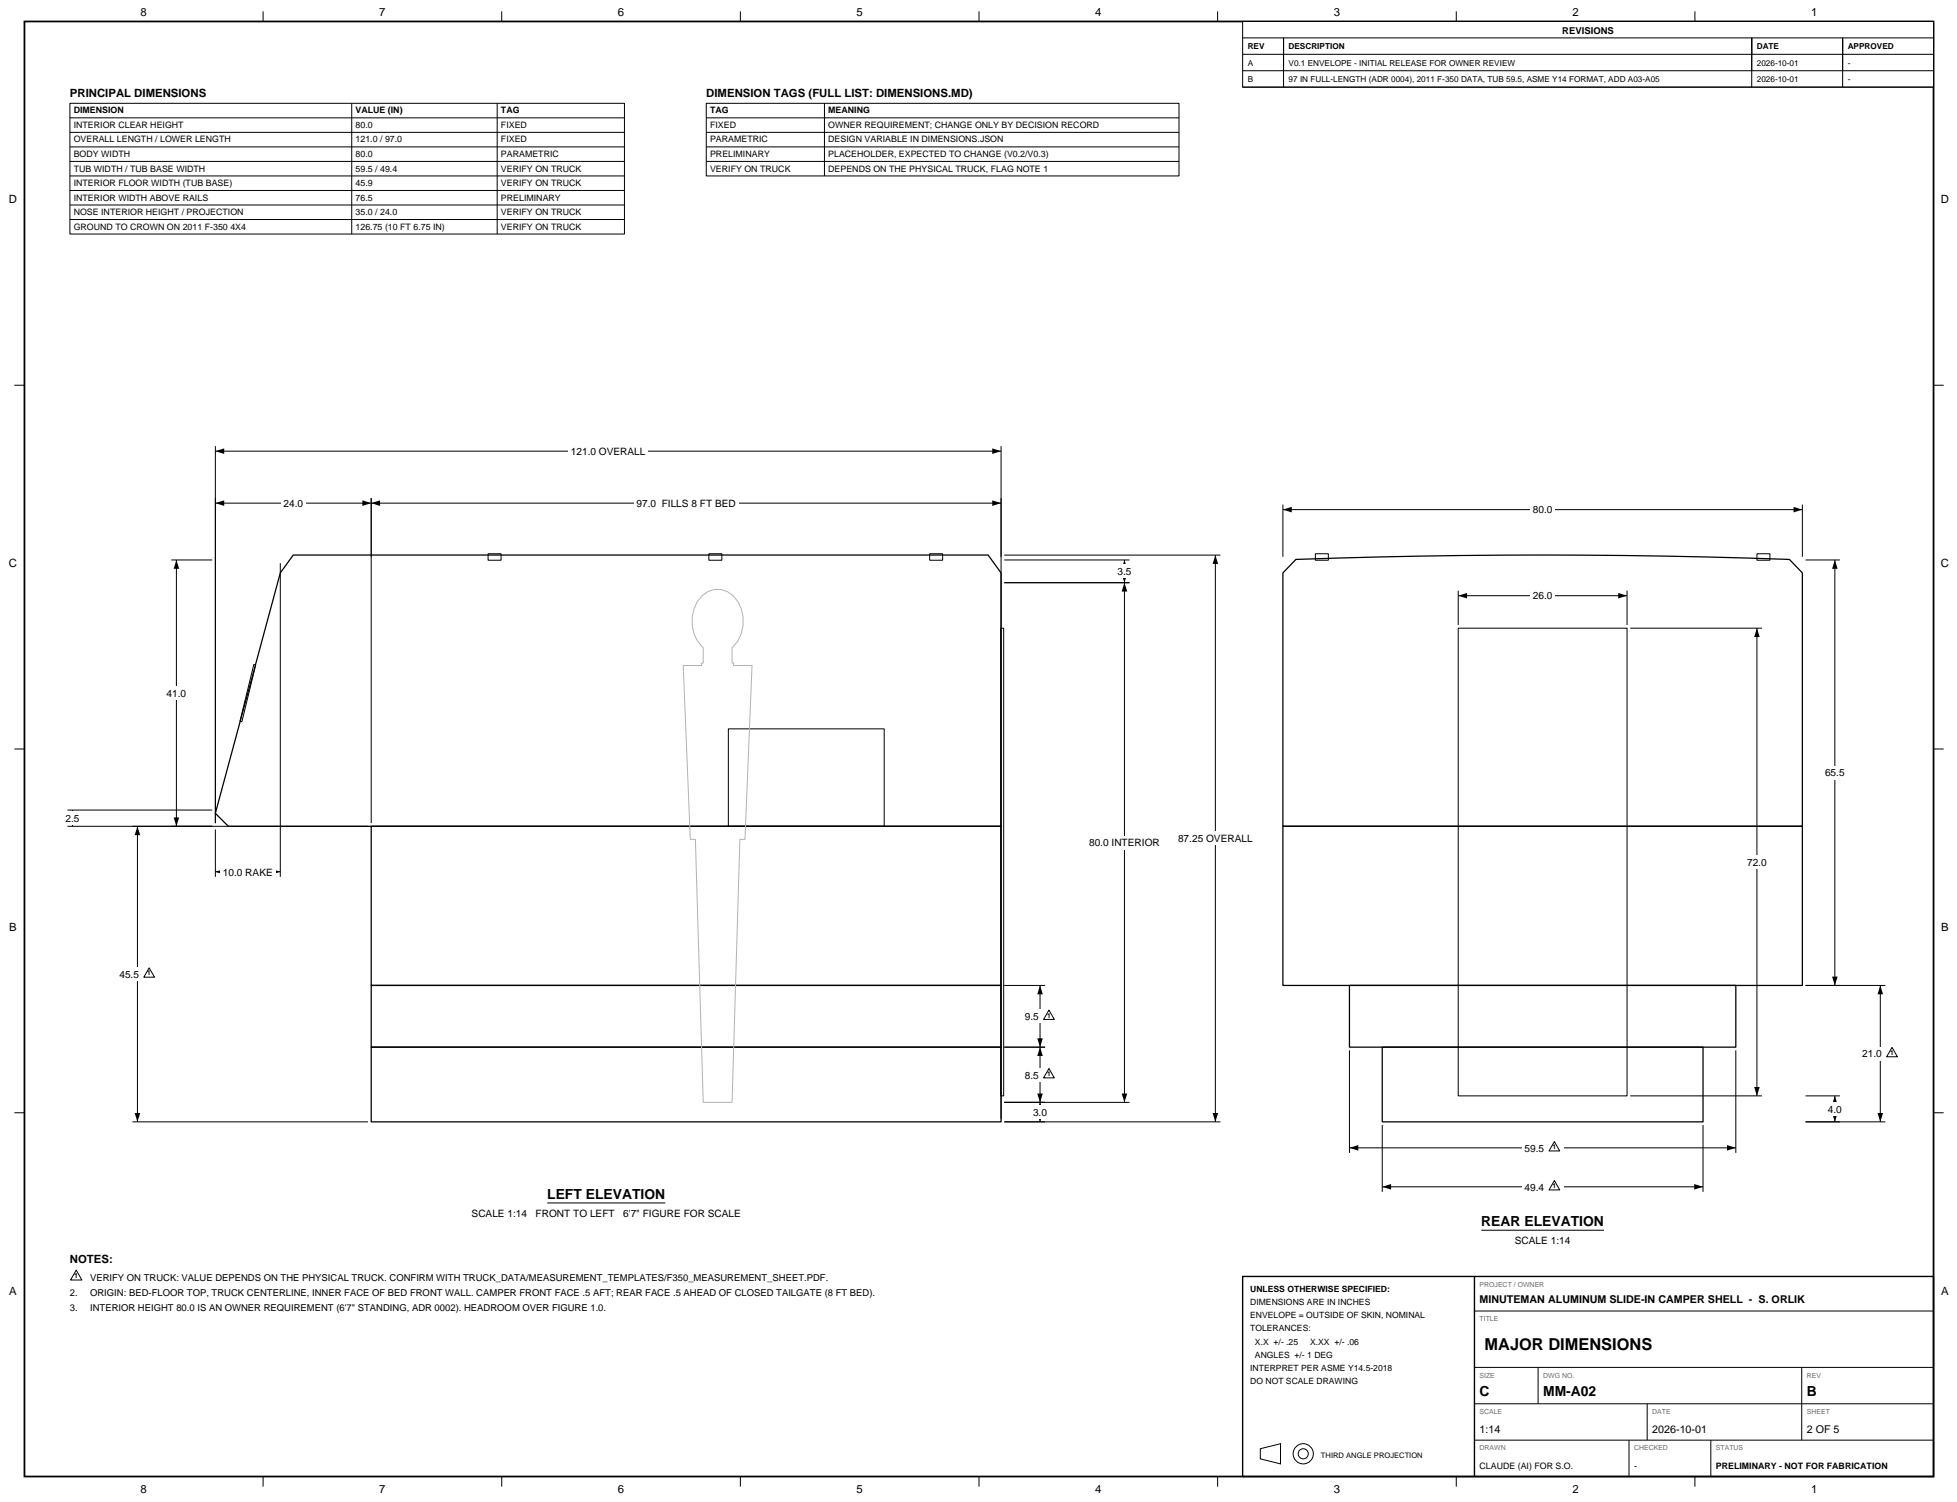
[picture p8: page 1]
TITLE MAJOR DIMENSIONS; SIZE C; DWG NO. MM-A02; REV B; SCALE 1:14; DATE 2026-10-01; SHEET; CHECKED; REVISIONS; REV; DESCRIPTION; DATE; APPROVED; V0.1 ENVELOPE - INITIAL RELEASE FOR OWNER REVIEW; 97 IN FULL-LENGTH (ADR 0004), 2011 F-350 DATA, TUB 59.5, ASME Y14 FORMAT, ADD A03-A05; LEFT ELEVATION; 121.0 OVERALL; 97.0 FILLS 8 FT BED; 10.0 RAKE; 80.0 INTERIOR; 87.25 OVERALL; REAR ELEVATION; PRINCIPAL DIMENSIONS; DIMENSION; VALUE (IN); TAG; INTERIOR CLEAR HEIGHT; FIXED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

DIMENSION TAGS (FULL LIST: DIMENSIONS.MD)

SCALE 1:14 FRONT TO LEFT 6'7" FIGURE FOR SCALE

NOTES:
1 VERIFY ON TRUCK: VALUE DEPENDS ON THE PHYSICAL TRUCK. CONFIRM WITH TRUCK_DATA/MEASUREMENT_TEMPLATES/F350_MEASUREMENT_SHEET.PDF.
2. ORIGIN: BED-FLOOR TOP, TRUCK CENTERLINE, INNER FACE OF BED FRONT WALL. CAMPER FRONT FACE .5 AFT; REAR FACE .5 AHEAD OF CLOSED TAILGATE (8 FT BED).
3. INTERIOR HEIGHT 80.0 IS AN OWNER REQUIREMENT (6'7" STANDING, ADR 0002). HEADROOM OVER FIGURE 1.0.

UNLESS OTHERWISE SPECIFIED:
DIMENSIONS ARE IN INCHES
ENVELOPE = OUTSIDE OF SKIN, NOMINAL
TOLERANCES:
ANGLES +/- 1 DEG
INTERPRET PER ASME Y14.5-2018
DO NOT SCALE DRAWING

PROJECT / OWNER
MINUTEMAN ALUMINUM SLIDE-IN CAMPER SHELL - S. ORLIK

DRAWN
CLAUDE (AI) FOR S.O.

STATUS
PRELIMINARY - NOT FOR FABRICATION

THIRD ANGLE PROJECTION

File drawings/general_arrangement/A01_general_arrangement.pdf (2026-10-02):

C C

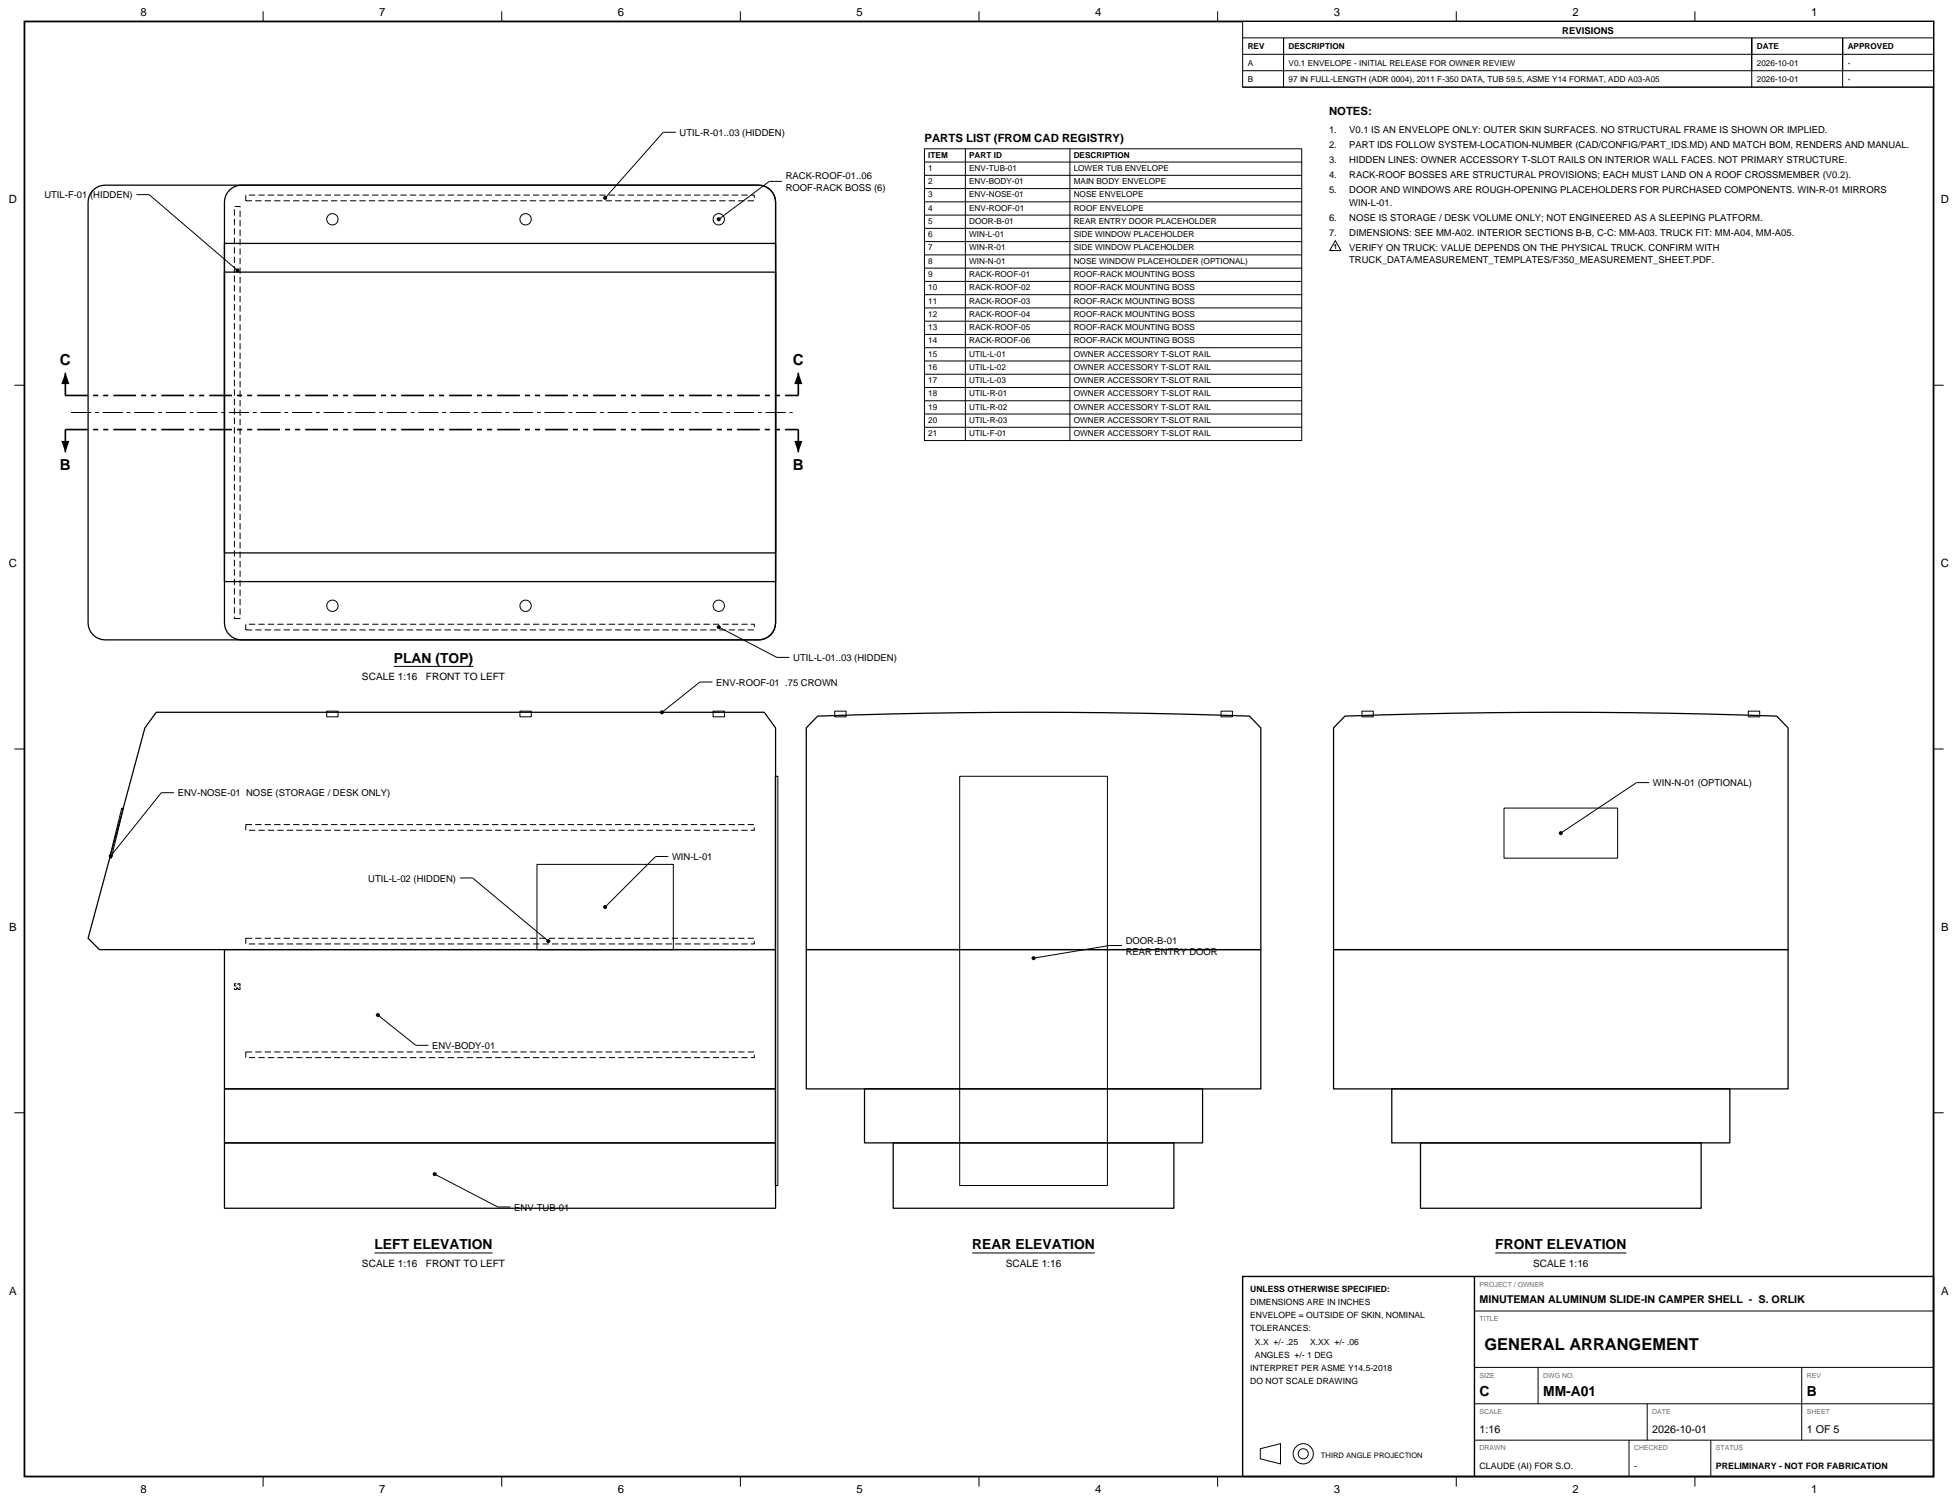
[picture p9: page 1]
TITLE GENERAL ARRANGEMENT; SIZE C; DWG NO. MM-A01; REV B; SCALE 1:16; DATE 2026-10-01; SHEET; CHECKED; REVISIONS; REV; DESCRIPTION; DATE; APPROVED; V0.1 ENVELOPE - INITIAL RELEASE FOR OWNER REVIEW; 97 IN FULL-LENGTH (ADR 0004), 2011 F-350 DATA, TUB 59.5, ASME Y14 FORMAT, ADD A03-A05; UTIL-L-01..03 (HIDDEN); UTIL-R-01..03 (HIDDEN); UTIL-F-01 (HIDDEN); ENV-BODY-01; ENV-TUB-01; WIN-L-01; UTIL-L-02 (HIDDEN); REAR ELEVATION; FRONT ELEVATION; WIN-N-01 (OPTIONAL); ITEM; PART ID; LOWER TUB ENVELOPE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

NOTES:
1. V0.1 IS AN ENVELOPE ONLY: OUTER SKIN SURFACES. NO STRUCTURAL FRAME IS SHOWN OR IMPLIED.
2. PART IDS FOLLOW SYSTEM-LOCATION-NUMBER (CAD/CONFIG/PART_IDS.MD) AND MATCH BOM, RENDERS AND MANUAL.
3. HIDDEN LINES: OWNER ACCESSORY T-SLOT RAILS ON INTERIOR WALL FACES. NOT PRIMARY STRUCTURE.
4. RACK-ROOF BOSSES ARE STRUCTURAL PROVISIONS; EACH MUST LAND ON A ROOF CROSSMEMBER (V0.2).
5. DOOR AND WINDOWS ARE ROUGH-OPENING PLACEHOLDERS FOR PURCHASED COMPONENTS. WIN-R-01 MIRRORS
WIN-L-01.
6. NOSE IS STORAGE / DESK VOLUME ONLY; NOT ENGINEERED AS A SLEEPING PLATFORM.
7. DIMENSIONS: SEE MM-A02. INTERIOR SECTIONS B-B, C-C: MM-A03. TRUCK FIT: MM-A04, MM-A05.
1 VERIFY ON TRUCK: VALUE DEPENDS ON THE PHYSICAL TRUCK. CONFIRM WITH
TRUCK_DATA/MEASUREMENT_TEMPLATES/F350_MEASUREMENT_SHEET.PDF.

PARTS LIST (FROM CAD REGISTRY)

RACK-ROOF-01..06
ROOF-RACK BOSS (6)

PLAN (TOP)
SCALE 1:16 FRONT TO LEFT

ENV-ROOF-01 .75 CROWN

ENV-NOSE-01 NOSE (STORAGE / DESK ONLY)

DOOR-B-01
REAR ENTRY DOOR

LEFT ELEVATION

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

PROJECT / OWNER
MINUTEMAN ALUMINUM SLIDE-IN CAMPER SHELL - S. ORLIK

DRAWN
CLAUDE (AI) FOR S.O.

STATUS
PRELIMINARY - NOT FOR FABRICATION

THIRD ANGLE PROJECTION

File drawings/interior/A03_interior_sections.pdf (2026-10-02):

8

7

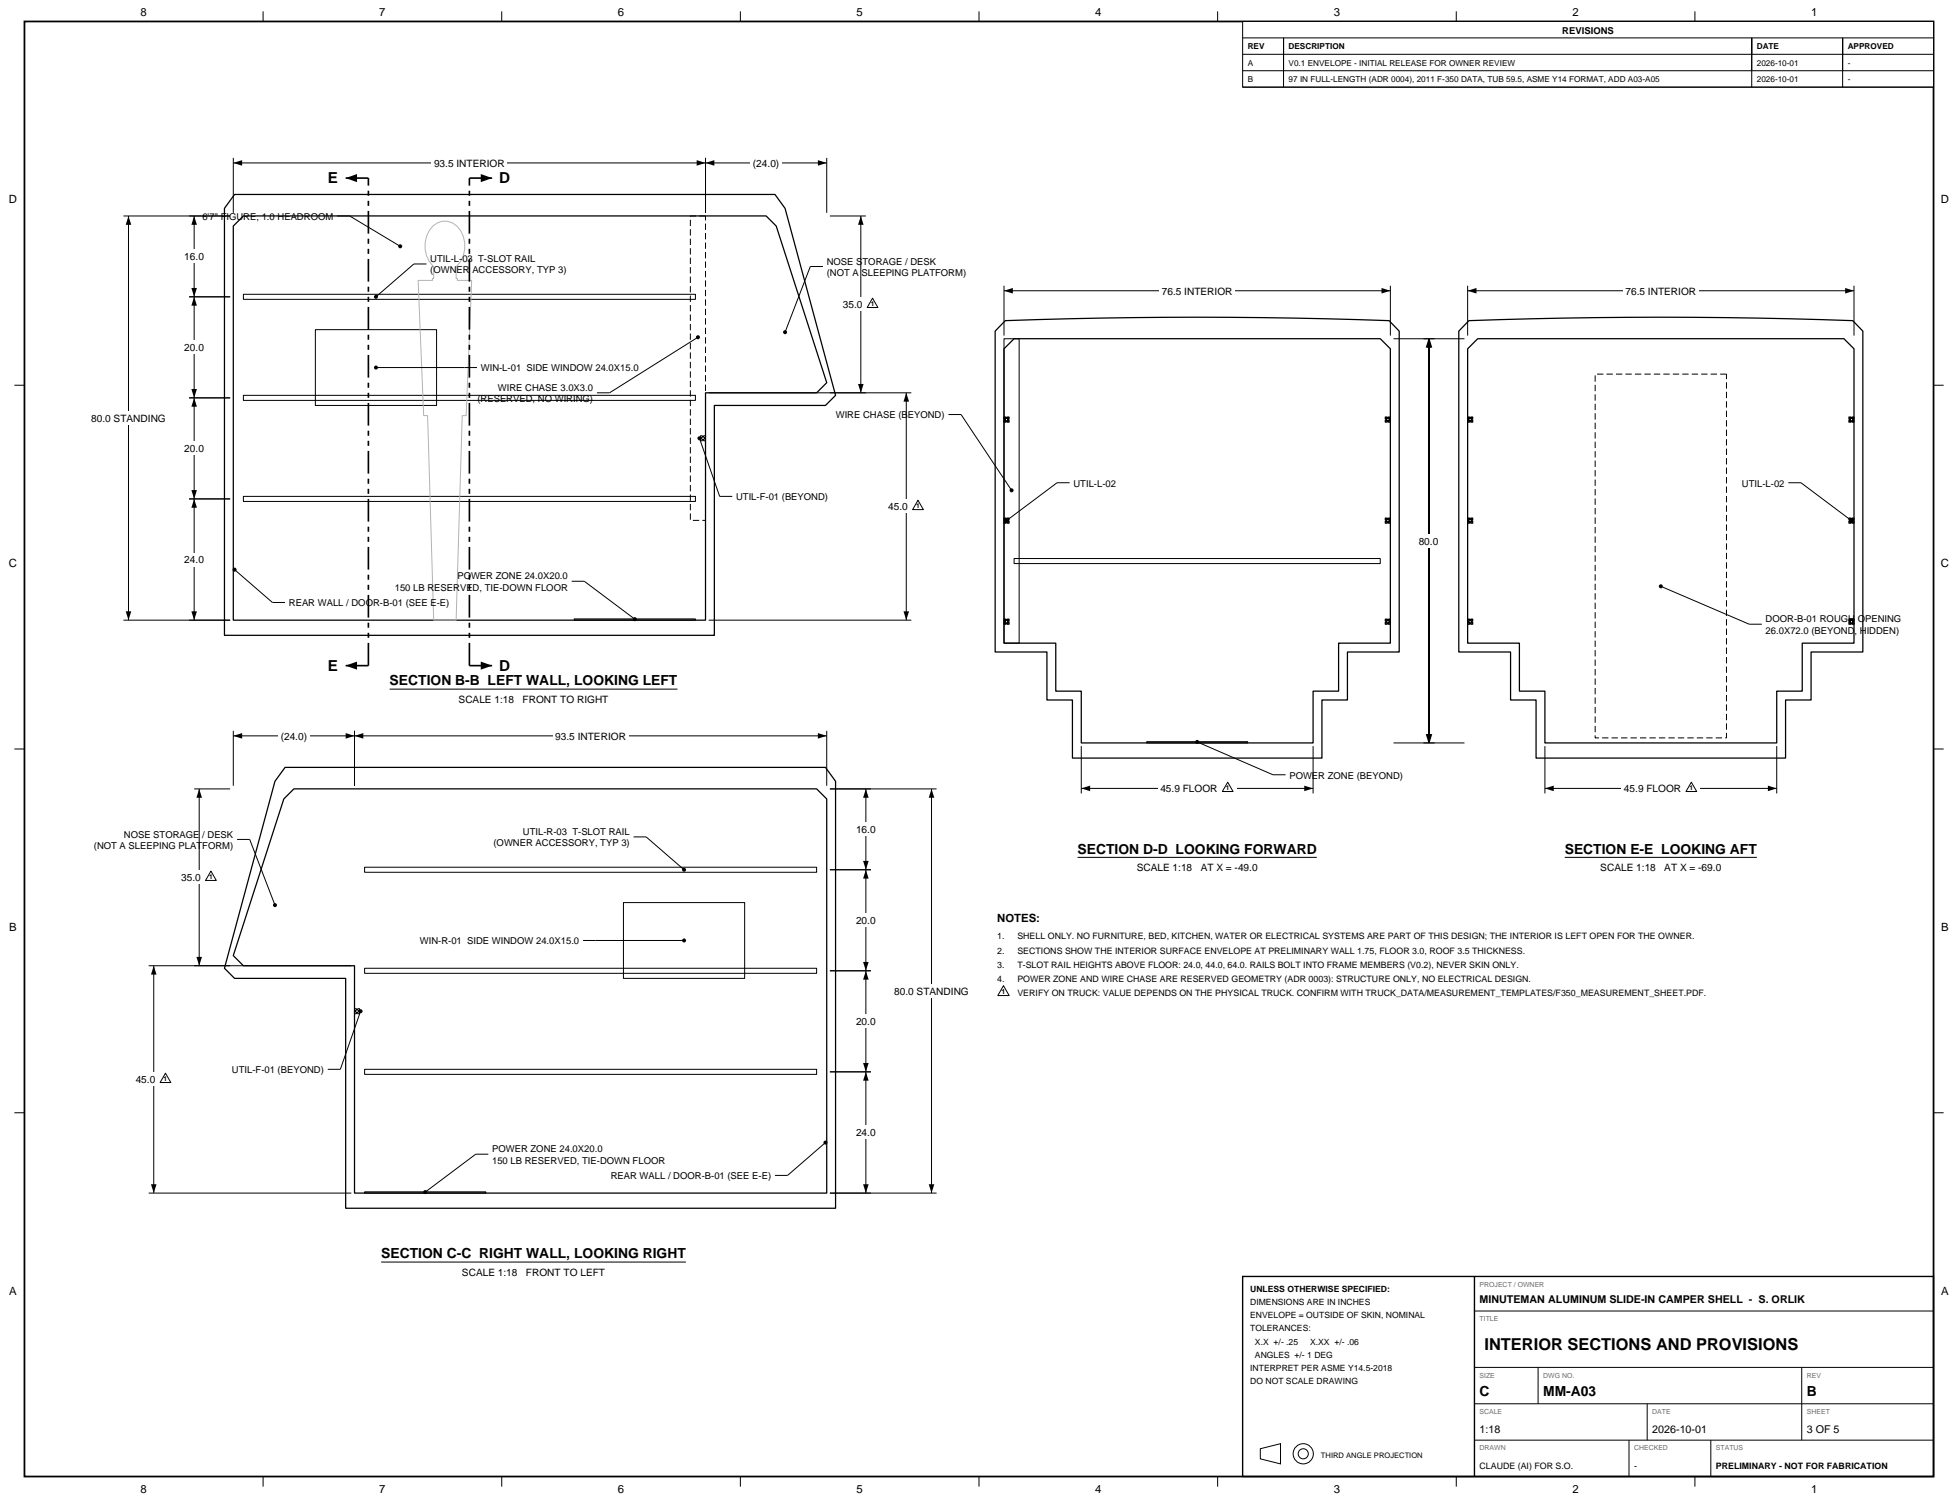
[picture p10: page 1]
SIZE C; DWG NO. MM-A03; REV B; SCALE 1:18; DATE 2026-10-01; SHEET; CHECKED; REVISIONS; REV; DESCRIPTION; DATE; APPROVED; V0.1 ENVELOPE - INITIAL RELEASE FOR OWNER REVIEW; 97 IN FULL-LENGTH (ADR 0004), 2011 F-350 DATA, TUB 59.5, ASME Y14 FORMAT, ADD A03-A05; 80.0 STANDING; 93.5 INTERIOR; POWER ZONE 24.0X20.0; UTIL-F-01 (BEYOND); 6'7" FIGURE, 1.0 HEADROOM; (24.0) 93.5 INTERIOR; SCALE 1:18 AT X = -49.0; 76.5 INTERIOR; 45.9 FLOOR 1; UTIL-L-02; NOTES:

UTIL-L-03 T-SLOT RAIL
(OWNER ACCESSORY, TYP 3)

NOSE STORAGE / DESK
(NOT A SLEEPING PLATFORM)

WIN-L-01 SIDE WINDOW 24.0X15.0
WIRE CHASE 3.0X3.0
(RESERVED, NO WIRING)

WIRE CHASE (BEYOND)

150 LB RESERVED, TIE-DOWN FLOOR

REAR WALL / DOOR-B-01 (SEE E-E)

DOOR-B-01 ROUGH OPENING
26.0X72.0 (BEYOND, HIDDEN)

SECTION B-B LEFT WALL, LOOKING LEFT

SCALE 1:18 FRONT TO RIGHT

POWER ZONE (BEYOND)

UTIL-R-03 T-SLOT RAIL

SECTION D-D LOOKING FORWARD

SECTION E-E LOOKING AFT
SCALE 1:18 AT X = -69.0

WIN-R-01 SIDE WINDOW 24.0X15.0

1. SHELL ONLY. NO FURNITURE, BED, KITCHEN, WATER OR ELECTRICAL SYSTEMS ARE PART OF THIS DESIGN; THE INTERIOR IS LEFT OPEN FOR THE OWNER.
2. SECTIONS SHOW THE INTERIOR SURFACE ENVELOPE AT PRELIMINARY WALL 1.75, FLOOR 3.0, ROOF 3.5 THICKNESS.
3. T-SLOT RAIL HEIGHTS ABOVE FLOOR: 24.0, 44.0, 64.0. RAILS BOLT INTO FRAME MEMBERS (V0.2), NEVER SKIN ONLY.
4. POWER ZONE AND WIRE CHASE ARE RESERVED GEOMETRY (ADR 0003): STRUCTURE ONLY, NO ELECTRICAL DESIGN.
1 VERIFY ON TRUCK: VALUE DEPENDS ON THE PHYSICAL TRUCK. CONFIRM WITH TRUCK_DATA/MEASUREMENT_TEMPLATES/F350_MEASUREMENT_SHEET.PDF.

POWER ZONE 24.0X20.0

SECTION C-C RIGHT WALL, LOOKING RIGHT

SCALE 1:18 FRONT TO LEFT

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

PROJECT / OWNER
MINUTEMAN ALUMINUM SLIDE-IN CAMPER SHELL - S. ORLIK

TITLE
INTERIOR SECTIONS AND PROVISIONS

DRAWN
CLAUDE (AI) FOR S.O.

STATUS
PRELIMINARY - NOT FOR FABRICATION

THIRD ANGLE PROJECTION

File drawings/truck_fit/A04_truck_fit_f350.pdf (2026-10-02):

8

7

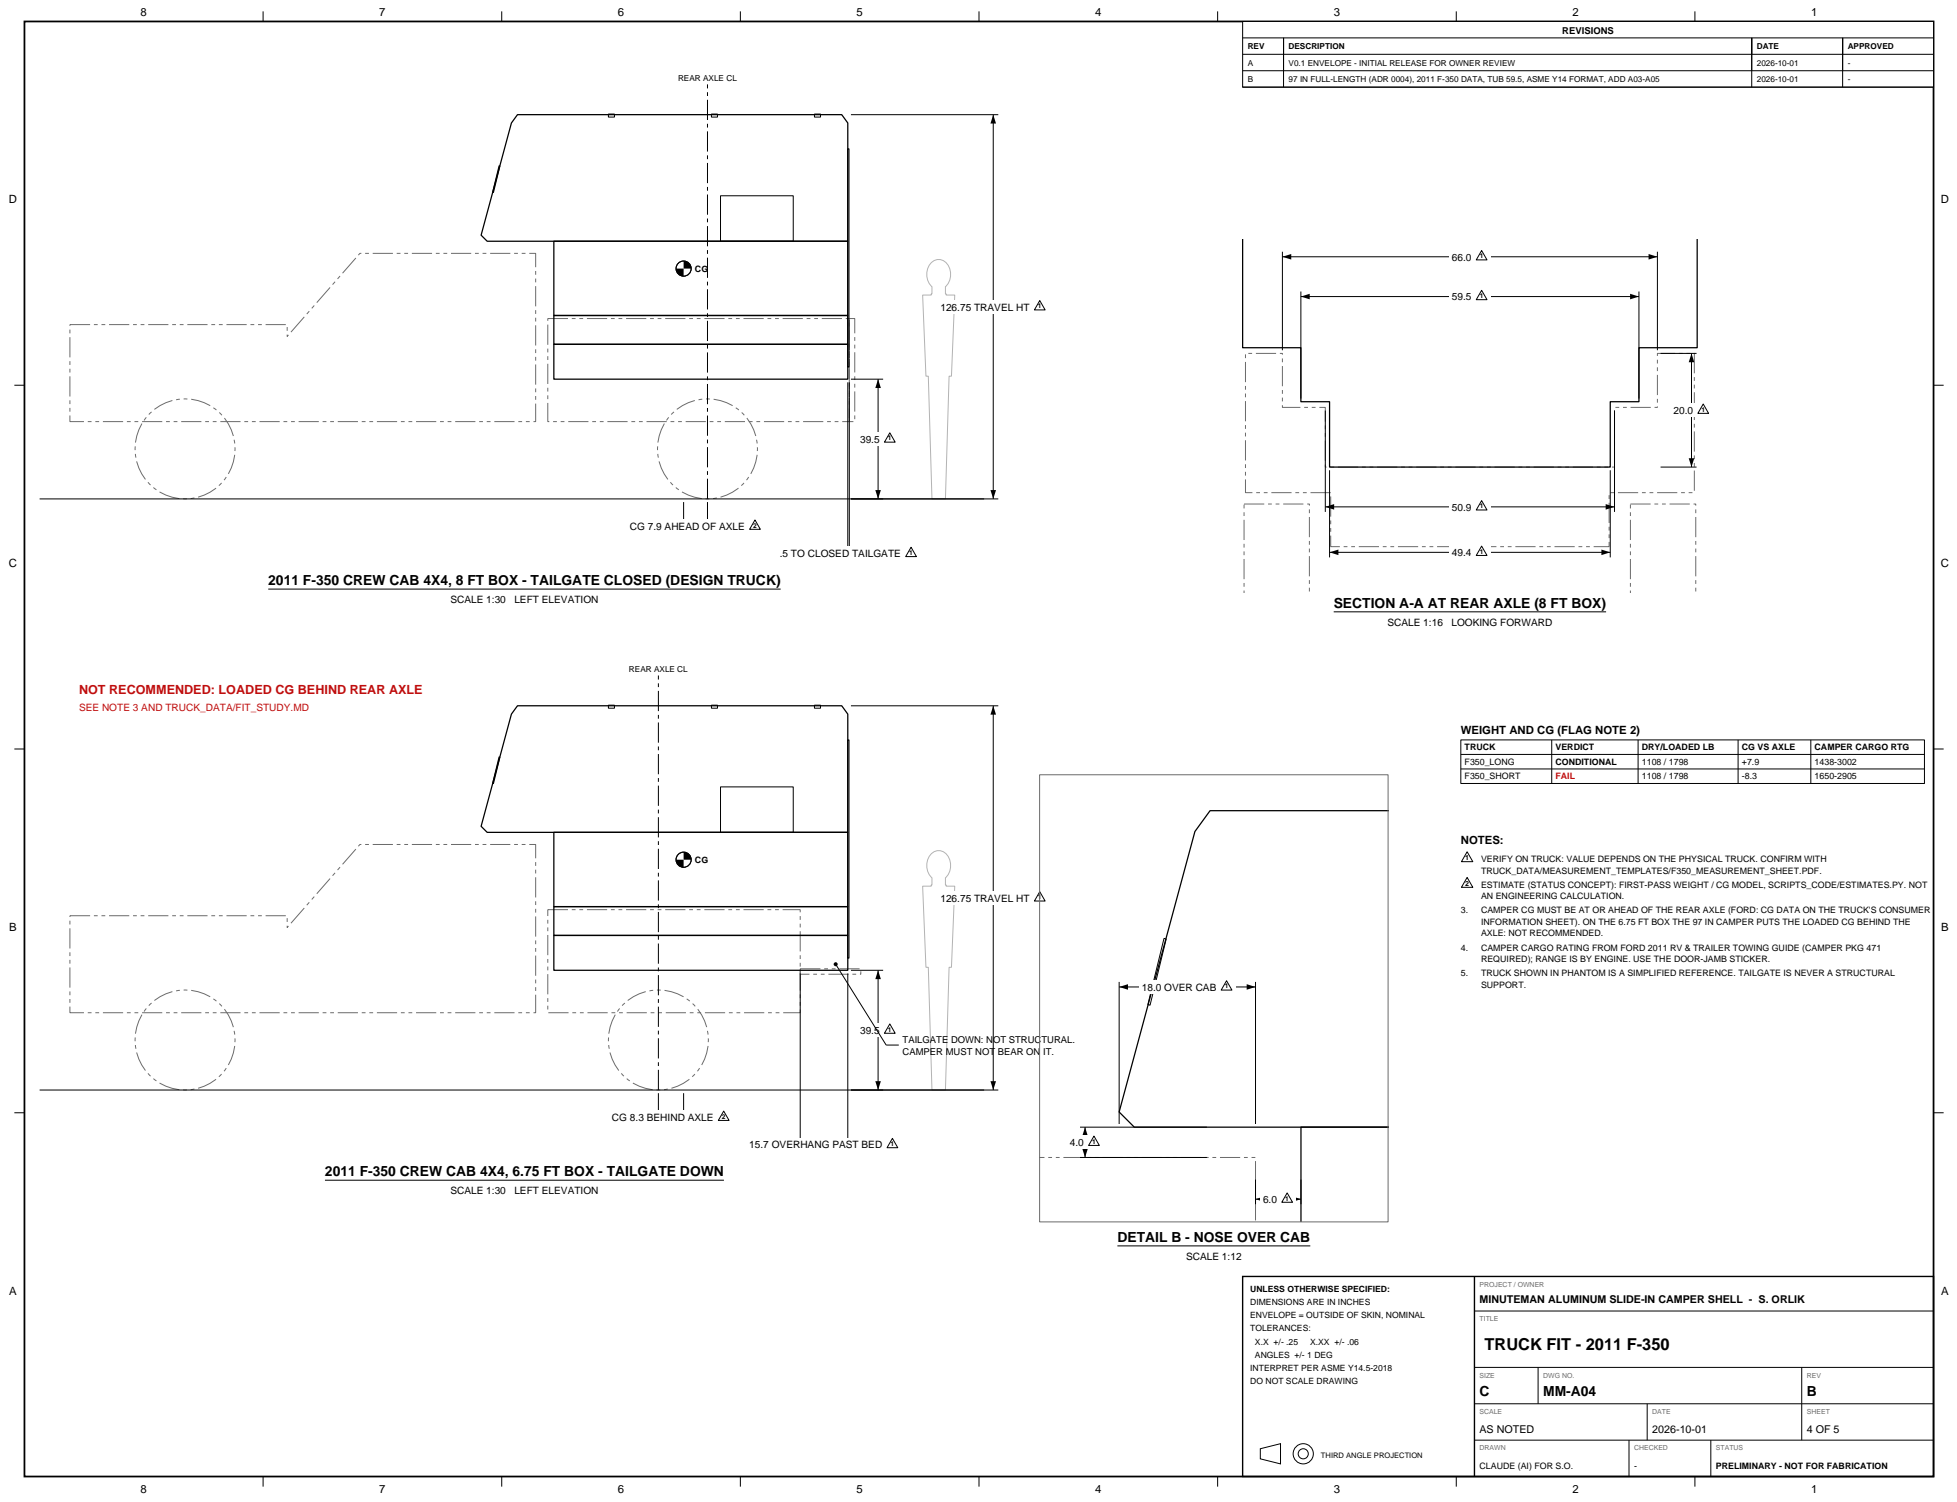
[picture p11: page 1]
TITLE TRUCK FIT - 2011 F-350; SIZE C; DWG NO. MM-A04; REV B; SCALE AS NOTED; DATE 2026-10-01; SHEET; CHECKED; REVISIONS; REV; DESCRIPTION; DATE; APPROVED; V0.1 ENVELOPE - INITIAL RELEASE FOR OWNER REVIEW; REAR AXLE CL; 97 IN FULL-LENGTH (ADR 0004), 2011 F-350 DATA, TUB 59.5, ASME Y14 FORMAT, ADD A03-A05; 126.75 TRAVEL HT 1; SCALE 1:12; 18.0 OVER CAB 1; TRUCK; VERDICT; DRY/LOADED LB; CG VS AXLE; CAMPER CARGO RTG; F350_LONG; CONDITIONAL; F350_SHORT; FAIL; NOTES:

CG 7.9 AHEAD OF AXLE 2

.5 TO CLOSED TAILGATE 1

2011 F-350 CREW CAB 4X4, 8 FT BOX - TAILGATE CLOSED (DESIGN TRUCK)

SCALE 1:30 LEFT ELEVATION

SECTION A-A AT REAR AXLE (8 FT BOX)

SCALE 1:16 LOOKING FORWARD

REAR AXLE CL

NOT RECOMMENDED: LOADED CG BEHIND REAR AXLE
SEE NOTE 3 AND TRUCK_DATA/FIT_STUDY.MD

WEIGHT AND CG (FLAG NOTE 2)

1 VERIFY ON TRUCK: VALUE DEPENDS ON THE PHYSICAL TRUCK. CONFIRM WITH
TRUCK_DATA/MEASUREMENT_TEMPLATES/F350_MEASUREMENT_SHEET.PDF.
2 ESTIMATE (STATUS CONCEPT): FIRST-PASS WEIGHT / CG MODEL, SCRIPTS_CODE/ESTIMATES.PY. NOT
AN ENGINEERING CALCULATION.
3. CAMPER CG MUST BE AT OR AHEAD OF THE REAR AXLE (FORD: CG DATA ON THE TRUCK'S CONSUMER
INFORMATION SHEET). ON THE 6.75 FT BOX THE 97 IN CAMPER PUTS THE LOADED CG BEHIND THE
AXLE: NOT RECOMMENDED.
4. CAMPER CARGO RATING FROM FORD 2011 RV & TRAILER TOWING GUIDE (CAMPER PKG 471
REQUIRED); RANGE IS BY ENGINE. USE THE DOOR-JAMB STICKER.
5. TRUCK SHOWN IN PHANTOM IS A SIMPLIFIED REFERENCE. TAILGATE IS NEVER A STRUCTURAL
SUPPORT.

TAILGATE DOWN: NOT STRUCTURAL.
CAMPER MUST NOT BEAR ON IT.

CG 8.3 BEHIND AXLE 2

15.7 OVERHANG PAST BED 1

2011 F-350 CREW CAB 4X4, 6.75 FT BOX - TAILGATE DOWN

DETAIL B - NOSE OVER CAB

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

PROJECT / OWNER
MINUTEMAN ALUMINUM SLIDE-IN CAMPER SHELL - S. ORLIK

DRAWN
CLAUDE (AI) FOR S.O.

STATUS
PRELIMINARY - NOT FOR FABRICATION

THIRD ANGLE PROJECTION

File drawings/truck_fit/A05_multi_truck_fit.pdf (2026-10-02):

8

7

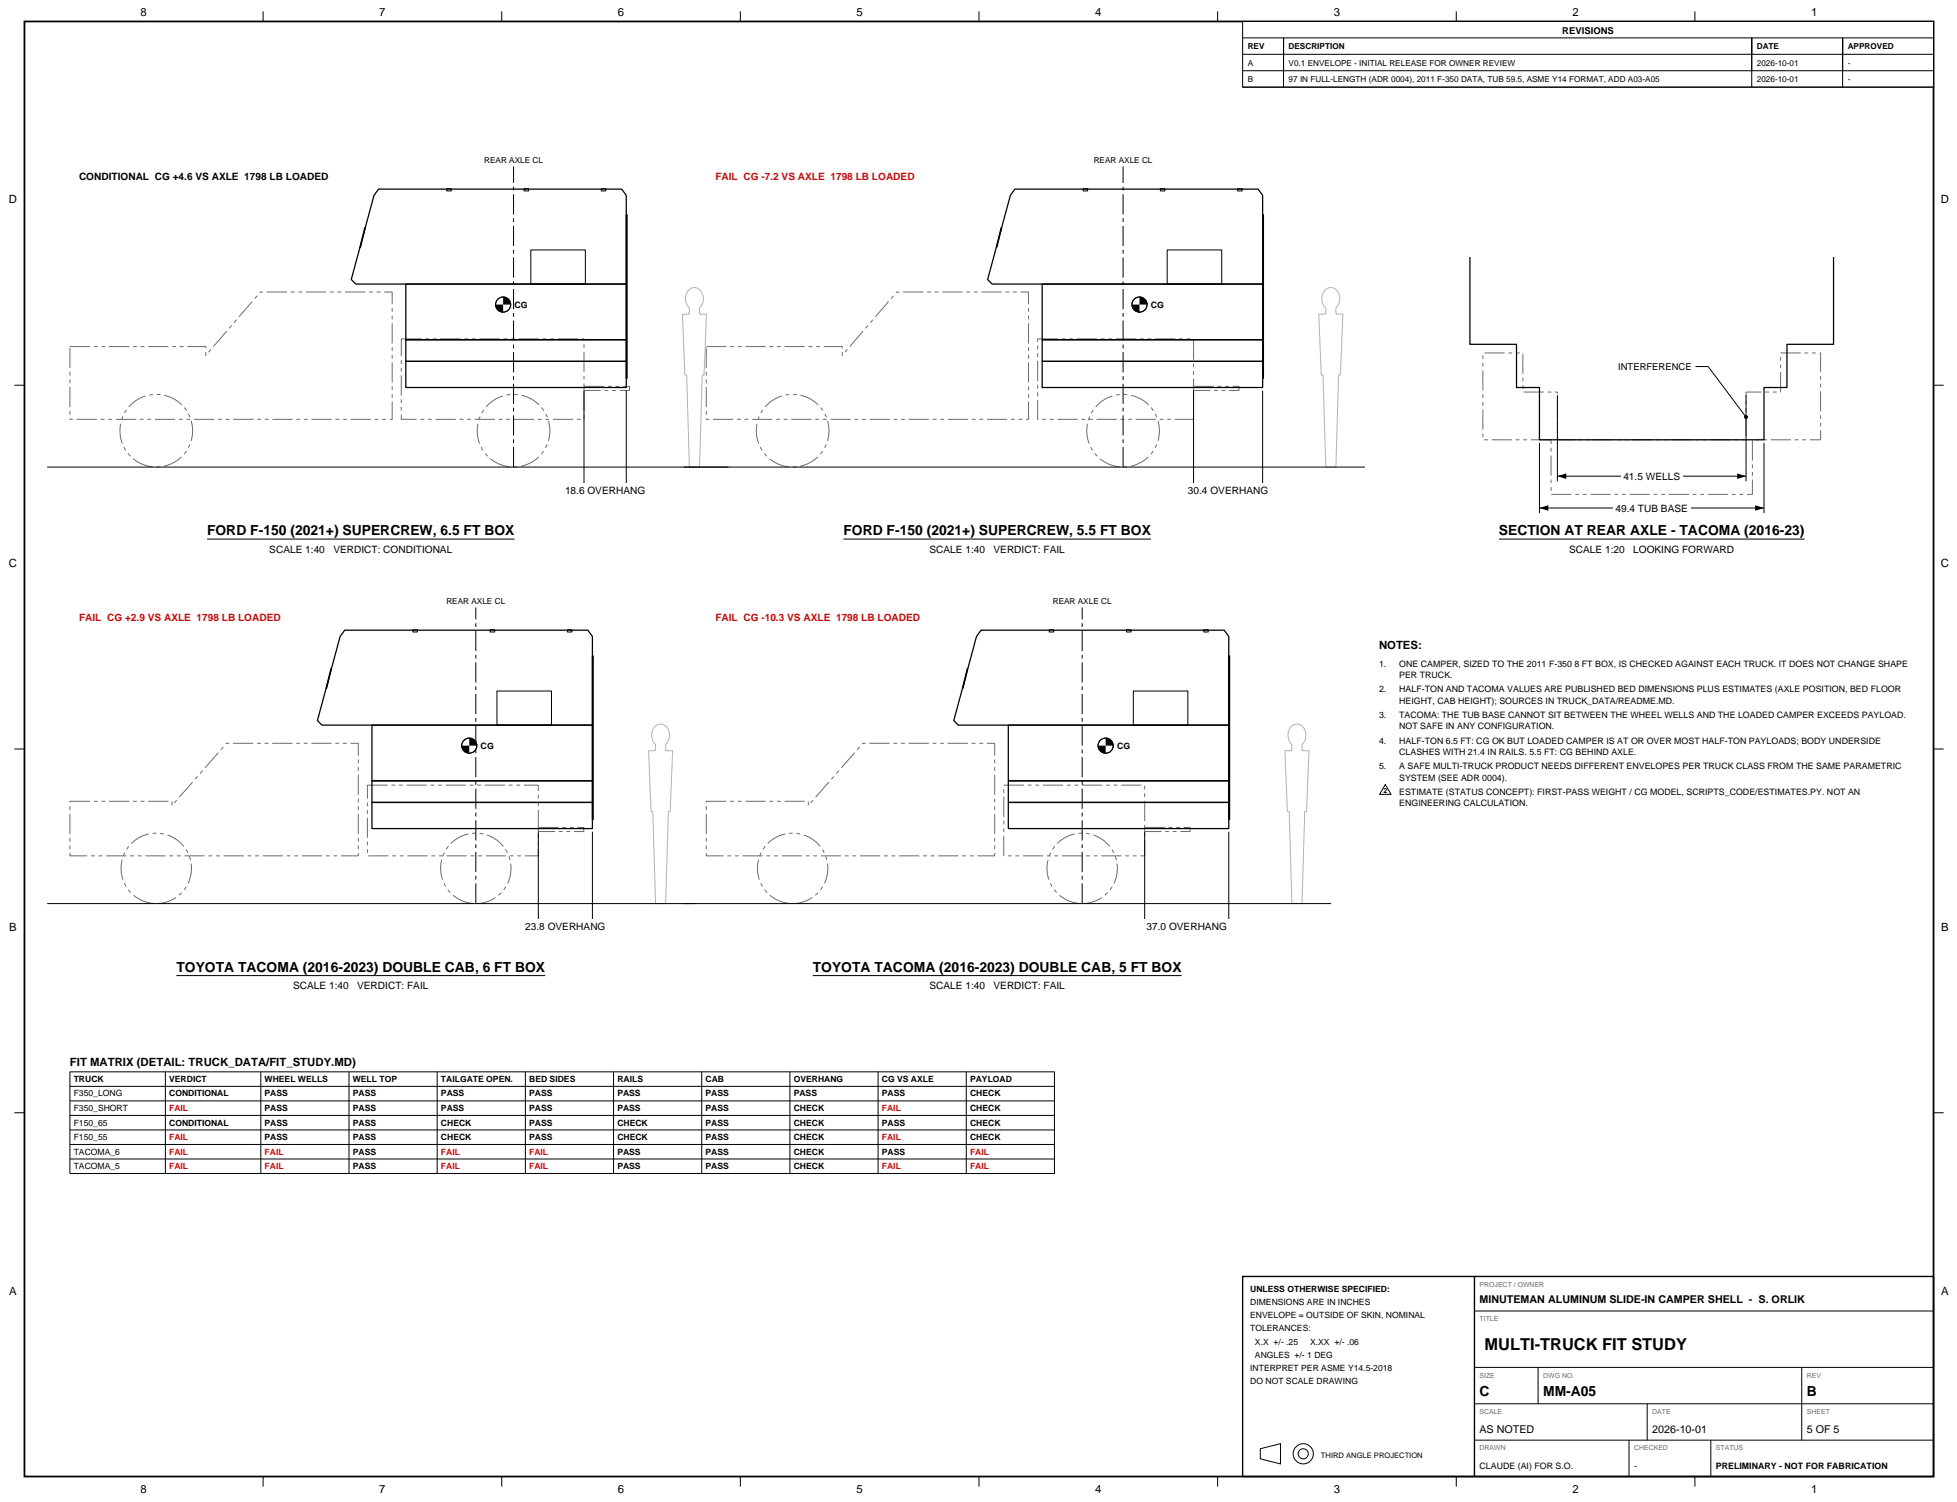
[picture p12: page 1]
SIZE C; DWG NO. MM-A05; REV B; SCALE AS NOTED; DATE 2026-10-01; SHEET; CHECKED; REVISIONS; REV; DESCRIPTION; DATE; APPROVED; V0.1 ENVELOPE - INITIAL RELEASE FOR OWNER REVIEW; 97 IN FULL-LENGTH (ADR 0004), 2011 F-350 DATA, TUB 59.5, ASME Y14 FORMAT, ADD A03-A05; 18.6 OVERHANG; 30.4 OVERHANG; 23.8 OVERHANG; 37.0 OVERHANG; 41.5 WELLS; 49.4 TUB BASE; INTERFERENCE; TRUCK; VERDICT; WHEEL WELLS; WELL TOP; TAILGATE OPEN.; BED SIDES; RAILS; CAB; OVERHANG; CG VS AXLE; PAYLOAD; F350_LONG; CONDITIONAL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

REAR AXLE CL

CONDITIONAL CG +4.6 VS AXLE 1798 LB LOADED

FAIL CG -7.2 VS AXLE 1798 LB LOADED

FORD F-150 (2021+) SUPERCREW, 6.5 FT BOX

FORD F-150 (2021+) SUPERCREW, 5.5 FT BOX

SECTION AT REAR AXLE - TACOMA (2016-23)

SCALE 1:40 VERDICT: CONDITIONAL

SCALE 1:40 VERDICT: FAIL

SCALE 1:20 LOOKING FORWARD

FAIL CG +2.9 VS AXLE 1798 LB LOADED

FAIL CG -10.3 VS AXLE 1798 LB LOADED

1. ONE CAMPER, SIZED TO THE 2011 F-350 8 FT BOX, IS CHECKED AGAINST EACH TRUCK. IT DOES NOT CHANGE SHAPE
PER TRUCK.
2. HALF-TON AND TACOMA VALUES ARE PUBLISHED BED DIMENSIONS PLUS ESTIMATES (AXLE POSITION, BED FLOOR
HEIGHT, CAB HEIGHT); SOURCES IN TRUCK_DATA/README.MD.
3. TACOMA: THE TUB BASE CANNOT SIT BETWEEN THE WHEEL WELLS AND THE LOADED CAMPER EXCEEDS PAYLOAD.
NOT SAFE IN ANY CONFIGURATION.
4. HALF-TON 6.5 FT: CG OK BUT LOADED CAMPER IS AT OR OVER MOST HALF-TON PAYLOADS; BODY UNDERSIDE
CLASHES WITH 21.4 IN RAILS. 5.5 FT: CG BEHIND AXLE.
5. A SAFE MULTI-TRUCK PRODUCT NEEDS DIFFERENT ENVELOPES PER TRUCK CLASS FROM THE SAME PARAMETRIC
SYSTEM (SEE ADR 0004).
2 ESTIMATE (STATUS CONCEPT): FIRST-PASS WEIGHT / CG MODEL, SCRIPTS_CODE/ESTIMATES.PY. NOT AN
ENGINEERING CALCULATION.

TOYOTA TACOMA (2016-2023) DOUBLE CAB, 6 FT BOX

TOYOTA TACOMA (2016-2023) DOUBLE CAB, 5 FT BOX

FIT MATRIX (DETAIL: TRUCK_DATA/FIT_STUDY.MD)

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

PROJECT / OWNER
MINUTEMAN ALUMINUM SLIDE-IN CAMPER SHELL - S. ORLIK

TITLE
MULTI-TRUCK FIT STUDY

DRAWN
CLAUDE (AI) FOR S.O.

STATUS
PRELIMINARY - NOT FOR FABRICATION

THIRD ANGLE PROJECTION

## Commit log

2026-10-01 v0.1: config architecture, envelope model, parts registry, 12 renderings
    - dimensions.json master config -> generated dimensions.scad (sync_config.py)
    - Envelope: stepped lower tub, 80in body, raked 24in nose, crowned roof
    - Truck reference (short/long bed), door/window/rail/boss placeholders, 6'7" figure
    - echo()-based parts registry -> parts.json; render_all fails on any OpenSCAD warning
    - ADRs 0001-0003
    [build_variant.scad, camper_envelope.scad, dimensions.scad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]
2026-10-01 v0.1: drawings A01-A03, reports, validator, measurement sheet, docs
    - export_drawings.py: A01 GA, A02 major dimensions, A03 truck fit (OpenSCAD projections + config dims, VOT tags)
    - BOM, extrusion/sheet cut lists, weight and cost reports with interior-height sensitivity
    - validate_model.py: 57 checks (IDs, welded min wall, statuses, truck-fit geometry)
    - Generated DIMENSIONS.md and printable F-350 measurement sheet (PDF with diagrams M1-M5)
    - Product vision, engineering assumptions/load paths/questions, sourced competitor research,
    time/cost, business outlook, manual skeleton
    [build_variant.scad, comparison_matrix.csv, extrusion_cutlist.csv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]
2026-10-02 v0.1 rev B: 97 in full-length camper, 2011 F-350 data, multi-truck fit study, ASME-style drawings
    - ADR 0004: lower length 97 in fills the 8 ft bed with tailgate closed; DESIGN_TRUCK = 2011 F-350 8 ft
    - Truck data from Ford 2011 RV & Trailer Towing Guide (wheelbases, camper cargo ratings, tailgate height)
    - Truck variants F-350 8/6.75 ft, F-150 6.5/5.5 ft, Tacoma 6/5 ft; tailgate closed/down model
    - CG estimate from envelope face centroids; fit study: 6.75 ft F-350 (CG 8.3 in behind axle),
    F-150 5.5 ft and Tacoma fail; F-150 6.5 ft marginal on payload
    - Drawings MM-A01..A05 on ANSI C per ASME Y14.1/.2/.3/.5/.35 conventions (title + revision blocks,
    zones, phantom truck, section views, fl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
    [build_variant.scad, comparison_matrix.csv, dimensions.scad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]
